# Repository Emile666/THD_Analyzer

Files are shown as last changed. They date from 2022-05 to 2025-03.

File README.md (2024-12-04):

# Bob Cordell's THD Analyzer
Bob Cordell created a series of articles in Audio Magazine, from July to September 1981 (!). In these articles, he described
in detail how to build a Total Harmonic Distortion (THD) Analyzer. I first heard of Bob Cordell, when I bought his book called "Designing Audio Power Amplifiers". 
I have never seen such an excellent written book about designing audio power amplifiers before, especially the first few chapters on continually improving a basic design 
to a high-end audio amplifier impressed me. I used the knowledge gained from his book as a base for teaching analog electronics for 3rd grade students Electrical Engineering.

I was also deeply impressed by the wealth of information in these articles and decided to build such a THD Analyzer myself. Bob
used some custom made switches with lots of decks to do the actual switching. Over the years I managed to find and construct these
switches, made some custom PCBs, created a nice front-end display and had my way of creating an implementation. As of today, this is
still work in progress.

Meanwhile, I decided to build another version of this THD Analyzer, which you will find on this page. It is the same
THD Analyzer, but now controlled by relays and a STM8S105C6 microcontroller. Such an implementation was discussed on the diyaudio forum
where someone called Giulianodes created another version where you would still need switches, but most switching was now done by relays.

His PCBs were very helpful in constructing this version of the THD Analyzer. Most ideas here are not mine, but originated from Bob Cordell
and from Giulianodes' PCB implementation.

I wanted to construct a THD Analyzer that was completely digital, while maintaining the original quality from Bob's design. 
I wanted 7-segment displays (SSD) for voltages, frequency and distortion (instead of an analog meter).
I also wanted to control all settings with keys and a LCD-display. I wanted an UART interface with commands, so I could do unit-testing of the boards.
And switching of all resistors and capacitors should also be done by relays. To conveniently read values from the SSDs, I also added LEDs for Hz or kHz, dB or % and Vpeak or Vrms.

In the end, I created five PCBs, one for each original PCB from Bob, one for the power-supply and one for the microcontroller itself. They are connected with flat-cable connectors.
Every PCB has the original analog design from Bob together with added relays. These relays are controlled by shift-registers, so off-board IO is very limited.
The microcontroller controls the shift-registers on every board and thus every single relay on these boards.

I decided to use the G6K-2F-Y relay for a few reasons: they are small, they are cheap and they are readily available (30 pcs for €26 on AliExpress). I also used the +12V
version, because current is limited (9.1 mA) and +12V can be made from the existing +15V DC. There are two switches present in every relay, which is very convenient.

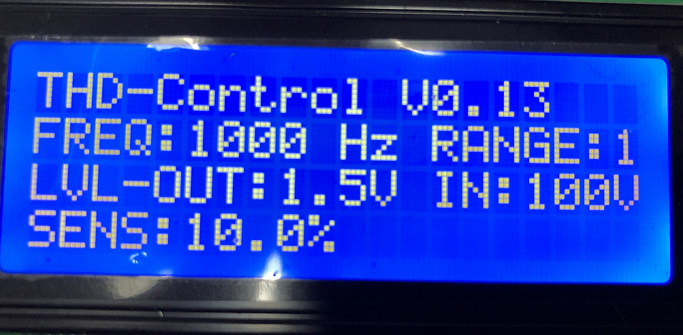
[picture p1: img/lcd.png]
LCD-Display during development testing
<br>
*LCD-Display showing actual settings*

# Features
The current PCB and firmware have the following features:
- Four Seven-Segment-Displays (SSD) displaying 1) Output Level, in peak-peak, peak or RMS voltage 2) Display of actual frequency, as measured by the microcontroller 3) Distortion level in dB or as a percentage 4) Input Level in peak-peak, peak or RMS voltage
- LCD display displaying actual settings
- Five buttons UP, DOWN, LEFT, RIGHT and OK for changing settings shown on the LCD-display. There are four more buttons for going up/down 10 frequency steps and for setting peak-peak, peak or RMS voltages and dB or percentage.
- Main output, Sync Output, Input and Distortion Output (same as in original design)
- Level Output potmeter (same as in original design)
- Four LEDs showing frequency too high/too low and input level too high/too low (same as in original design)
- All components are SMD where possible.

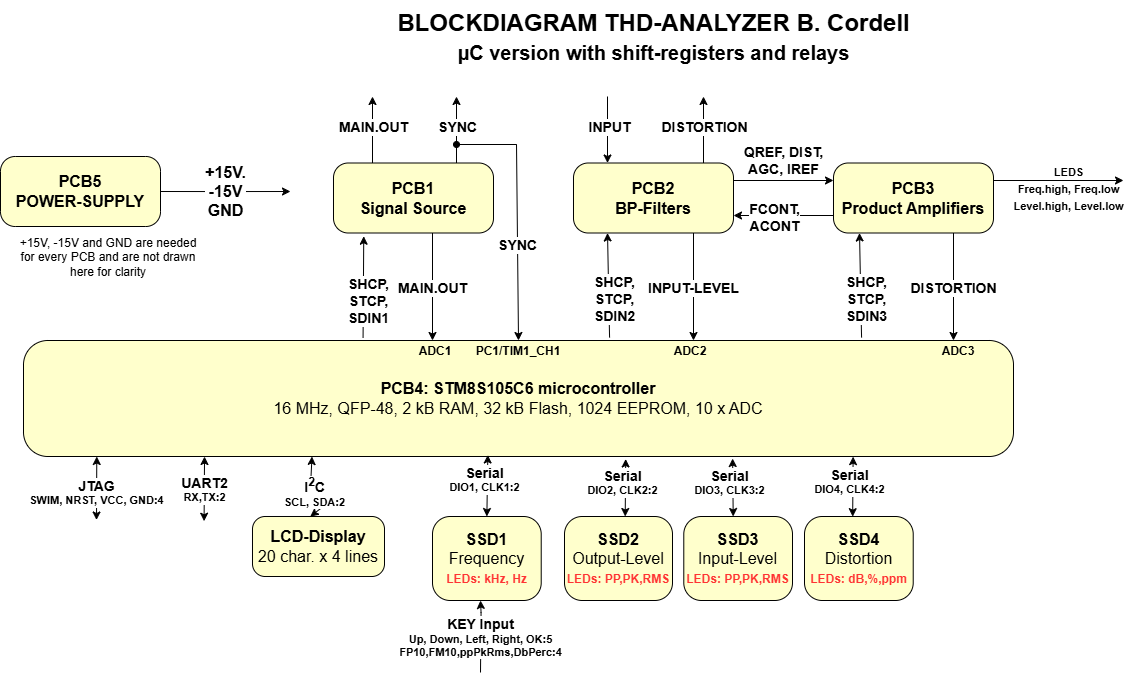
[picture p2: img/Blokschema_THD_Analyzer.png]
Block Diagram
<br>
*Block-Diagram THD-Analyzer*

A frontpanel has also been made and this is quite different from Bob's design. The LCD-display is central to the design and is surrounded by four seven-segment displays. All red-lines are hairlines and will be cut out by the laser. The frontpanel dimensions are 432 x 102 mm and is meant for a Hammond 1441-40 chassis.

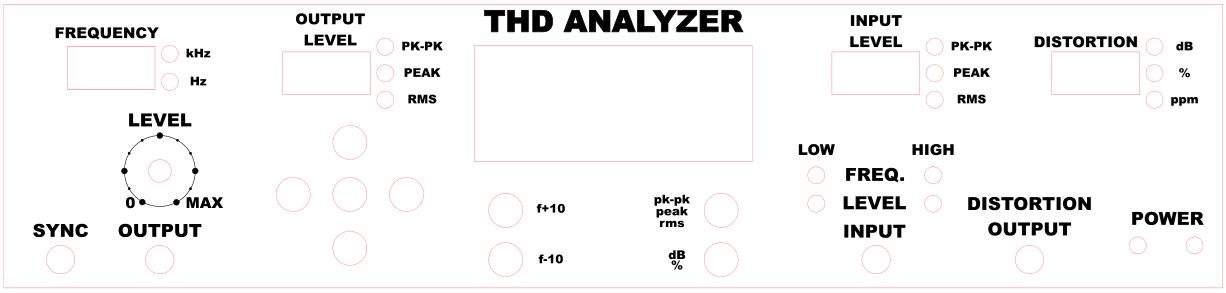
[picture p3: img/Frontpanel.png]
Frontpanel
<br>
*Frontpanel design for the THD-Analyzer*

# PCB 1: Signal Generator
This was the Signal Source PCB1 from Bob's original design. Design details and engineering design files (schematics, PCB-layout, Gerber-files) are found on the [PCB1](./pcb1.md) page.

# PCB 2: Bandpass Filters and Product Amplifier and Level Set

PCB2 contained the voltage controlled bandpass-filters and the product-amplifiers. Design details and engineering design files (schematics, PCB-layout, Gerber-files) are found on the [PCB2](./pcb2.md) page.

# PCB 3: Amplitude and Frequency Detectors and Filter and Meter circuits

PCB3 contained the Amplitude and Frequency detectors and the Filter and Meter circuits. Design details and engineering design files (schematics, PCB-layout) are found on the [PCB3](./pcb3.md) page.

# PCB 4: Microcontroller PCB
This is a newly designed PCB and was not in Bob's original design. It contains a SMT8S105 microcontroller and it is the control unit for the entire project. This board uses flat-cables to send and receive all signals from PCB1 to PCB3.

I chose the STM8S105, because I have substantial experience with these devices and they are easy to get operational, both hardware and software (especially if you have a large code-base of other projects available). The 8-bit core runs on 16 MHz and is 
powerful enough to control this project. It also has sufficient IO (I use the LQPF-48 package) for what I needed.

Design details (source-code structure, description of user-interface) and engineering design files (schematics, PCB-layout) are found on the [PCB4](./pcb4.md) page.

# PCB 5: Power-Supply
This is a newly designed PCB by bengtssk, who did a wonderful job creating a low-noise power-supply for all boards of this project.

Design details and engineering design files (schematics, PCB-layout) are found on the [PCB5](./pcb5.md) page.

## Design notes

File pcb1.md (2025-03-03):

# PCB1 Top-layer layout
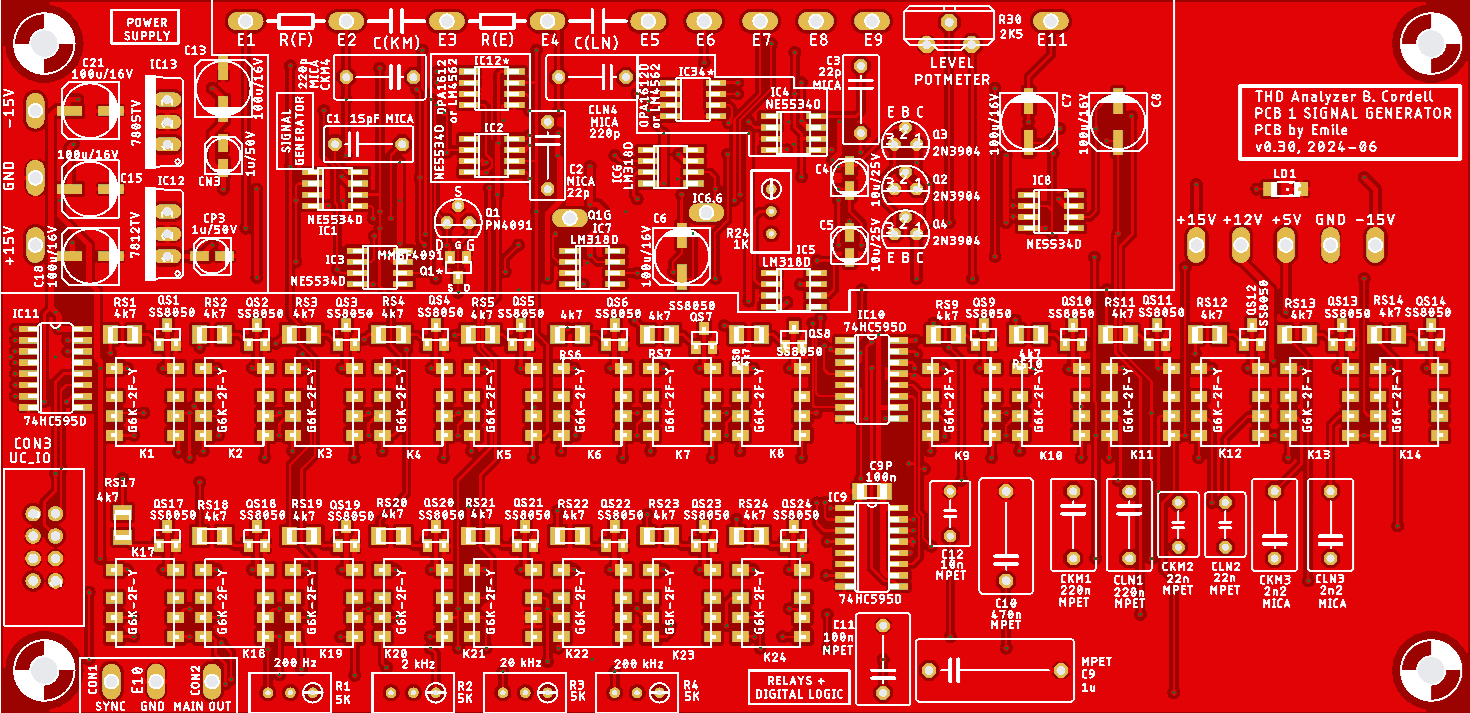
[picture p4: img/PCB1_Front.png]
PCB1 Layout top-layer
<br>
*PCB1 Top-layer Layout*

The PCBs were created with Eagle v9.3.2. The PCB itself is a double layer PCB with most components being SMD. Only a few capacitors, specified by Bob as being silver-mica or polyester, are through-hole.

# PCB1 Schematics
The schematics consists of three sheets:
- Sheet 1: the signal generator
- Sheet 2: the relays and the digital logic
- Sheet 3: the power-supply

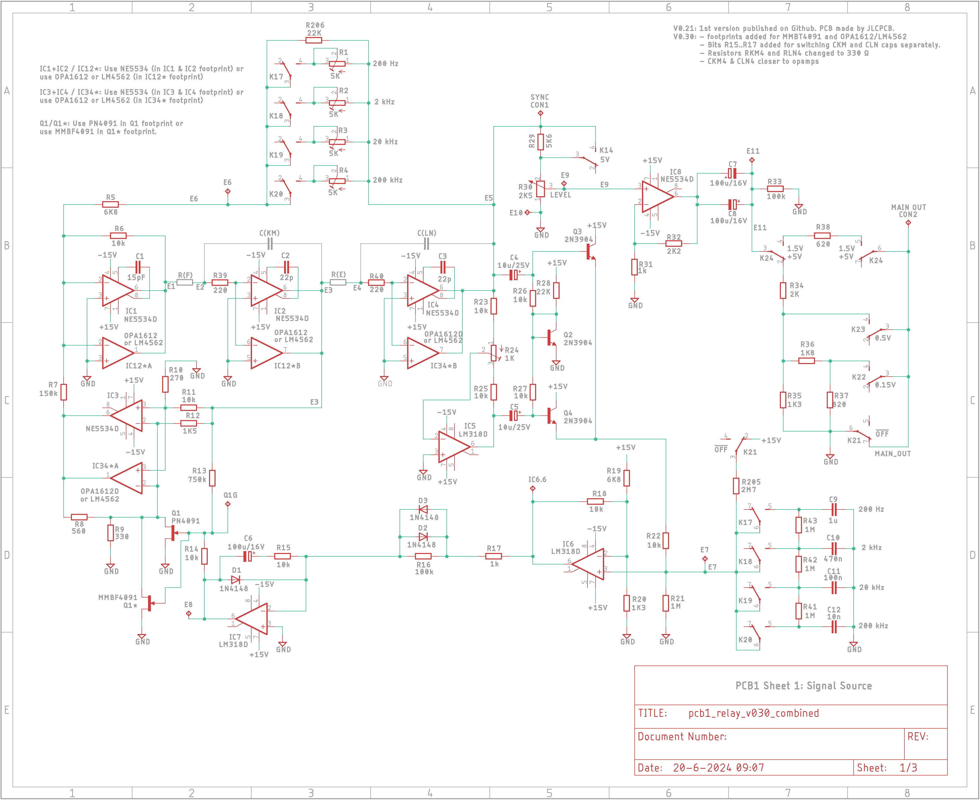
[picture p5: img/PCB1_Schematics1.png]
PCB1 Sheet 1 Schematic
<br>
*PCB1 Sheet 1: signal generator*

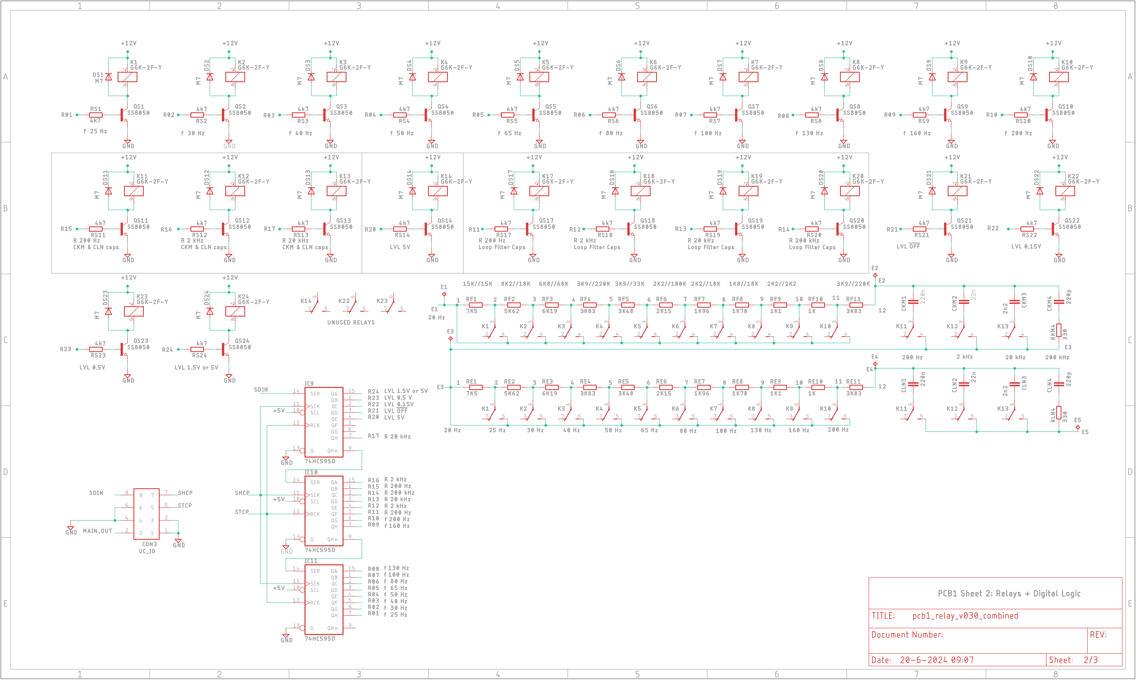
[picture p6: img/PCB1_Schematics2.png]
PCB1 Sheet 2 Schematic
<br>
*PCB1 Sheet 2: relays and digital logic*

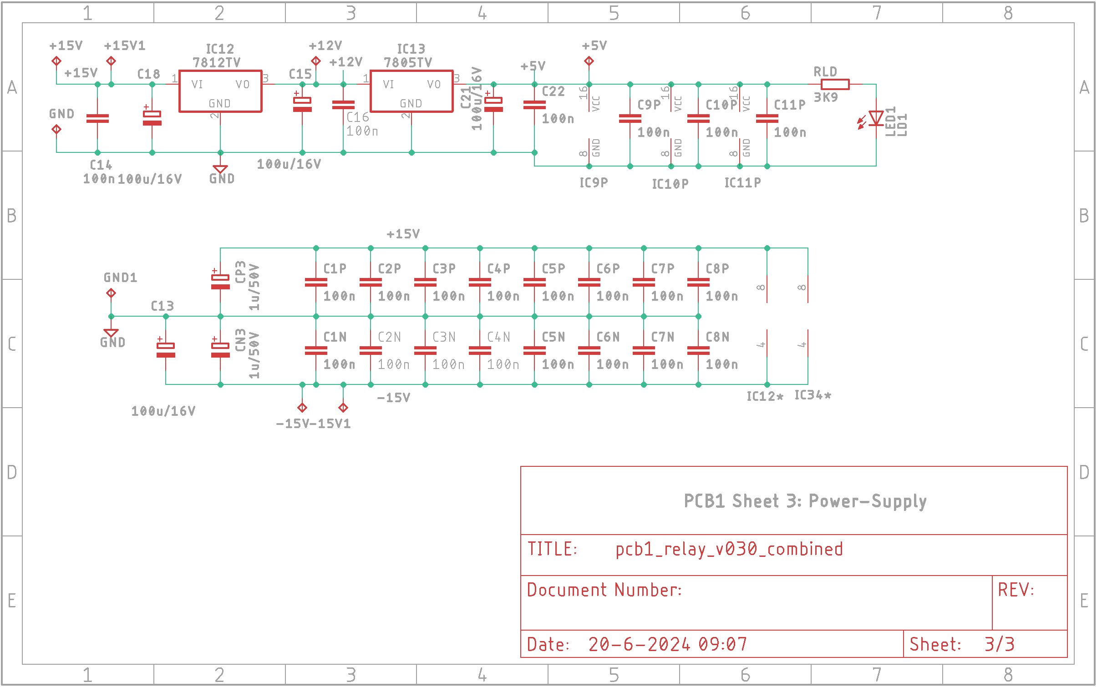
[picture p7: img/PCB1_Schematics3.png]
PCB1 Sheet 3 Schematic
<br>
*PCB1 Sheet 3: power-supply*

# Design-details
I named the bits from the HC595 shift-registers R01-R24 (R15 and R16 are not connected), with R01 being the first bit to shift into the shift-registers. They have the following meaning:
- R01: f=25 Hz to R10: f=200 Hz. For f=20 Hz all bits (R01-R10) need to be 0.
- R11: Range = 200 Hz, R12: Range = 2 kHz, R13: Range is 20 kHz. R14: Range is 200 kHz.
- PCB1 V0.30 only: R15: Range = 200 Hz, R16: Range = 2 kHz, R17: Range is 20 kHz.
- PCB1 V0.21 only: R15 until R19: these bits are not used.
- PCB1 V0.30 only: R18 and R19 are not used.
- R20: Output Level is 5 V.
- R21: Output Level if not OFF.
- R22: Output Level is 0.15 V.
- R23: Output Level is 0.5 V.
- R24: Output Level is 1.5 V or 5 V.

The MAIN.OUT signal is also sent to the microcontroller (via CON3) for both frequency and level measurement.

# SYNC MOD
This modification applies to PCB1 v0.30. The frequency-counter (a software function) gets its signal from an amplified sine-wave. This does work, but reliability is higher when the SYNC signal is used for this. The SYNC signal comes from this PCB and is sent to the uC PCB (PCB4) via CON3.

For PCB1, do the following:
- Desolder CON3 (UC_IO) box-header
- Use a sharp knife to disconnect pin 1 (bottom right pin as seen from top-layer) from GND on top-layer. There are 3 connections to GND, remove all three of them.
- Same for the 3 connections to GND on the bottom-layer.
- Check for discontinuity between GND and CON3-1 pin.
- Solder CON3 box-header back.
- Solder wire from CON1-SYNC pin to CON3-1.
- Check for discontinuity between GND and CON3-1 pin.
- In order for this mod to work, check the SYNC MOD paragraph on PCB4 too.

# PCB1 Unit-testing
Bob describes some bench-testing in his article. Since the PCB is now tested slightly different from Bob's original article, I created unit-test documents that use the microcontroller board (PCB4). This unit-test facilitates testing of PCB1. I have added both the unit-test document itself as well as a filled-in version of a test I performed. This is a good reference if you do your own unit-testing.

[PCB1 Unit-Test description](img/PCB1_Unit_Test.pdf)<br>

[PCB1 Unit-Test description filled-in](img/PCB1_Unit_Test_filled_in.pdf)<br>

In order to test this, a working PCB4 (µC control board) is needed. PCB4 should be connected to a host-PC with an USB-to-UART adapter, communication settings are 57600,N,8,1. See the [PCB4](./pcb4.md) page for details.

# Eagle source-files
Not to be used for commercial purposes!
This is the .zip file containing the Eagle source-files: [PCB1 Eagle Files](img/PCB1_Eagle.zip)

# Gerber-Files
This is the .zip file containing the Gerber files that were sent to JLCPCB: [PCB1 Gerber Files](img/pcb1_relay_v030_combined_2024-07-10.zip)

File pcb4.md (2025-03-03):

# PCB4 Engineering Design Files
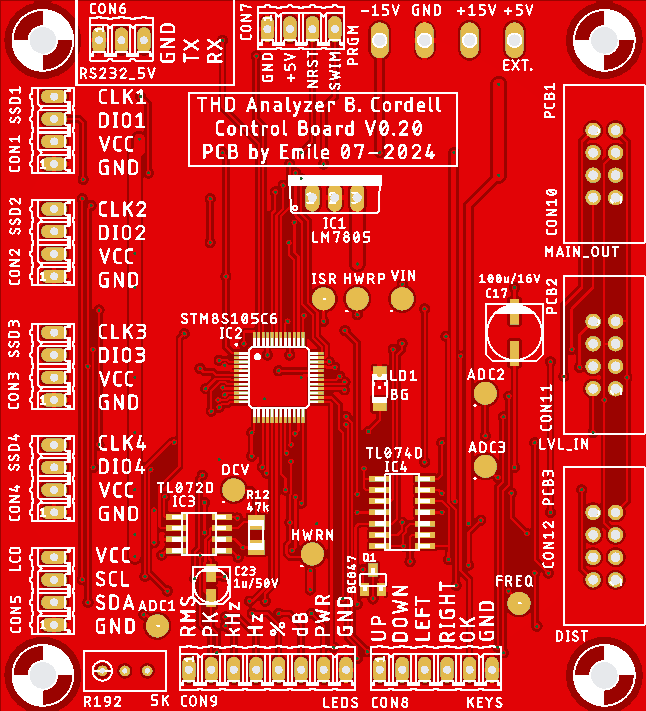
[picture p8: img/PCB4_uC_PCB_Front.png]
PCB4 Layout top-layer
<br>
*PCB4 Top-layer Layout*

The PCBs were created with Eagle v9.3.2.

# PCB4 Schematics
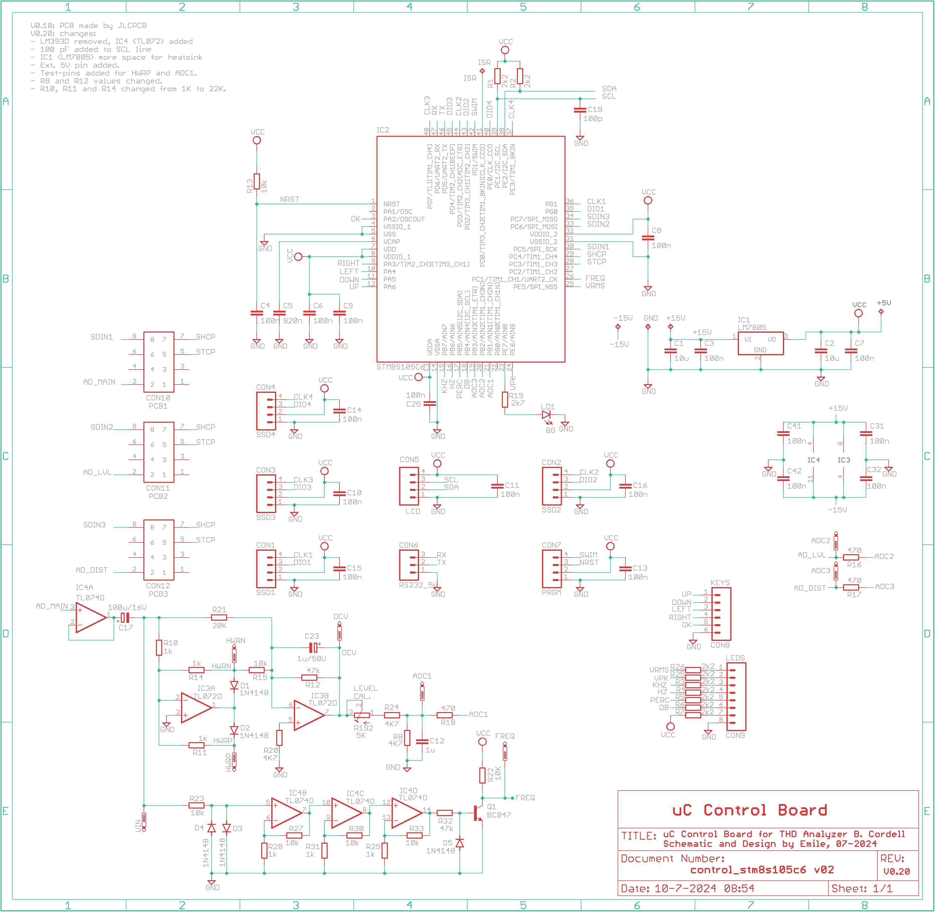
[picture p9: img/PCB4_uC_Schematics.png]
PCB4 Schematics
<br>
*PCB4 microcontroller Control-Board Schematics*

The PCB itself is a double layer PCB with most components being SMD. Some details:
- CON1, CON2, CON3 and CON4 are screw terminal-blocks for the Seven Segment Displays (SSD). CON1 shows the selected frequency, CON2 the selected output level (OFF, 0.15V, 0.5V, 1.5V and 5V), CON3 the selected distortion level (0.003%, 0.01%, 0.03%, 0.1%, 0.3%, 1%, 3% and 10%) and CON4 the selected input level (1V, 3V, 10V, 30V and 100V).
- CON5 is also a screw terminal-block, but for the I2C LCD-Display.
- CON6 is the UART interface. Note that signal levels are 5 V.
- CON7 is the JTAG programming interface, that needs to be connected to an ST-Link V2 USB adapter (see below) in order to program the microcontroller.
- CON8 contains the input key connections.
- CON9 contains all LED connections for the front-panel.
- CON10, CON11 and CON12 are flat-cable connectors that interface with PCB1, PCB2 and PCB3 respectively. They contain the signals for the shift-registers and the analog signals MAIN.OUT, DIST and LEVEL.

# Design-details
This PCB more or less copies the full-wave precision rectifier as found on PCB3. I wanted to have the MAIN.OUT signal from PCB1 measured in both amplitude and frequency. The amplitude is rectified to a DC-level and sent to ADC1, the
frequency is measured by amplifying the sine-wave into a square-wave and then send it to a timer-input (TIM1_CH1) to capture the period-time.

# SYNC MOD
This modification applies to PCB4 v0.20. The frequency-counter (a software function) gets its signal from an amplified sine-wave. This does work, but reliability is higher when the SYNC signal is used for this. The SYNC signal comes from PCB1 (and needs a modification too!) via CON3.

For PCB4, do the following:
- Desolder IC4 pin 14 from its pad and lift it up.
- Solder a wire from CON10-1 (bottom right pin as seen from top-layer, pin next to AD_MAIN pin) to R33 pad next to R32. R32 and R33 are located next to each other, solder the wire to one of the pads in the middle.
- In order for this mod to work, check the SYNC MOD paragraph on PCB1 too.

### GPIO
The GPIO pin lay-out as shown in the schematic is copied in the header-file stm8_hw_init.h and used throughout the project. GPIO pins are initialized in the function setup_gpio_ports() in stm8_hw_init.c.

### Peripherals
I decided not to use the internal I2C module, since it is overly complicated and troublesome to get to work. Good old bit-banging is used instead, see files i2c_bb.c and i2c_bb.h. The ADC (adc.c, adc.h), eeprom (eep.c, eep.h) and UART (uart.c, uart.h) routines are pretty standard.

The UART commands are defined in comms.c/comms.h in the function execute_single_command(). The UART functions itself are interrupt-driven and they use ringbuffers to store and retrieve communication.

### UART communications
- Use PCB4 connector 6 (CON6, RS232.5V) for serial communications to a host-PC.
- Communication settings are 57600 Baud, no parity, 8 bits, 1 stop-bit (57600,N,8,1).
- Use an USB-to-UART adapter and connect the following signals: GND to CON6_GND, TXD to CON6_RX and RDX to CON6_TX. In Windows a virtual COM port is added to the device list when this adapter is added.
- CON6 uses 5V levels, so set the USB-to-serial adapter to accept 5 Volt levels.
- Use Realterm (or any other communication program) on the host-PC for sending and receiving data to/from PCB4. Make sure that a CR and a LF are added to the command-string when sending.
- Make sure that you get a USB-to-UART adapter and not an USB-to-RS232 adapter, because voltage-levels are 0-5 Volt only (RS232 is typical +6V and -6V and will not work with CON6).

To test communications, enter the command 's0', make sure that CR and LF are sent as well and send it to the PCB4 control-board. Typically it should respond with a string like 'THD-Control V0.25'. Besides s0, the following commands are also available:
- c0 or c0 <float> with <float> being a floating-point value. The c0 parameter defines the 100 V input-level and is by default set to 32.645570, which is equal to 1+(R48/R49). If you just type c0, the currently stored value is displayed. Change this parameter to get a correct reading of the input-level on SSD3 for the 100V input setting. This value is stored in eeprom, so the value remains set after a power-cycle.
- c1 or c1 <float>: same as c0 but for the 30V input-level reading. Equal to 1+(R46/R47).
- c2 or c2 <float>: same as c0 but for the 10V input-level reading. Equal to 1+(R44/R45).
- c3 or c3 <float>: same as c0 but for the 3V input-level reading. Equal to 1.0, because this is a pass-through.
- c4 or c4 <float>: same as c0 but for the 1V input-level reading. Equal to R51/(R51+R52).
- a0, a1 or a2: set amplitude-level to Vrms (a0), Vpeak (a1) or Vpp (a2).

### Scheduler
Furthermore, the scheduler (scheduler.c, scheduler.h) takes care of proper timing for all tasks. The add_task() routine controls timing of every task and is called from main() in THD_Analyzer_main.c. There are three tasks defined:
- adc_task(), name "ADC", called every 500 msec. This task reads the analog values from the AD-converters and stores the information on the SSDs.
- freq_task(), name "FRQ", called every 200 msec. This task calculates the actual frequency of the generated sine-wave and updates information on the LCD-display.
- ctrl_task(), name "CTL", called every 100 msec. This task reads the input-buttons and runs the state-machine. The state-machine is used to adjust settings.

### Keys
There are five keys that should be connected to CON8 (KEYS) of the uC PCB. These keys are UP, DOWN, LEFT, RIGHT and OK and are used for navigating the menu in the LCD-display.

With the start of firmware revision V0.25, it is also possible to connect these keys to connector J2 of the first TM1637 seven-segment display (the one that shows the actual frequency). Both connectors are read in by the software and if either one of these connectors show a key-press, it is handled as such. 

There are four additional keys on the frontpanel: f+10, f-10, pppkrms and dbperc, they can only be connected to connector J2 of the first TM1637 seven-segment display. They increase (fp10) or decrease (fm10) the frequency in 10-steps, they change the amplitude readings to peak-peak, peak or RMS (pppkrms) or they change the distortion unity to dB or a percentage (dbperc).

The keys should be connected to SSD connector J2 as follows:
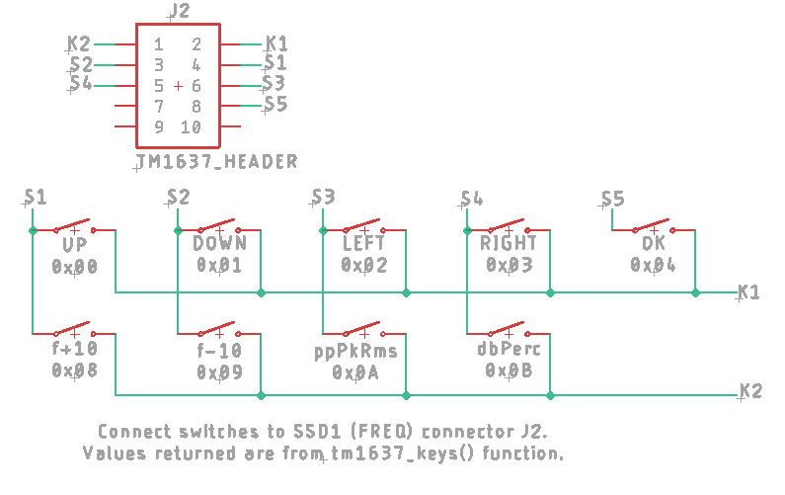
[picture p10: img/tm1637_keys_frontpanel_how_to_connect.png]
Frontpanel key connections
<br>
*How to connect the frontpanel keys*

### LCD-Display
There are separate files (i2c_lcd.c, i2c_lcd.h) for the LCD-display functions. These functions call the actual I2C-routines from i2c_bb.c/i2c_bb.h. The seven-segment display routines are listed in tm1637.c/tm1637.h.

The second, third and fourth line of the LCD-display contain the actual settings (frequency, output-level, input-level and sensitivity). They can be changed with the buttons as follows:
- UP and DOWN button are used to select a higher/lower frequency. There's is no roll-over so trying to select a lower frequency than 20 Hz keeps the frequency at 20 Hz. Same for the 200 kHz setting: trying to select a higher frequency keeps the frequency set at 200 kHz.
- LEFT and RIGHT button are used to select the various settings. The selected setting is shown on the first line of the LCD-display. You can than use the UP and DOWN buttons to change values. A value change is immediate.
- OK button brings up the parameter menu. You can change amplitude (Vpeak or Vrms) and the unit of distortion (dB or percentage). Note that this can also be done directly (from V0.25 onwards) with the keys on the frontpanel. Other parameter changes are to be defined.

### Seven-Segment Displays (SSD)
There are a total of four SSDs present in the system. The first SSD shows the actual frequency and is also used to read in a number of keys. There are separate PCBs created for the SSDs to provide better power-supply decoupling and to add a number of LEDs right next to the display. A connector is also added to connect keys to.

The seven-segment display routines are listed in tm1637.c/tm1637.h.

Bengtssk made a nice PCB for these SSDs, design details are given on the [SSD](./SSD.md) page.

# Eagle source-files
Not to be used for commercial purposes!
This is the .zip file containing the Eagle source-files: [PCB4 Eagle Files](img/PCB4_Eagle.zip)

# Gerber-Files
This is the .zip file containing the Gerber files that were sent to JLCPCB: [PCB4 Gerber Files](img/control_stm8s105c6 v02_2024-07-10.zip)

# Programming the microcontroller
To start with, you'd need one of those fancy coloured ST-Link V2 USB adapters (which are very cheap to find on ebay/Aliexpress). 
 
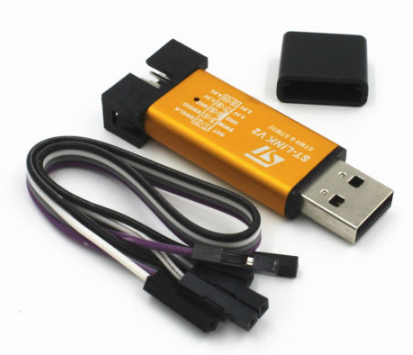
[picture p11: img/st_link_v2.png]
st-link-v2
<br>
*The ST-Link V2 USB adapter*

Power PCB4 from a ±15V dual power-supply and connect the ST-Link USB adapter without the VCC line (only SWIM, NRST and GND). Now, there are several options to program the microcontroller:

1) Use ST Visual Programmer (STVP-STM8), this can be downloaded for free. A project file for STVP is included [here](./Debug/Exe/THD_Analyzer_stm8s105.stp).

2) Use the opensource tool stm8flash.

3) Use opensource tools Code::Blocks in combination with the SDCC C compiler. A Code::Blocks project file is present (THD_Analyzer_stm8s105.cbp) that loads the entire project. You probably only need to set the SDCC home directory in Settings->Compiler..., then select Small Device C Compiler in the selected compiler field, then click Toolchain executables, then enter the compiler's installation directory and do a 'Auto-detect'. I suggest to install SDCC first and then install Code::Blocks. The toolchain creates a .hex file in Debug\ExeCB which can be uploaded with either stm8flash (preferred for Unix platforms) or STVP (on Windows).

4) Use the IAR development environment for STM8 from the IAR website. A 14-day free trial version is available.
- Open the workspace in IAR (File -> Open -> Workspace... -> THD_Analyzer_stm8s105.eww), then do a Project -> Rebuild All.
- There is a preprocessor define (USE_IAR_HEADER_FILE) that can be defined in Project->Options->C/C++ Compiler. If defined, the standard header file (<iostm8s105.h>) is used. If not defined, the file stm8s105.h is used.
- Press Ctrl-D. This opens the debugger and transfers the code to the microcontroller. 
- Press Ctrl-Shift-D to Stop Debugging. Remove the wires, re-cycle power and you are good to go!

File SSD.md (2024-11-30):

# SSD modules for displays and key scan
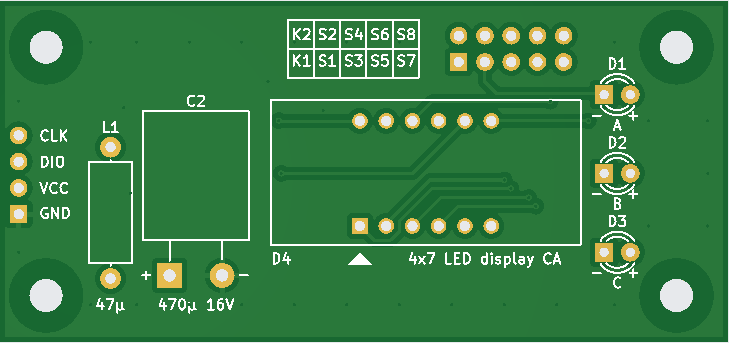
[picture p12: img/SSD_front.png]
SSD module PCB front layer
<br>
*SSD PCB front layer*

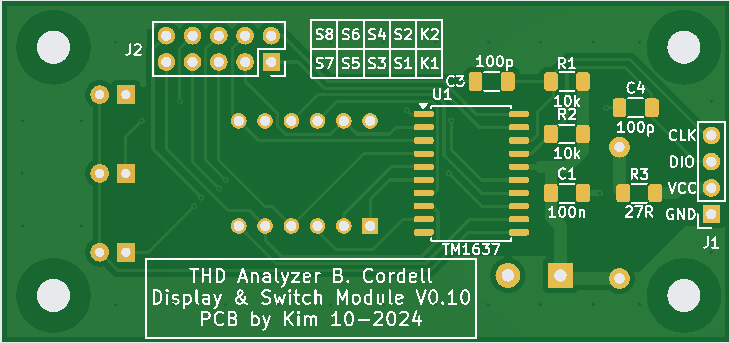
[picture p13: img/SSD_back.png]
<br>
*SSD PCB back layer*

The PCB was created using KiCad v8.0. It is a double sided PCB with a 4 digit 7-segment LED display at the front and TM1637 IC at the back. A ground-plane is used to minimize EMI transmissions from the board. Connectors J1 and J2 can be mounted on either side, depending what is most convenient. Same for the 470 µF cap, if you use a low-voltage radial cap and lay it down, it even has lower height than a SMD cap.

# SSD module Schematic
[SSD module schematic](img/SSD_schematic.pdf)<br>
*SSD module schematic*

# Design-details
In the beginning of this project it was discovered that the SSD modules caused switching spikes at the +5V rail from the multiplexing of the LED displays. These voltages spikes did not only cause the frequency counter to malfunction, but also increased the residual distortion, making the whole instrument useless.

The original SSD modules from Ali-Express comes with only 2 µF decoupling for the TM1637 IC, while the datasheet suggests 100 µF. But even that is too low. Instead of just a capacitor, a LC-filter was added to each SSD module with good results. In order to minimize EMI being transmitted from the board or its power cables, the filter should be placed as close to the TM1637 as possible. A new PCB was designed for this purpose.

Component values of the LC filter are not very critical, the values were determined by experiment. The series resistor improves the performance significantly.

Indicator LEDs for Hz, kHz etc. are now included on the board (LED A, B and C) and controlled by the TM1637 as well. Note that some boards only use LED's A and C. In this case do not populate LED B.

Since the TM1637 also features a key scan option, connector J2 was added for connecting keys. See the [Keys](./pcb4.md#Keys) section in [PCB4](./pcb4.md) on how to connect keys to this connector.

# Gerbers
This zip-file contains Gerbers to be sent for manufacturing:  [SSD Gerber Files](img/SSD-gerbers.zip)

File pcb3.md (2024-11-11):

# PCB3 Engineering Design Files
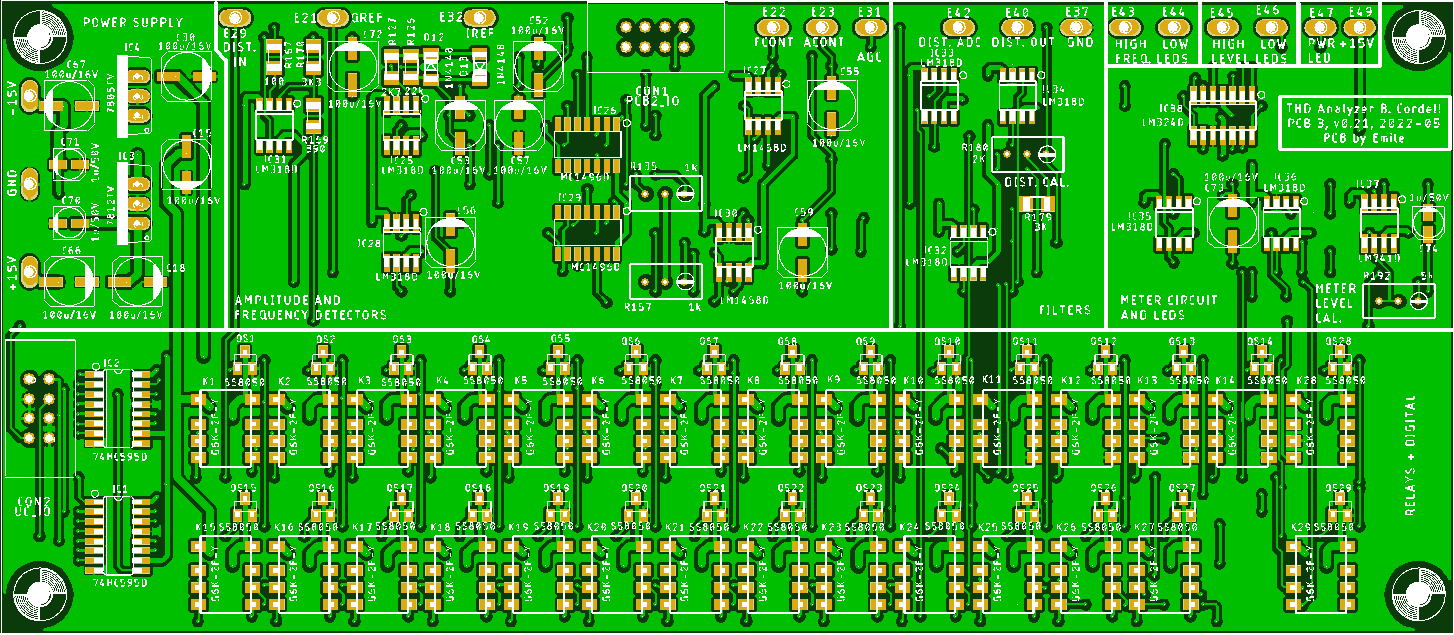
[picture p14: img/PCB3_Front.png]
PCB3 Layout top-layer
<br>
*PCB3 Top-layer Layout*

The PCBs were created with Eagle v9.3.2. The PCB itself is a double layer PCB with most components being SMD. Only a few capacitors, specified by Bob as being silver-mica or polyester, are through-hole.

# PCB3 Schematics
The schematics consists of five sheets:
- Sheet 1: the amplitude and frequency detectors
- Sheet 2: the meter and LED interface
- Sheet 3: the relays and the digital logic
- Sheet 4: the filter-circuit
- Sheet 5: the power-supply

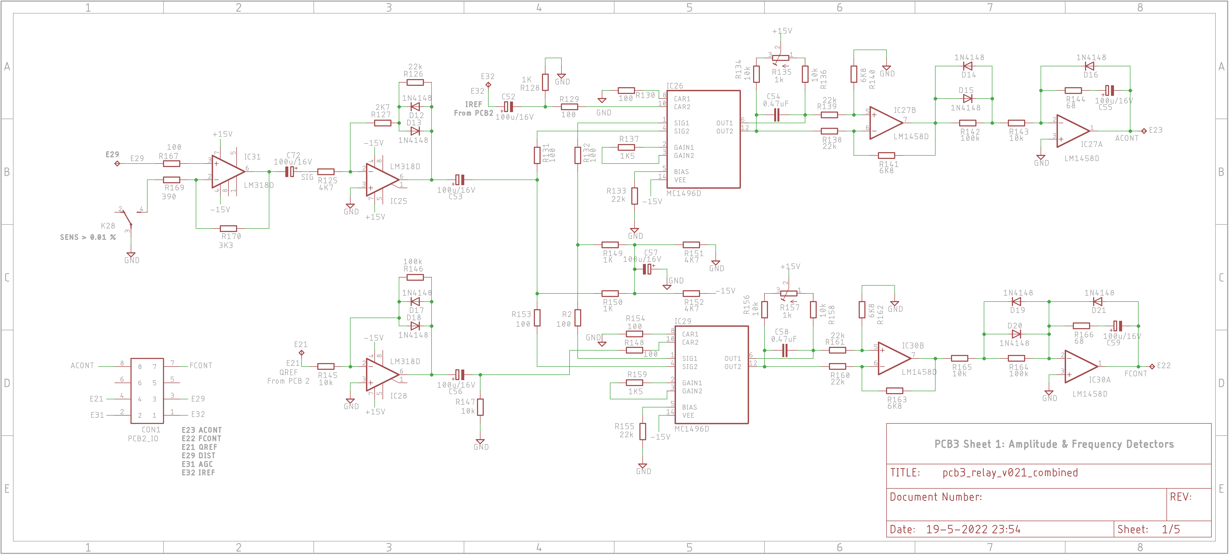
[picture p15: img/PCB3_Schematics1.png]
PCB3 Sheet 1 Schematic
<br>
*PCB3 Sheet 1: amplitude and frequency detectors*

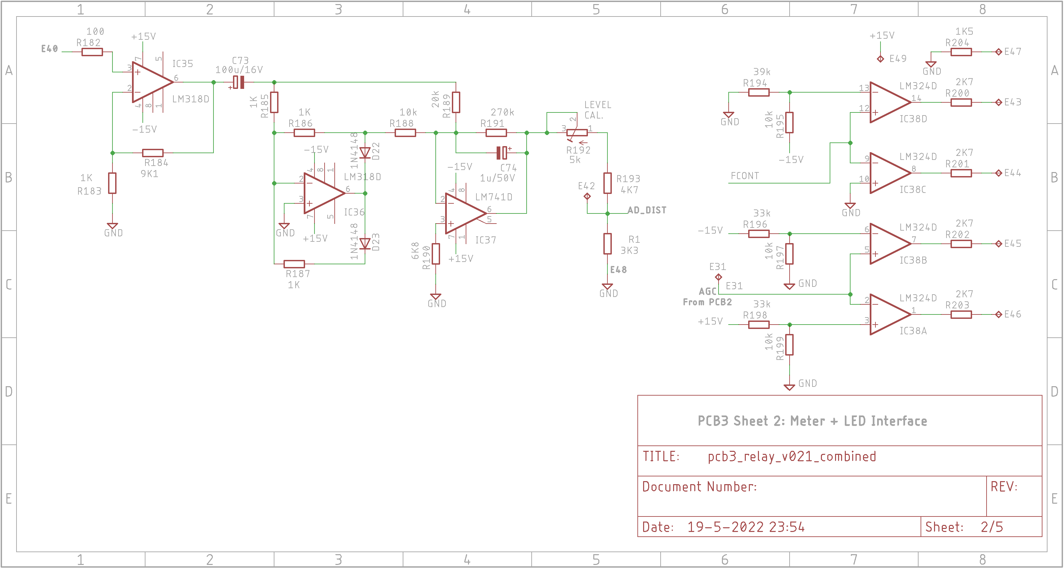
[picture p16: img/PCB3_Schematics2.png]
PCB3 Sheet 2 Schematic
<br>
*PCB3 Sheet 2: meter and LED interface*

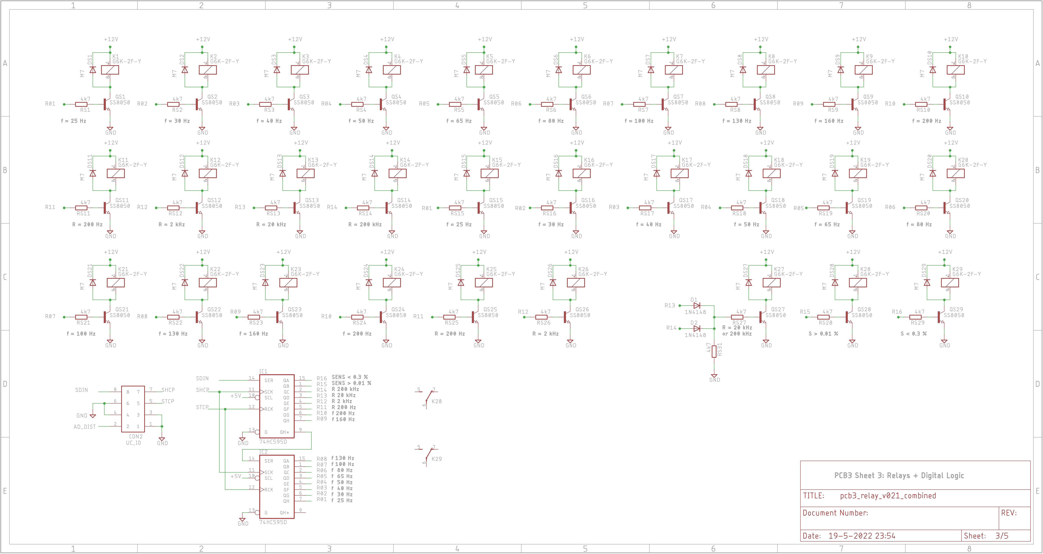
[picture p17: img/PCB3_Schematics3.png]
PCB3 Sheet 3 Schematic
<br>
*PCB3 Sheet 3: relays and digital logic*

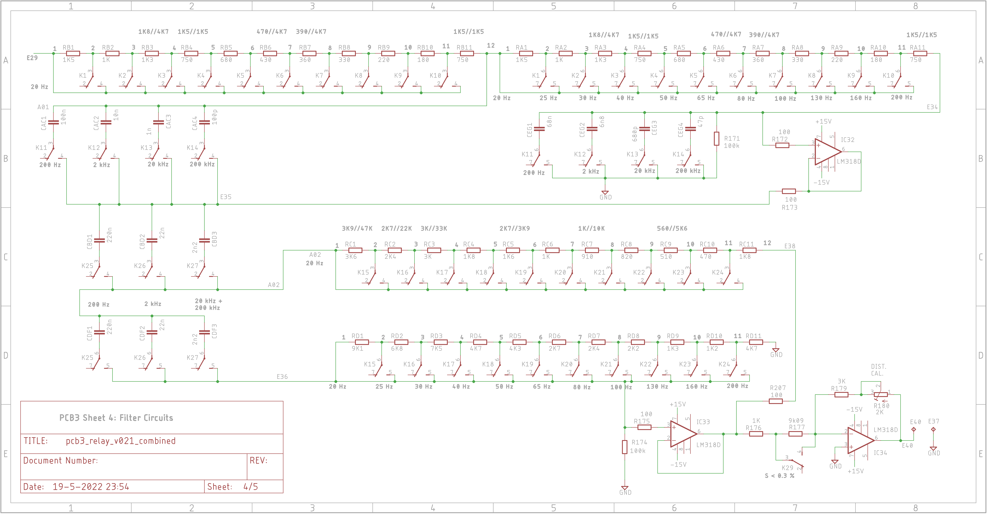
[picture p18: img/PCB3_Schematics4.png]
PCB3 Sheet 4 Schematic
<br>
*PCB3 Sheet 4: Filter-circuit*

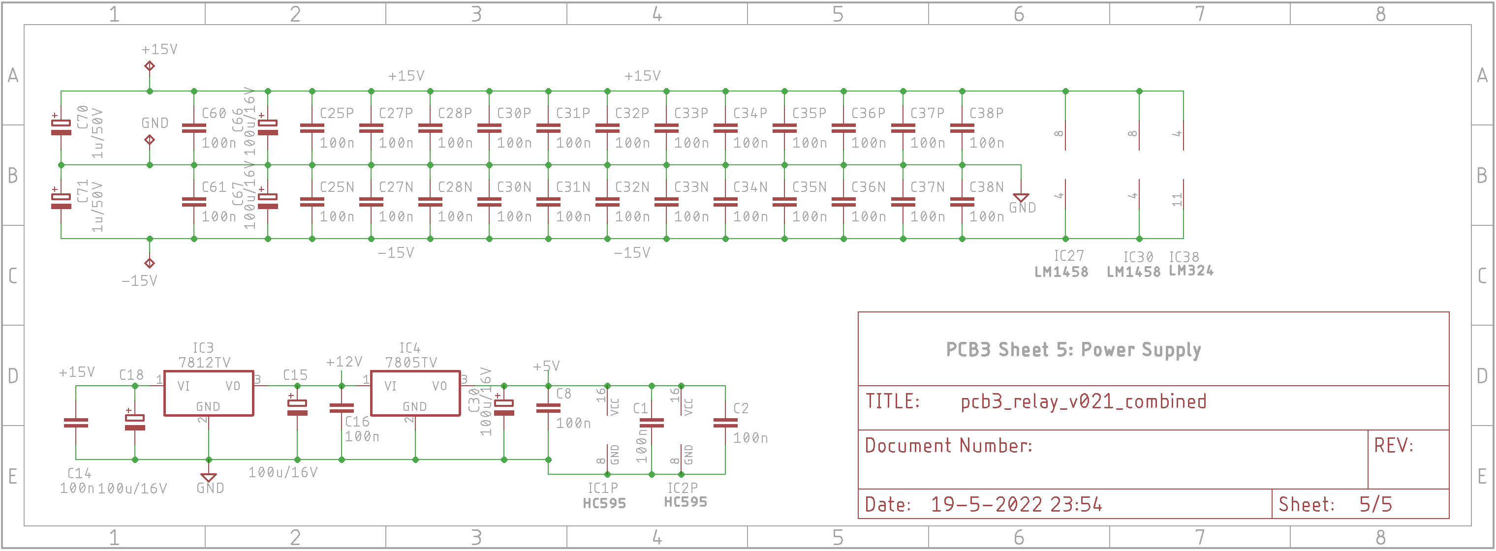
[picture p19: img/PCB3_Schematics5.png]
PCB3 Sheet 5 Schematic
<br>
*PCB3 Sheet 5: power-supply*

# Design-details
I named the bits from the HC595 shift-registers R01-R16, with R01 being the first bit to shift into the shift-registers. They have the following meaning:
- R01: f=25 Hz to R10: f=200 Hz. For f=20 Hz all bits need to be 0.
- R11: Range = 200 Hz, R12: Range = 2 kHz, R13: Range is 20 kHz, R14: Range is 200 kHz.
- R15: Sensitivity > 0.01 %. This replaces switch S5C.
- R16: Sensitivity < 0.3 %. This replaces switch S5D.

Because of the filters, there's substantial switching of resistors and capacitors. So most shift-register bits are sent to multiple relays. For example: Bit R04 (f = 50 Hz) controls both relay K4 and K18. Every relays switches 2 resistors.

# Unit-Test (CP3 Bench-test)
Bob describes some bench-testing in his article. Since the PCB is now tested slightly different from Bob's original article, I created unit-test documents that use the microcontroller board (PCB4). This unit-test facilitates testing of PCB3. I have added both the unit-test document itself as well as a filled-in version of a test I performed. This is a good reference if you do your own unit-testing.

[PCB3 Unit-Test description](img/PCB3_Unit_Test.pdf)<br>

[PCB3 Unit-Test description filled-in](img/PCB3_Unit_Test_filled_in.pdf)<br>

# Eagle source-files
Not to be used for commercial purposes!
This is the .zip file containing the Eagle source-files: [PCB3 Eagle Files](img/PCB3_Eagle.zip)

# Gerber-Files
This is the .zip file containing the Gerber files that were sent to JLCPCB: [PCB3 Gerber Files](img/pcb3_relay_v021_combined_2022-05-20.zip)

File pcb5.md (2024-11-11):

# PCB5 PSU for the THD analyzer
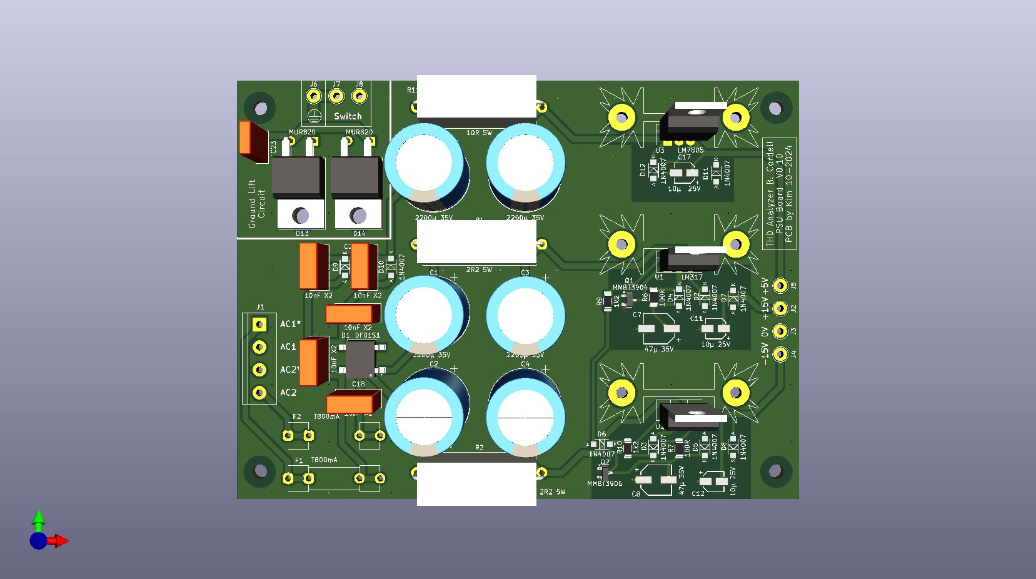
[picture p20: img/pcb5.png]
PCB5 3D-view
<br>
*PCB5 3D-view from top layer*
The PCB was created using KiCad v8.0. It is a double sided PCB with most of the components at the top side. SMD components were used whenever is was practical. Heat sinks for the voltage regulators are mounted at the board. They produce some heat, hence the generous spacing between them.

# PCB5 Schematic
[PCB5 schematic](img/PCB5_schematic.pdf)<br>
*PCB5 schematic*

# Design-details
The design is a common linear power supply. A full wave rectifier (D1) is used for the +15V and -15V rails. The DC voltage are smoothed by capacitor C1 and C2. The RC filter constituting of R2, C3 (and R2, C4) removes more hum.

Adjustable linear voltage regulators (U1 and U2) are used to provide +15V and -15V. A mutual shut-off circuit consisting of Q1, Q2, D6, R9 and R10. Drops the output voltage to about 1,25V if the other voltage rail would disappear. Saving all the NE5534 ships, which can be damaged if supplied from on rail only.

The +5V supply is provided by the rectifier consisting of D9 and D10, this way the both winding of the transformer are loaded equally. The DC is filter the same way as for +/-15V by C13, C14 and R11. The bigger value of R11 also drop the voltage some more before it is regulated to +5V by U3.

A ground lift circuit is also included, consisting of D13,D14 and C23. It can be bypassed by connecting switch between J7 and J8. J6 should be connected to chassis and safety ground.

### Perfomance
The PSU was bench tested with following loads;

- 400mA from +15V supply
- 200mA from -15V supply
- 220mA from +5V supply

Noise and hum <5mV. Maximum temperature of heat sinks was 55°C after 1 hour.

# Gerbers
This zip-file contains gerbers to be sent for manufacturing:  [PCB5 Gerber Files](img/PCB5-gerbers.zip)

# Construction
Following these orders of construction makes the process much easier.
- Solder all the SMD components to the board.
- Solder all the through hole components, starting with the lowest components first. – Do not mount the voltage regulators or heat sinks yet.
- Mount the voltage regulars at the heat sinks with thermal paste. Insulation between the regulator and heat sink is not needed, nor recommended since heat transfer is better without.
- Solder the heat sinks (with the regulator mounted) to the board first. A small spacer between the heat sink and board is recommended, since there are traces underneath the fins of the heat sinks.
- Lastly solder the legs of the voltage regulators to the board. Soldering the legs after mounting the regulators to the heats sinks minimizes the mechanical stress of the solder joints, thus less chance of failure due to thermal cycling.

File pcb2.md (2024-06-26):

# PCB2 Engineering Design Files
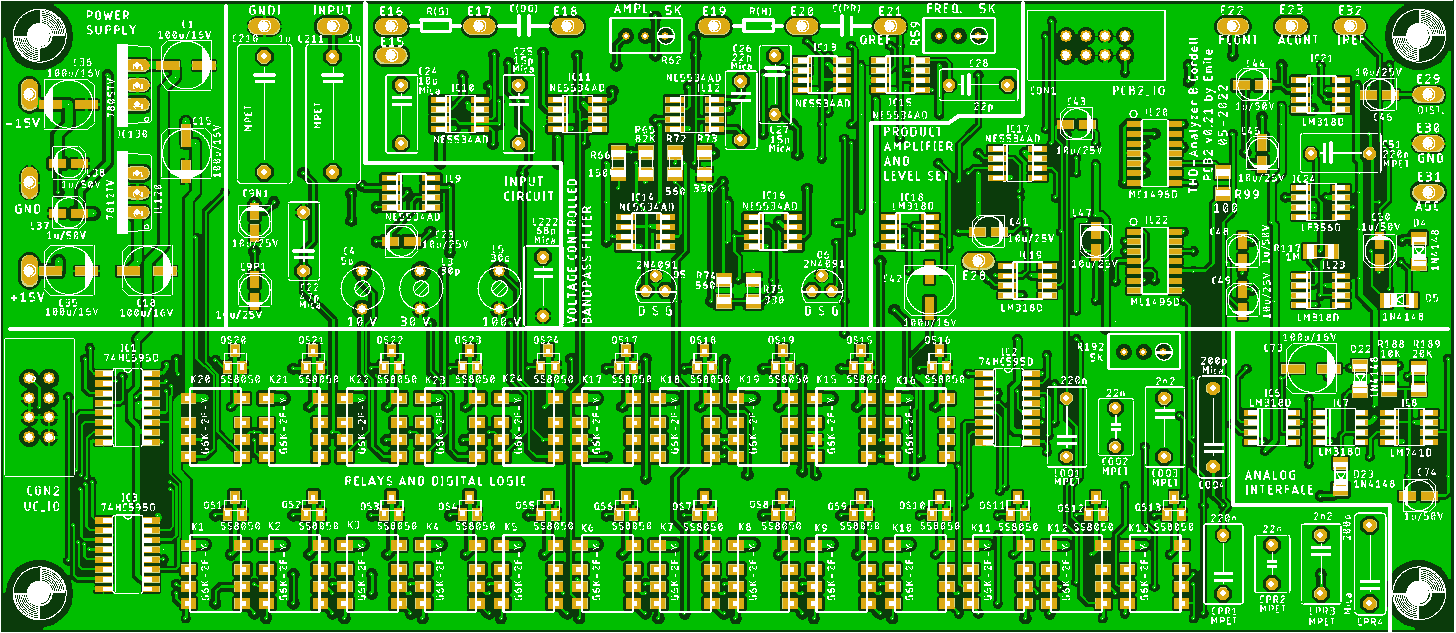
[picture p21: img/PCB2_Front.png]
PCB2 Layout top-layer
<br>
*PCB2 Top-layer Layout*

The PCBs were created with Eagle v9.3.2. The PCB itself is a double layer PCB with most components being SMD. Only a few capacitors, specified by Bob as being silver-mica or polyester, are through-hole.

# PCB2 Schematics
The schematics consists of five sheets:
- Sheet 1: the voltage controlled bandpass-filters
- Sheet 2: the product-amplifiers and level set
- Sheet 3: the relays and the digital logic
- Sheet 4: the power-supply
- Sheet 5: the analog interface

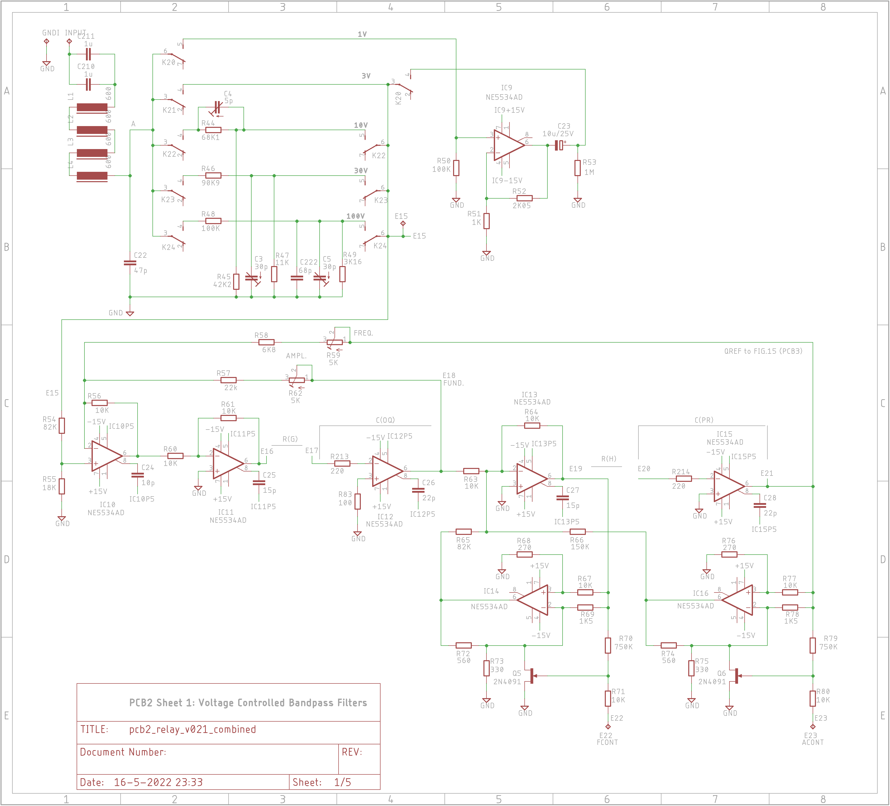
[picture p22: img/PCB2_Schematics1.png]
PCB2 Sheet 1 Schematic
<br>
*PCB2 Sheet 1: voltage controlled bandpass filters*

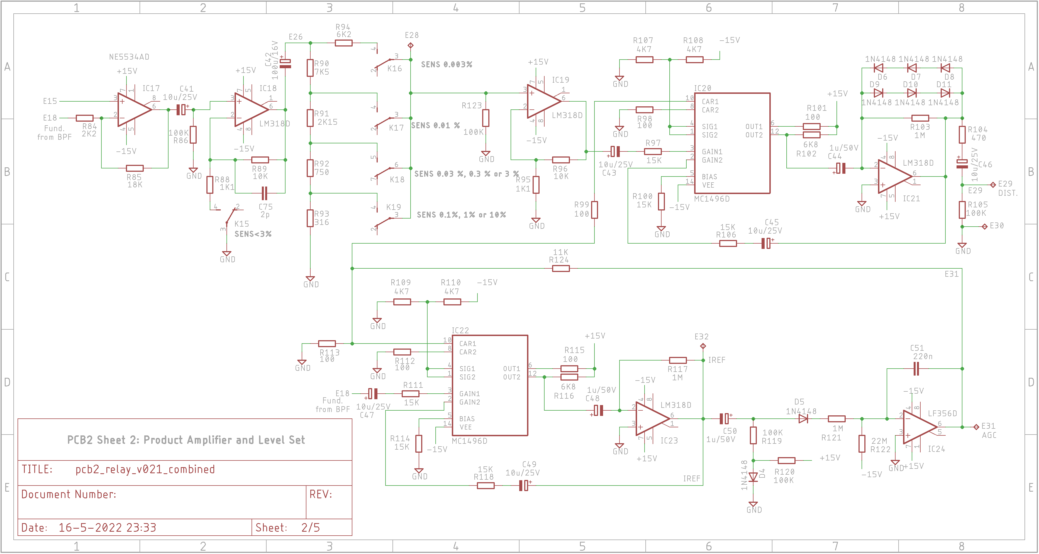
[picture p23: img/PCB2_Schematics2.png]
PCB2 Sheet 2 Schematic
<br>
*PCB2 Sheet 2: product-amplifiers and level set*

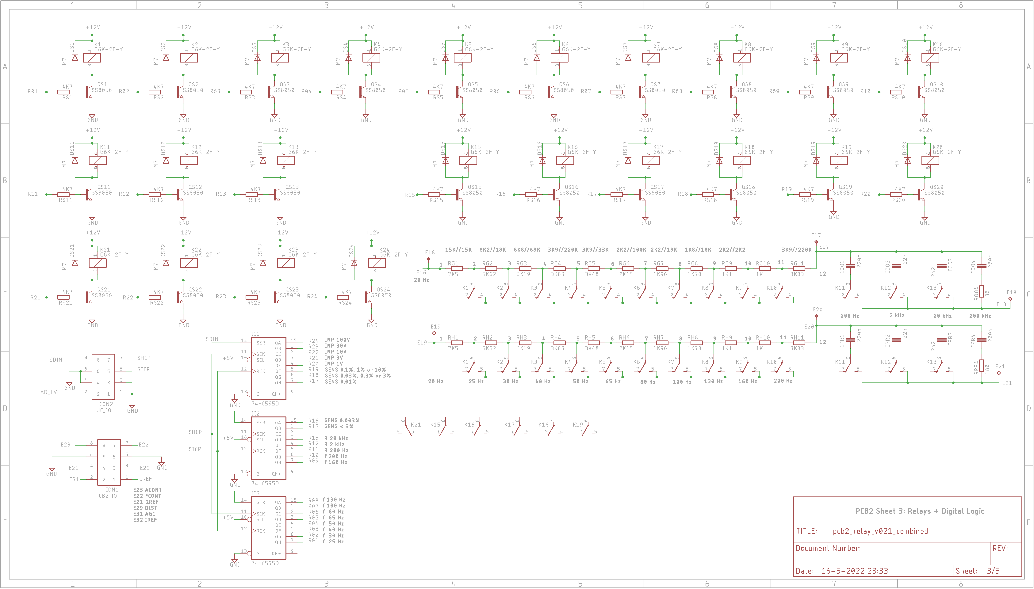
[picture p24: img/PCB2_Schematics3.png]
PCB2 Sheet 3 Schematic
<br>
*PCB2 Sheet 3: relays and digital logic*

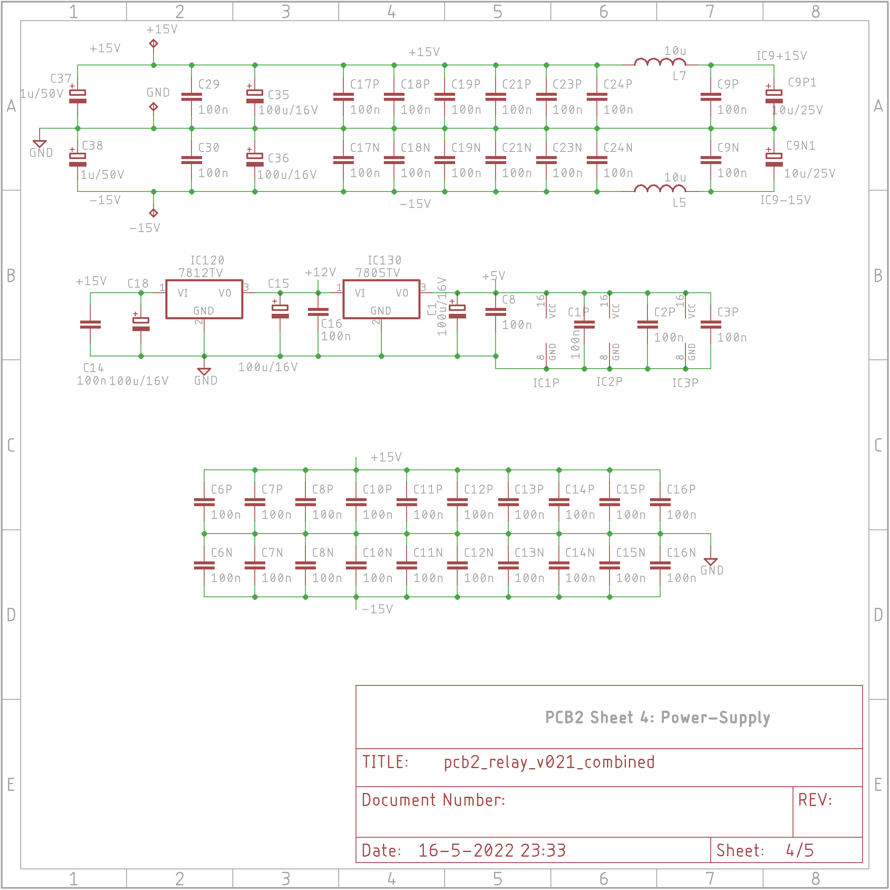
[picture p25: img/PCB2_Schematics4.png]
PCB2 Sheet 4 Schematic
<br>
*PCB2 Sheet 4: power-supply*

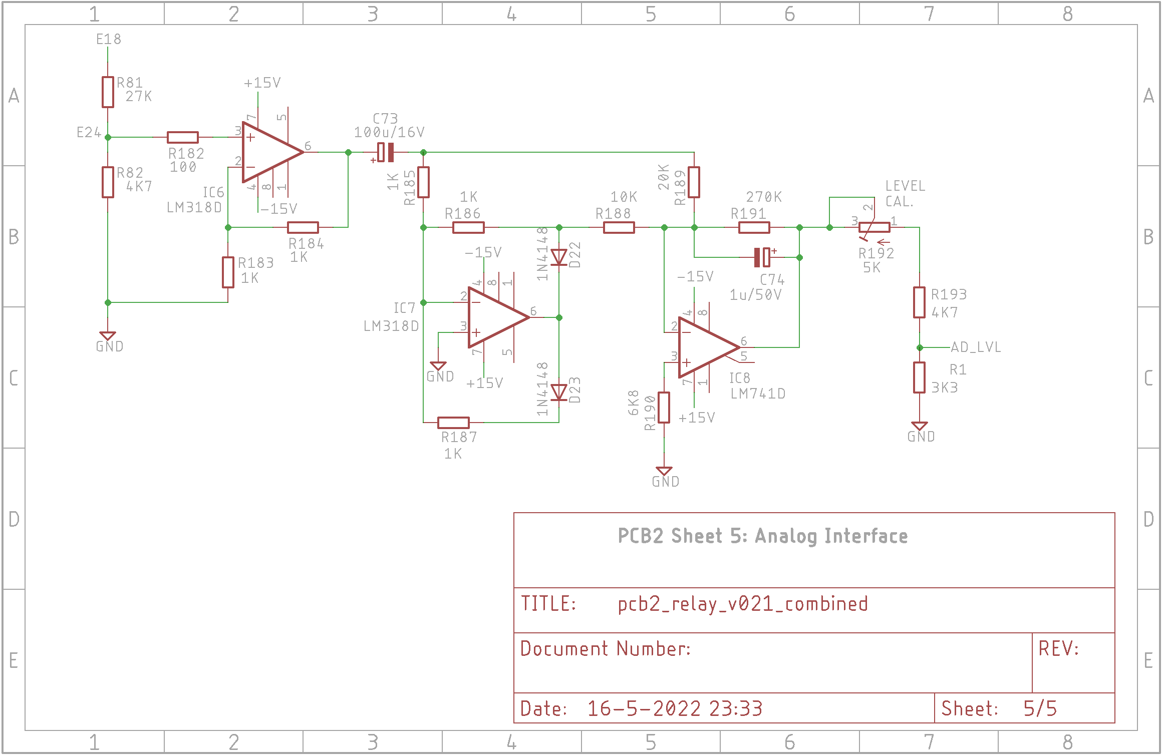
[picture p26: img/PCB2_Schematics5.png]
PCB2 Sheet 5 Schematic
<br>
*PCB2 Sheet 5: analog interface*

The PCB itself is a double layer PCB with most components being SMD. Only a few capacitors, specified by Bob as being silver-mica or polyester, are through-hole.

# Design-details
I named the bits from the HC595 shift-registers R01-R24, with R01 being the first bit to shift into the shift-registers. They have the following meaning:
- R01: f=25 Hz to R10: f=200 Hz. For f=20 Hz all bits need to be 0.
- R11: Range = 200 Hz, R12: Range = 2 kHz, R13: Range is 20 kHz. For Range = 200 kHz these bits are all 0.
- R14: This bit is not used.
- R15: Sensitivity < 3 %. This replaces the function of switch S5B
- R16: Sensitivity is 0.003 %.
- R17: Sensitivity is 0.01 %.
- R18: Sensitivity is 0.03 %, 0.3 % or 3 %.
- R19: Sensitivity is 0.1 %, 1 % or 10 %. Together with R16, R17 and R18, they replace the function of switch S5A.
- R20: Input level is 1 V.
- R21: Input level is 3 V.
- R22: Input level is 10 V.
- R23: Input level is 30 V.
- R24: Input level is 100 V. Together with R20, R21, R22 and R23, they replace the function of switch S4A and S4B.

Connector CON2 is used as interface to the microcontroller board. It contains the MAIN.OUT signal and the signals for the shift-registers (SDIN, SHCP and STCP).

PCB2 also contains connector CON1. This is used as an interface to/from PCB3. It contains the following signals: FCONT (E22), ACONT (E23), E21 (QREF), E29 (DIST), E31 (AGC) and E32 (IREF).

# Mounting of components and Unit-testing
Use this test-document to get a working PCB2 board: [PCB2 Unit Test](img/PCB2_Unit_Test.pdf). Because of the complexity of the board, all components are mounted prior to unit-testing. Use this document instead of Bob Cordell's bench-testing, because operating the switches is now done by the µC control board, which is described in this document.

In order to test this PCB, a working PCB4 (µC control board) is needed. PCB4 should be connected to a host-PC with an USB-to-UART adapter, communication settings are 57600,N,8,1. See the [PCB4](./pcb4.md) page for more details.

# Eagle source-files
Not to be used for commercial purposes!
This is the .zip file containing the Eagle source-files: [PCB2 Eagle Files](img/PCB2_Eagle.zip)

# Gerber-Files
This is the .zip file containing the Gerber files that were sent to JLCPCB: [PCB2 Gerber Files](img/pcb2_relay_v021_combined_2022-05-19.zip)

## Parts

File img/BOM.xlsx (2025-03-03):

 |  |  |  |  |  |  |  |  |  |  |  | BTW: | 21%
Parts PCB1 | Parts PCB2 | Parts PCB3 | Parts PCB4 - uC | Value | Package | Where | Mouser Part No. | QNTY | Stock | BUY | Cost | Total Cost | Cost (+VAT)
DS1..DS14, DS17..DS24 | DS1..DS24 | DS1..DS30 |  | 1N4007 | DO214-AC |  | 637-M7 | 76 | 76 | 0
D1..D3 | D4..D11, D22, D23 | D12..D23 | D1, D2, D3, D4, D5 | 1N4148 | SOD80 or DO123AA |  | 494-1N4148UR-1 | 27 | 28 | 0
Q2, Q3, Q4 |  |  |  | 2N3904 | TO92 | Aliexpress |  | 3 | 3 | 0
Q1 | Q5, Q6 |  |  | 2N4091/PN4091 | TO92G | Aliexpress |  | 3 | 4 | 0
QS1..QS14, QS17..QS24 | QS1..QS24 | QS1..QS30 |  | SS8050 | SOT23 | Aliexpress | 750-SS8050-G | 76 | 100 | 0 | €0.087 |  |  | Per 100
 |  |  | LD1 | LED | SMD 1206 |  |  |  |  |  |  |  |  | Per 100
 |  |  | Q1 | BC847 | SOT23 |  |  |  |  |  |  |  |  | Per 100
IC9..IC11 | IC1, IC2, IC3 | IC1, IC2 |  | 74HC595D | SOIC-8 |  |  | 8 | 8 | 0
 | IC24 |  |  | LF356D | SOIC-8 |  |  | 1 | 5 | 0
 |  | IC27, IC30 |  | LM1458D | SOIC-8 |  |  | 2 | 5 | 0
IC5, IC6, IC7 | IC6, IC7, IC18, IC19, IC21, IC23, | IC25, IC28, IC31..IC36 |  | LM318D | SOIC-8 |  | 595-LM318DR | 19 | 20 | 0 | €1.310 |  |  | Per 10
 |  |  |  | LM393D | SOIC-8 | Aliexpress
 |  | IC38 |  | LM324D | SOIC-8 |  | 511-LM324D-TR | 1 | 0 | 10 | €0.326 | €3.26 | €3.94
 |  |  | IC3 | TL072D | SOIC-8 |  | 595-TL072HIDR | 1 | 0 | 10 | €0.326 | €3.26 | €3.94
 |  |  | IC4 | TL074D | SOIC-8 |  | 511-TL074IDT | 1 | 0 | 10 | €0.326 | €3.26 | €3.94
 | IC8 | IC37 |  | LM741D | SOIC-8 |  |  | 2 | 10 | 0
 | IC20, IC22 | IC26, IC29 |  | MC1496D | SOIC-14 |  | 863-MC1496DR2G | 4 | 20 | 0 | €1.120
IC1..IC4, IC8 | IC9..IC17 |  |  | NE5534AD | SOIC-8 |  |  | 14 | 30 | 0
IC13 | IC130 | IC4 | IC1 | LM7805 | TO220 |  |  | 4 | 4 | 0
IC12 | IC120 | IC3 |  | LM7812 | TO220 | Aliexpress |  | 3 | 12 | 0
 |  |  | IC2 | STM8S105C6T6 | LQFP-48 |  | 511-STM8S105C6T6 | 1
K1..K14, K17..K24 | K1..K24 | K1..K30 |  | G6K-2F-Y 12V | Relay | Aliexpress | 653-G6K-2F-Y-TRDC12 | 76 | 30 | 0 | €3.520 |  |  | Per 25
CON3 | CON1, CON2 | CON1, CON2 | CON10, CON11, CON12 | 2x4 pin flatcable connector |  | Aliexpress |  | 8 | 20 | 0
 |  |  |  | 8p flatcable, 4 x 0.5 m |  | Aliexpress |  | 4 | 4 | 0
 |  |  | CON1..CON5, CON7 | 4 pins male header |  | Aliexpress |  | 6 | 6 | 0
 |  |  | CON6 | 3 pins male header |  | Aliexpress |  | 1 | 1 | 0
 | L1..L4 |  |  | Ferrite core 600 Ohm | SMD 1206 | Aliexpress |  | 4 | 100 | 0
 | L5..L7 |  |  | 10 uH | SMD 1206 | Aliexpress |  | 3 | 100 | 0
 | C4 |  |  | 5 pF trimmer |  | Aliexpress |  | 1 | 5 | 0
 | C3, C5 |  |  | 30 pF trimmer |  | Aliexpress |  | 2 | 5 | 0
 | C75 |  |  | 2 pF | SMD 1206 |  | 80-C1206C209D5HACTU | 1 | 49 | 0 | €0.171
 | C24 |  |  | 10 pF silver mica | 042x103, pitch 7.5 | 11.4x4.3, pitch 5.9 | 598-CD15CD100JO3F | 1 | 1 | 0 | €1.990
C1 | C25, C27 |  |  | 15 pF silver mica | 042x103, pitch 7.5 | 11.4x4.3, pitch 5.9 | 5982-15-500V15 | 3 | 3 | 0 | €1.810
C2, C3 | C26, C28 |  |  | 22 pF silver mica | 042x103, pitch 7.5 | 10.9x3.6, pitch 5.1 | 598-CDA15ED220XXB | 4 | 4 | 0 | €2.120
 |  | CEG4 |  | 47 pF | SMD 1206 |  | 710-885012008041 | 1 |  | 2 | €0.100 | €0.20 | €0.24
 | C22 |  |  | 47 pF silver mica | 042x103, pitch 7.5 | 11.4x4.3, pitch 5.9 | 5982-15-500V47 | 1 | 1 | 0 | €1.880
 | C222 |  |  | 68 pF silver mica | 052x106, pitch 7.5 | 11.4x4.6, pitch 5.9 | 5982-15-500V68 | 1 | 1 | 0 | €2.100
 |  | CAC4 | C19 | 100 pF | SMD 1206 |  | 710-885012008043 | 1 |  | 2 | €0.124 | €0.25 | €0.30
CKM4, CLN4 | COQ4, CPR4 |  |  | 200 pF/100V, ps or silver mica | 043x133, pitch 10.2 | 10.9x3.8, pitch ? | 598-CDV16FF201JO3 | 4 | 4 | 0 | €2.230
 |  | CEG3 |  | 680 pF | SMD 1206 |  | 710-885012208074 | 1 |  | 2 | €0.107 | €0.21 | €0.26
 |  | CAC3 |  | 1 nF | SMD 1206 |  | 710-885012208075 | 1 |  | 2 | €0.087 | €0.17 | €0.21
 |  | CBD3, CDF3 |  | 2.2 nF | SMD 1206 |  | 710-885012208077 | 2 |  | 4 | €0.109 | €0.44 | €0.53
CKM3, CLN3 | COQ3, CPR3 |  |  | 2.2 nF/100V, ps or silver mica 2.2 nF/100V, metal polyester | 052x106, pitch 7.5 | 11.9x6.4, pitch ? 10x4.5, pitch 7.5 | 598-CD16FD222JO3 667-ECQ-E6222KF | 4 | 0 | 4 | €0.447 | €1.79 | €2.16
 |  | CEG2 |  | 6.8 nF | SMD 1206 |  | 710-885012208080 | 1 |  | 2 | €0.123 | €0.25 | €0.30
 |  | CAC2 |  | 10 nF | SMD 1206 |  | 710-885012208112 | 1 |  | 2 | €0.097 | €0.19 | €0.23
C12 |  |  |  | 10 nF/100V metal polyester | 045x075, pitch 5.0 | 7.9x4.2, pitch 5 | 667-ECQ-E2103JB3 | 1 | 0 | 1 | €0.466 | €0.47 | €0.56
 |  | CBD2, CDF2 |  | 22 nF | SMD 1206 |  | 710-885012208083 | 2 |  | 4 | €0.113 | €0.45 | €0.55
CKM2, CLN2 | COQ2, CPR2 |  |  | 22 nF, pp, pc or pe | 045x075, pitch 5.0 | 7.9x4.3, pitch 5 | 667-ECQ-E2223KB3 | 4 | 0 | 4 | €0.532 | €2.13 | €2.57
 |  | CEG1 |  | 68 nF | SMD 1206 |  | 710-885012208086 | 1 |  | 2 | €0.132 | €0.26 | €0.32
22 x | 42 x | 32 x, CAC1 | 17 x | 100 nF | SMD 1206 |  | 187-CL31B104KBCNNND | 96 |  | 100 | €0.040 | €4.00 | €4.84
C11 |  |  |  | 100 nF/100V, metal polyester | 063x106, pitch=7.5 | 7.9x5.9, pitch 5 | 667-ECQ-E2104JF | 1 | 0 | 2 | €0.466 | €0.93 | €1.13
 |  | CBD1, CDF1 |  | 220 nF | SMD 1206 |  | 187-CL31B224KBFNNNF | 2 |  | 4 |  | €0.00 | €0.00
CKM1, CLN1 | C51, COQ1, CPR1 |  |  | 220 nF, metal polyester | 052x106, pitch 7.5 | 10.3x5.4, pitch 7.5 | 667-ECQ-E2224KFA | 5 | 0 | 5 | €0.416 | €2.08 | €2.52
C10 |  |  |  | 470 nF, metal polyester | 064x133, pitch 10.2 | 12.3x6.2, pitch 10 | 667-ECQ-E2474RKB | 1 | 0 | 2 | €0.656 | €1.31 | €1.59
 |  | C54, C58 |  | 470 nF/50V | SMD 1206 |  | 187-CL31B474KBHNNNE | 2 |  | 4 | €0.126 | €0.50 | €0.61
 |  |  | C5 | 820 nF | SMD 1206 |  | 81-GCJ31CR71H824MA2L | 1 | 10 | 0 | €0.456
C9 | C210, C211 |  |  | 1 uF/250V metal polyester | 072x183, pitch 15.0 | 15.3x7.0, pitch 12.5 | 667-ECQ-E2105KF | 3 | 0 | 3 | €0.732 | €2.20 | €2.66
 |  |  | C12 | 1 uF | SMD 1206 |  | 710-865080640001 | 11 | 6 | 5 | €0.181 | €0.91 | €1.10
CN3, CP3 | C37, C38, C44, C48, C50, C74 | C70, C71, C74 | C23 | 1 uF/50 V elco | 4x5.8 SMD |  | 710-865080640001 | 11 | 6 | 5 | €0.181 | €0.91 | €1.10
C4, C5 | C9N1, C9P1, C23, C41, C43, C45, C46, C47, C49 |  |  | 10 uF/25 V elco | 4x5.8 SMD |  | 647-UWR1V100MCL1GB | 11 | 0 | 11 | €0.229 | €2.52 | €3.05 | Per 10
 |  |  | C1, C2 | 10 uF | SMD 1206 |  | 647-UWR1V100MCL1GB | 11 | 0 | 11 | €0.229 | €2.52 | €3.05 | Per 10
C6..C8, C13, C15, C18, C21 | C1, C15, C18, C35, C36, C42, C73 | C15, C18, C30, C52, C53, C55..C57, C59, C66, C67, C72, C73 | C17 | 100 uF/16V elco | 6.3x5.8 SMD |  | 140-VEJ101M1ETR0607 | 29 | 30 | 0 | €0.281
R24 |  | R135, R157 |  | 1K Trimpot | 3296W | Aliexpress | 652-3296Y-1-102LF | 3 | 3 | 0 | €2.470
 |  | R180 |  | 2K Trimpot | 3296W | Aliexpress | 652-3296Y-1-202LF | 1 | 1 | 0 | €2.310
R30 |  |  |  | 2K5 Potmeter |  |  | 31VA303-F3 | 1 | 0 | 2 | €1.950 | €3.90 | €4.72
R1..R4 | R59, R62, R192 | R192 | R192 | 5K Trimpot | 3296W | Aliexpress | 652-3296Y-1-502LF | 9 |  |  | €2.470
RKM4, RLN4 |  | R144, R166 |  | 68 R | SMD 1206 |  | 652-CR1206FX-68R0ELF | 4 |  | 10 | €0.043 | €0.43 | €0.52 | Per 10
 | R83, R98, R99. R101, R112, R113, R115, R182 | R129..R132, R148, R153, R154, R167, R172, R173, R175, R182, R207 |  | 100 R | SMD 1206 |  | 652-CR1206FX-1000ELF | 22 |  | 100 | €0.018 | €1.80 | €2.18 | Per 10
 | ROQ4, RPR4 | RA10, RB10 |  | 180 R | SMD 1206 |  | 652-CR1206FX-1800ELF | 4 |  | 10 | €0.049 | €0.49 | €0.59
R39, R40 | R213, R214 | RA9, RB9 |  | 220 R | SMD 1206 |  | 652-CR1206FX-2200ELF | 6 |  | 10 | €0.043 | €0.43 | €0.52 | Per 10
R10 | R68, R76 |  |  | 270 R | SMD 1206 |  | 652-CR1206FX-2700ELF | 3 | 10 | 0 | €0.049 |  |  | Per 10
 | R93 |  |  | 316 R | SMD 1206 |  | 652-CR1206FX-3160ELF | 1 |  | 10 | €0.065 | €0.65 | €0.79 | Per 10
R9 | R73, R75 | RA8, RB8 |  | 330 R | SMD 1206 |  | 652-CR1206FX-3300ELF | 5 |  | 10 | €0.043 | €0.43 | €0.52 | Per 10
 |  | RA7, RB7 |  | 360 R | SMD 1206 |  | 652-CR1206FX-3600ELF | 2 |  | 10 | €0.043 | €0.43 | €0.52
 |  | R169 |  | 390 R | SMD 1206 |  | 652-CR1206FX-3900ELF | 1 |  | 10 | €0.043 | €0.43 | €0.52
 |  | RA6, RB6 |  | 430 R | SMD 1206 |  | 652-CR1206FX-4300ELF | 2 |  | 10 | €0.043 | €0.43 | €0.52
 | R104 | RC10 | R16, R17, R18 | 470 R | SMD 1206 |  | 652-CR1206FX-4700ELF | 5 |  | 10 | €0.043 | €0.43 | €0.52 | Per 10
 |  | RC9 |  | 510 R | SMD 1206 |  | 652-CR1206FX-5100ELF | 1 |  | 10 | €0.065 | €0.65 | €0.79
R8 | R72, R74 |  |  | 560 R | SMD 1206 |  | 652-CR1206FX-5600ELF | 3 |  | 10 | €0.049 | €0.49 | €0.59 | Per 10
R38 |  |  |  | 620 R | SMD 1206 |  | 652-CR1206FX-6200ELF | 1 |  | 10 | €0.065 | €0.65 | €0.79
 |  | RA5, RB5 |  | 680 R | SMD 1206 |  | 652-CR1206FX-6800ELF | 2 |  | 10 | €0.043 | €0.43 | €0.52
 | R92 | RA4, RA11, RB4, RB11 |  | 750 R | SMD 1206 |  | 652-CR1206FX-7500ELF | 5 |  | 10 | €0.049 | €0.49 | €0.59 | Per 10
R37 |  | RC8 |  | 820 R | SMD 1206 |  | 652-CR1206FX-8200ELF | 2 |  | 10 | €0.043 | €0.43 | €0.52 | Per 10
 |  | RC7 |  | 910 R | SMD 1206 |  | 652-CR1206FX-9100ELF | 1 |  | 10 | €0.043 | €0.43 | €0.52
RE1011, RF1011, R17, R31 | R51, R183..R187, RG10, RH10 | R183, RA2, RB2, RC6, R128, R149, R150, R176, R185..R187 | R10, R11, R14, R28, R29, R31 | 1K | SMD 1206 |  | 652-CR1206FX-1001ELF | 26 |  | 50 | €0.043 | €2.15 | €2.60 | Per 10
RE910, RF910 | R88, R95, RG9, RH9 |  |  | 1K1 | SMD 1206 |  | 652-CR1206FX-1101ELF | 6 | 12 | 0 | €0.065 |  |  | Per 10
 |  | RD10 |  | 1K2 | SMD 1206 |  | 652-CR1206FX-1201ELF | 1 |  | 10 | €0.043 | €0.43 | €0.52
R20, R35 |  | RA3, RB3, RD9 |  | 1K3 | SMD 1206 |  | 652-CR1206FX-1301ELF | 5 | 15 | 0 | €0.043
R12 | R69, R78 | R137, R159, R204, RA1, RB1 |  | 1K5 | SMD 1206 |  | 652-CR1206FX-1501ELF | 8 |  | 20 | €0.043 | €0.86 | €1.04 | Per 10
 |  | RC5 |  | 1K6 | SMD 1206 |  | 652-CR1206FX-1601ELF | 1 |  | 10 | €0.043 | €0.43 | €0.52
RE89, RF89 | RG8, RH8 |  |  | 1K78 | SMD 1206 |  | 652-CR1206FX-1781ELF | 4 |  | 10 | €0.043 | €0.43 | €0.52 | Per 10
R36 |  | RC4, RC11 |  | 1K8 | SMD 1206 |  | 652-CR1206FX-1801ELF | 3 |  | 10 | €0.043 | €0.43 | €0.52
RE78, RF78 | RG7, RH7 |  |  | 1K96 | SMD 1206 |  | 652-CR1206FX-1961ELF | 4 |  | 10 | €0.043 | €0.43 | €0.52 | Per 10
R34 |  |  |  | 2K | SMD 1206 |  | 652-CR1206FX-2001ELF | 1 |  | 10 | €0.043 | €0.43 | €0.52
 | R52 |  |  | 2K05 | SMD 1206 |  | 652-CR1206FX-2051ELF | 1 |  | 10 | €0.043 | €0.43 | €0.52 | Per 10
RE67, RF67 | R91, RG6, RH6 |  |  | 2K15 | SMD 1206 |  | 652-CR1206FX-2151ELF | 5 |  | 10 | €0.032 | €0.32 | €0.39 | Per 10
R32 | R84 | RD8 | R1..R7, R25, R26 | 2K2 | SMD 1206 |  | 652-CR1206FX-2201ELF | 9 |  | 20 | €0.043 | €0.86 | €1.04 | Per 10
 |  | RC2, RD7 |  | 2K4 | SMD 1206 |  | 652-CR1206FX-2401ELF | 2 |  | 10 | €0.049 | €0.49 | €0.59
 |  | R127, R200..R203, RD6 | R19 | 2K7 | SMD 1206 |  | 652-CR1206FX-2701ELF | 7 | 13 | 0 | €0.043
 |  | RC3, R179 |  | 3K | SMD 1206 |  | 652-CR1206FX-3001ELF | 2 |  | 10 | €0.043 | €0.43 | €0.52
 | R49 |  |  | 3K16 | SMD 1206 |  | 652-CR1206FX-3161ELF | 1 |  | 10 | €0.043 | €0.43 | €0.52 | Per 10
 | R1 | R1, R170 |  | 3K3 | SMD 1206 |  | 652-CR1206FX-3301ELF | 3 |  | 10 | €0.043 | €0.43 | €0.52 | Per 10
RE56, RF56 | RG5, RH5 |  |  | 3K48 | SMD 1206 |  | 652-CR1206FX-3481ELF | 4 |  | 10 | €0.043 | €0.43 | €0.52 | Per 10
 |  | RC1 |  | 3K6 | SMD 1206 |  | 652-CR1206FX-3601ELF | 1 |  | 10 | €0.043 | €0.43 | €0.52
RE45, RF45, RE1112, RF1112 | RG4, RG11, RH4, RH11 |  |  | 3K83 | SMD 1206 |  | 652-CR1206FX-3831ELF | 8 |  | 20 | €0.043 | €0.86 | €1.04 | Per 10
 |  | RD5 |  | 4K3 | SMD 1206 |  | 603-AC1206FR-074K3L | 1 |  | 4 | €0.080 | €0.32 | €0.39
RS1..RS14, RS17..RS24 | R82, R107..R110, R193, RS1..RS24 | R125, R151, R152, R193, RD4, RD11, RS1..RS30 | R8, R20, R24 | 4K7 | SMD 1206 |  | 652-CR1206FX-4701ELF | 88 |  | 100 | €0.018 | €1.80 | €2.18 | Per 100
R29 |  |  |  | 5K6 | SMD 1206 |  | 652-CR1206FX-5601ELF | 1 |  | 10 | €0.033 | €0.33 | €0.40
RE23, RF23 | RG2, RH2 |  |  | 5K62 | SMD 1206 |  | 652-CR1206FX-5621ELF | 4 |  | 10 | €0.043 | €0.43 | €0.52 | Per 10
RE34, RF34 | RG3, RH3 |  |  | 6K19 | SMD 1206 |  | 652-CR1206FX-6191ELF | 4 |  | 10 | €0.043 | €0.43 | €0.52 | Per 10
 | R94 |  |  | 6K2 | SMD 1206 |  | 652-CR1206FX-6201ELF | 1 |  | 10 | €0.043 | €0.43 | €0.52 | Per 10
R5, R19 | R58, R102, R116, R190 | R140, R141, R162, R163, R190, RD2 |  | 6K8 | SMD 1206 |  | 652-CR1206FX-6801ELF | 12 |  | 30 | €0.049 | €1.47 | €1.78 | Per 10
RE12, RF12 | R90, RG1, RH1 | RD3 |  | 7K5 | SMD 1206 |  | 652-CR1206FX-7501ELF | 6 |  | 12 | €0.049 | €0.59 | €0.71 | Per 10
 |  | R177 |  | 9K09 | SMD 1206 |  | 652-CR1206FX-9091ELF | 1 | 9 | 0 | €0.043
 |  | R184, RD1 |  | 9K1 | SMD 1206 |  | 652-CR1206FX-9101ELF | 2 | 8 | 0 | €0.043
R6, R11, R14, R15, R18, R22, R23, R25..R27 | R56, R60, R61, R63, R64, R67, R71, R77, R80, R89, R96, R188 | R134, R136, R143, R145, R147, R156, R158, R165, R188, R195, R197, R199 | R13,R15,R22,R23,R27,R30,R33 | 10 K | SMD 1206 |  | 652-CR1206FX-1002ELF | 37 |  | 100 | €0.043 | €4.30 | €5.20 | Per 10
 | R47, R124 |  |  | 11 K | SMD 1206 |  | 652-CR1206FX-1102ELF | 2 |  | 10 | €0.043 | €0.43 | €0.52 | Per 10
 | R97, R100, R106, R111, R114, R118 |  |  | 15 K | SMD 1206 |  | 652-CR1206FX-1502ELF | 6 |  | 20 | €0.043 | €0.86 | €1.04 | Per 10
 | R55, R85 |  |  | 18 K | SMD 1206 |  | 652-CR1206FX-1802ELF | 2 | 11 | 0 | €0.049 |  |  | Per 10
 | R189 | R189 | R21 | 20 K | SMD 1206 |  | 652-CR1206FX-2002ELF | 3 | 20 | 0 | €0.043 |  |  | Per 10
R28, R206 | R57 | R126, R133, R138, R139, R155, R160, R161 |  | 22 K | SMD 1206 |  | 652-CR1206FX-2202ELF | 10 |  | 20 | €0.049 | €0.98 | €1.19 | Per 10
 | R81 |  |  | 27 K | SMD 1206 |  | 652-CR1206FX-2702ELF | 2 |  | 10 | €0.043 | €0.43 | €0.52 | Per 10
 |  | R196, R198 |  | 33 K | SMD 1206 |  | 652-CR1206FX-3302ELF | 2 |  | 10 | €0.043 | €0.43 | €0.52
 |  | R194 |  | 39 K | SMD 1206 |  | 652-CR1206FX-3902ELF | 1 |  | 10 | €0.043 | €0.43 | €0.52
 |  |  | R12, R32 | 47 K | SMD 1206 |  | 652-CR1206FX-3902ELF | 1 |  | 10 | €0.043 | €0.43 | €0.52
 | R45 |  |  | 42K2 | SMD 1206 |  | 652-CR1206FX-4222ELF | 1 |  | 10 | €0.065 | €0.65 | €0.79 | Per 10
 | R44 |  |  | 68K1 | SMD 1206 |  | 652-CR1206FX-6812ELF | 1 |  | 10 | €0.043 | €0.43 | €0.52 | Per 10
 | R54, R65 |  |  | 82 K | SMD 1206 |  | 652-CR1206FX-8202ELF | 2 |  | 10 | €0.043 | €0.43 | €0.52 | Per 10
 | R46 |  |  | 90K9 | SMD 1206 |  | 652-CR1206FX-9092ELF | 1 |  | 10 | €0.043 | €0.43 | €0.52 | Per 10
R16, R33 | R48, R50, R86, R105, R119, R120, R123 | R142, R146, R164, R171, R174 |  | 100 K | SMD 1206 |  | 652-CR1206FX-1003ELF | 14 |  | 30 | €0.043 | €1.29 | €1.56 | Per 10
R7 | R66 |  |  | 150 K | SMD 1206 |  | 652-CR1206FX-1503ELF | 3 | 7 | 0 | €0.043
 | R191 | R191 |  | 270 K | SMD 1206 |  | 652-CR1206FX-2703ELF | 2 |  | 10 | €0.043 | €0.43 | €0.52 | Per 10
R13 | R70, R79 |  |  | 750 K | SMD 1206 |  | 652-CR1206FX-7503ELF | 3 |  | 10 | €0.049 | €0.49 | €0.59 | Per 10
R21, R41, R42, R43 | R53, R103, R117, R121 |  |  | 1 M | SMD 1206 |  | 652-CR1206FX-1004ELF | 8 |  | 20 | €0.043 | €0.86 | €1.04 | Per 10
R205 |  |  |  | 2M7 | SMD 1206 |  | 603-AC1206FR-072M7L | 1 | 10 | 0 | €0.105
 | R122 |  |  | 22 M | SMD 1206 |  | 279-CRG1206F22M | 1 |  | 2 | €0.466 | €0.93 | €1.13 | Per 1
 | TOTAL COST |  |  | TOTAL COST |  |  |  |  |  |  |  | €78.61 | €95.12

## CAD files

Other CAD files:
Debug/Exe/THD_Analyzer_stm8s105.stp

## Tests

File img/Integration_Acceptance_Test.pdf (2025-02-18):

Integration & Acceptance Test THD Analyzer

Bob Cordell’s article (part 3) describes this as “Intermediate Check-Out” (page 57) and “Test and Calibration” (page 58-59). The system itself is tested slightly different from Bob’s tests. This is because we use the µC board (PCB4) to control all switches.

Date test conducted:
PCB1, PCB2, PCB3 hardware version: | V0.30 V0.21 V0.21
End-result of test | OK / NOK

Intermediate Check-Out

Nr. | Description
| Entry-criteria: - a tested and working µC control-board (PCB4) is needed for these tests. - Unit-tests for PCB1, PCB2 and PCB3 boards have been done and no errors were found. - Flat-cables (4) are connected between: PCB1 and PCB4, PCB2 and PCB4 and between PCB3 and PCB4 PCB2 and PCB3 inter-connect - Function-generator, oscilloscope, true-RMS multimeter.

0 - For PCB1, PCB2, PCB3 and PCB4: Connect ±15 V and GND to +15 V, GND and -15 V.
| Description | Result | OK?
Expected | Measured
1.1 - Connect MAIN.OUT (PCB1) to the Input on PCB2. | - Use the Level potmeter on PCB1 to set PCB2 input-voltage to 1 Vrms. Use a true-RMS multimeter to measure this value as accurate as possible. - Set Frequency to 2 kHz. - Set Output-level to 5V. - Set Input-level to 3V. - Set Sensitivity to 0.3%. - Adjust R59 (freq.) and R62 (ampl.) as necessary | - Analyzer has locked itself - E8 between -1V and -4V - E22 between -1V and -4V - E23 between -1V and -4V - No oscillations | | OK/NOK
1.2 - Inject a distortion signal (6 kHz, 150 mVrms) from a | 2 nd function-generator through a 62 kΩ into PCB2 input. - Calibrate the 0.3% Sensitivity setting as follows: UART: type ‘c11’ and write down the value. c11_new = (x * c11) / (y * z), with: x = 150 mVrms (2nd function-generator output) y = PCB1 output-value in mVrms z = value on SSD4 (e.g. 0.15) - Enter this new value by typing ‘c11 c11_new’, with c11_new being the number calculated. - Check that SSD4 now displays 0.150 %. | - Distortion is 0.15 %, SSD4 reading should be close to this value. - Check signal at E40 (DIST.OUT), this should be a clean 6 kHz signal c11_new = | c11 = | OK/NOK
1.3 - Set Sensitivity to 1.0 %. | - Inject a distortion signal (6 kHz, 500 mVrms) from a 2 nd function-generator through a 62 kΩ into PCB2 input. - Calibrate the 1.0% Sensitivity setting as follows: UART: type ‘c10’ and write down the value. c10_new = (x * c10) / (y * z), with: x = 500 mVrms (2nd function-generator output) y = PCB1 output-value in mVrms z = value on SSD4 (e.g. 0.500) - Enter this new value by typing ‘c10 c10_new’, with c10_new being the number calculated. - Check that SSD4 now displays 0.500 %. | - Distortion is 0.5 %, SSD4 reading should be close to this value. - Check signal at E40 (DIST.OUT), this should be a clean 6 kHz signal c10_new = | c10 = | OK/NOK

1.4 - Set Sensitivity to 3.0 %. | - Inject a distortion signal (6 kHz, 1.5 Vrms) from a 2nd function-generator through a 62 kΩ into PCB2 input. - Calibrate the 3.0% Sensitivity setting as follows: UART: type ‘c9’ and write down the value. c9_new = (x * c9) / (y * z), with: x = 1500 Vrms (2nd function-generator output) y = PCB1 output-value in mVrms z = value on SSD4 (e.g. 1.500) - Enter this new value by typing ‘c9 c9_new’, with c9_new being the number calculated. - Check that SSD4 now displays 1.500 %. | - Distortion is 1.5 %, SSD4 reading should be close to this value. - Check signal at E40 (DIST.OUT), this should be a clean 6 kHz signal c9_new = | c9 = | OK/NOK
1.5 - Set Sensitivity to 10.0 %. | - Inject a distortion signal (6 kHz, 5 Vrms) from a 2nd function-generator through a 62 kΩ into PCB2 input. - Calibrate the 10.0% Sensitivity setting as follows: UART: type ‘c8’ and write down the value. c8_new = (x * c8) / (y * z), with: x = 5000 Vrms (2nd function-generator output) y = PCB1 output-value in mVrms z = value on SSD4 (e.g. 5.000) - Enter this new value by typing ‘c8 c8_new’, with c8_new being the number calculated. - Check that SSD4 now displays 5.000 %. | - Distortion is 5.0 %, SSD4 reading should be close to this value. - Check signal at E40 (DIST.OUT), this should be a clean 6 kHz signal c8_new = | c8 = | OK/NOK
1.6 - Set Sensitivity to 0.1 %. | - Inject a distortion signal (6 kHz, 50 mVrms) from a 2nd function-generator through a 62 kΩ into PCB2 input. - Calibrate the 0.1% Sensitivity setting as follows: UART: type ‘c12’ and write down the value. c12_new = (x * c12) / (y * z), with: x = 50 mVrms (2nd function-generator output) y = PCB1 output-value in mVrms z = value on SSD4 (e.g. 0.05) - Enter this new value by typing ‘c12 c12_new’, with c12_new being the number calculated. - Check that SSD4 now displays 0.050 %. | - Distortion is 0.05 %, SSD4 reading should be close to this value. - Check signal at E40 (DIST.OUT), this should be a clean 6 kHz signal c12_new = | c12 = | OK/NOK

1.7 - Set Sensitivity to 300 ppm, increase Input-level to 10V and use the Level potmeter on PCB1 to increase the PCB1 output-voltage to 4.5 Vrms. Use a true-RMS multimeter to measure this value as accurate as possible.
- Inject a distortion signal (6 kHz, 90 mVrms) from a 2nd function-generator through a 62 kΩ into PCB2 input.
- Calibrate the 300 ppm Sensitivity setting as follows:
- UART: type ‘c13’ and write down the value.
- c13_new = (x * c13 * 1E+4) / (y * z), with:
- x = 90 mVrms (2nd function-generator output)
- y = PCB1 output-value in mVrms
- z = value on SSD4 (e.g. 200 ppm)
- Enter this new value by typing ‘c13 c13_new’, with c13_new being the number calculated.
- Check that SSD4 now displays 200 ppm.
- Distortion is 200 ppm,
SSD4 reading should be
close to this value.
- Check signal at E40
(DIST.OUT), this should be a clean 6 kHz signal

c13_new =

c13 =

OK/NOK

1.8 - Set Sensitivity to 100 ppm. | - Inject a distortion signal (6 kHz, 30 mVrms) from a 2nd function-generator through a 62 kΩ into PCB2 input. - Calibrate the 100 ppm Sensitivity setting as follows: UART: type ‘c14’ and write down the value. c14_new = (x * c14 * 1E+4) / (y * z), with: x = 30 mVrms (2nd function-generator output) y = PCB1 output-value in mVrms z = value on SSD4 (e.g. 67 ppm) - Enter this new value by typing ‘c14 c14_new’, with c14_new being the number calculated. - Check that SSD4 now displays 66.7 ppm. | - Distortion is 66.7 ppm, SSD4 reading should be close to this value. - Check signal at E40 (DIST.OUT), this should be a clean 6 kHz signal c14_new = | c14 = | OK/NOK
1.9 - Set Sensitivity to 30 ppm. | - Inject a distortion signal (6 kHz, 12 mVrms) from a 2nd function-generator through a 62 kΩ into PCB2 input. - Calibrate the 30 ppm Sensitivity setting as follows: UART: type ‘c15’ and write down the value. c15_new = (x * c15 * 1E+4) / (y * z), with: x = 12 mVrms (2nd function-generator output) y = PCB1 output-value in mVrms z = value on SSD4 (e.g. 20 ppm) - Enter this new value by typing ‘c15 c15_new’, with c15_new being the number calculated. - Check that SSD4 now displays 26.7 ppm. | - Distortion is 26.7 ppm, SSD4 reading should be close to this value. - Check signal at E40 (DIST.OUT), this should be a clean 6 kHz signal c15_new = | c15 = | OK/NOK

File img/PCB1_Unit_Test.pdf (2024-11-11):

Unit Test PCB1 THD Analyzer

Bob Cordell’s article (part 3) describes this as CP1 bench-testing. The PCB itself is tested slightly different from Bob’s bench-test. This is because we use the µC board (PCB4) to control all the switches.

Date test conducted:
PCB1 hardware version: | V0.30
PCB4 firmware version:
End-result Test | OK / NOK

PCB1 signal-generator: Unit-Test

Nr. | Description
0 Entry-criteria: | - PCB1 board ready for testing, all components are mounted. - Oscilloscope, true-RMS multimeter and frequency-counter are available. - a tested and working µC control-board (PCB4). - A host PC with USB-to-serial adapter is connected to CON6 (RS232.5V) of the µC control-board (GND-GND, RXD-TX, TXD-RX). - Communication settings are set to 57600,N,8,1. Give the s0 command, a response with version info is returned. | OK/NOK

1 Connect ±15 V and GND to +15 V, GND and -15 V.
2 | Measure the following DC voltages at the test-pins: | +15.0 V +12.0 V +5.0 V -15.0 V | OK/NOK
3 Connect a flatcable from PCB4 CON10 to PCB1 CON3 | (UC_IO). Give the UART command f10 or use the joystick buttons on PCB4 to select a frequency. | Some PCB1 relays are switched. | OK/NOK
4 This step tests relays K1 – K10. | Use the following procedure to check if a relay on PCB3 is switched: - A relay is ON when the voltage level on pin 8 of the relay is equal to approx. 0 Volts (DC). - A relay is OFF when the voltage level on pin 8 of the relay is equal to approx. 12 Volts (DC). - Use the joystick-buttons on PCB4 to select a Frequency and use that to check the relays. - When a relay is NOT mentioned under expected test-results, it should be OFF! Test this as well. | 20 Hz – all relays off 25 Hz – K1 is on 30 Hz – K2 is on 40 Hz – K3 is on 50 Hz – K4 is on 65 Hz – K5 is on 80 Hz – K6 is on 100 Hz – K7 is on 130 Hz – K8 is on 160 Hz – K9 is on 200 Hz – K10 is on | OK/NOK
5 Use the same procedure to check relays K11 – K13 | and K17 – K20. | 200 Hz – K11 & K17 are on 250 Hz – K12 & K18 are on 2.5 kHz – K13 & K19 are on 25 kHz – K20 is on | OK/NOK
6 Use the same procedure to check relays K14 & K21 – | K24, but now select Output-level instead of Frequency. | Output-level: - OFF – K21 is on - 0.15V – K22 is on - 0.5V – K23 is on - 1.5V – K24 is on - 5V – K14 & K24 are on | OK/NOK

PCB1 signal-generator: Unit-Test

Nr. | Description | Result | OK?
Expected | Measured
10 - Center trim pot R24. | - Select a frequency of 2 kHz. - Connect a scope to E5. | 4.5 Vpp sine-wave of approx. 2 kHz. | | OK/NOK
11 | Measure the following DC voltages: | IC1-6: +2.9 mV IC2-6: +0.8 mV IC3-3: +0.1 mV IC3-6: -4.3 mV IC4-6: +1.0 mV IC5-6: -4.6 mV BQ3: +602 mV EQ3: +2.2 V E7 : +2.2 V IC6-6: +13 mV E8 : -2.5 V GQ1 : -2.5 V | | OK/NOK
12 - Set output-level to 1.5V. | - Connect scope channel A to E5 and channel B to E9. - Measure the amplitude with a true-RMS multimeter of both VE11 and VE5. - Set output-level to 5V. - Measure both amplitudes again. | VE11 / VE5 ≈ 1.0 X VE11 / VE5 ≈ 3.0 X | VE11: VE5: = VE11: VE5: = | OK/NOK
13 - Select a frequency of 200 Hz. | - Connect scope channel A to test-pin IC6.6. Adjust R24 for perfect symmetry: adjacent peaks are of equal level. | - 4.5 Vpp sine-wave of approx. 200 Hz. - Signal is full-wave rectified | | OK/NOK
14 Select a frequency of 20 Hz on PCB4. Adjust R24 if | necessary. | - 4.5 Vpp sine-wave of approx. 20 Hz. - Stable level within 15 seconds | | OK/NOK
15¹ | - Connect a scope to E9 and select frequency measurement on the scope (or use a frequency-counter). - Select a frequency of 650 Hz and adjust frequency trimmer R2 for a source frequency of exactly 650 Hz. - Select a frequency of 65 Hz and adjust frequency trimmer R1 for a source frequency of exactly 65 Hz. - Select a frequency of 6.5 kHz and adjust frequency trimmer R3 for a source frequency of exactly 6.5 kHz. - Select a frequency of 65 kHz and adjust frequency trimmer R4 for a source frequency of exactly 65 kHz. | - frequency = 650 Hz - frequency = 65 Hz - frequency = 6.5 kHz - frequency = 65 kHz
16 - Use the µC control-board and select every possible | frequency. - Connect a scope to E9 and check for a stable sine-wave. Measure the actual frequency. - Connect a multimeter to E8 and measure the DC-voltage. | Fill in table 1 with actual measured frequency and E8 DC voltage. - Frequency within 10% - 0.5V ≤ -E8 ≤ 8V | | OK/NOK

1 Test-step 15 is taken from Bob’s “Test and Calibration” paragraph, since it felt more appropriate here as a Unit-Test.

Frequency | Measured | E8 (VDC) | Frequency | Measured | E8 (VDC)
20 Hz
25 Hz | | | 2.5 kHz
30 Hz | | | 3.0 kHz
40 Hz | | | 4.0 kHz
50 Hz | | | 5.0 kHz
65 Hz | | | 6.5 kHz
80 Hz | | | 8.0 kHz
100 Hz | | | 10 kHz
130 Hz | | | 13 kHz
160 Hz | | | 16 kHz
200 Hz | | | 20 kHz
250 Hz | 25 kHz
300 Hz | 30 kHz
400 Hz | 40 kHz
500 Hz | 50 kHz
650 Hz | 65 kHz
800 Hz | 80 kHz
1.0 kHz | 100 kHz
1.3 kHz | 130 kHz
1.6 kHz | 160 kHz
2.0 kHz | 200 kHz

Table 1: results from test-step 15

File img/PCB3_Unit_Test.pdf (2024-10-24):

Unit Test PCB3 THD Analyzer

Bob Cordell’s article (part 3) describes this as CP3 bench-testing. The PCB itself is tested slightly different from Bob’s bench-test. This is because we use the µC board (PCB4) to control all the switches.

Date test conducted:
PCB3 hardware version: | V0.21
End-result of test | OK / NOK

PCB3 Auto-Tune Circuits

Nr. | Description
| Entry-criteria: - a tested and working µC control-board (PCB4) is needed for these tests. - PCB3 board ready for testing, all components are mounted. - Two flat-cables, one for the connection to PCB4 and one for the connection to PCB2. - Function-generator, oscilloscope, true-RMS multimeter.
0 Preparations for Auto-Tune circuits and Filter, Meter and Status Circuits test | - Connect a flat-cable between PCB4 and PCB3, do NOT connect the PCB3-PCB4 flat-cable yet. - Solder a 10 kΩ resistor between E29 (DIST.IN) and GND. - Center trimpots R135 and R157. - Connect ±15 V and GND to +15 V, GND and -15 V.
| Description | Result | OK?
Expected | Measured
1.1 This step tests relays K1 – K10 and relays K15 – K24. | Use the following procedure to check if a relay on PCB3 is switched: - A relay is ON when the voltage level on pin 8 of the relay is equal to approx. 0 Volts (DC). - A relay is OFF when the voltage level on pin 8 of the relay is equal to approx. 12 Volts (DC). - Use the joystick-buttons on PCB4 to select a Frequency and use that to check the relays. - When a relay is NOT mentioned under expected test-results, it should be OFF! Test this as well. | 20 Hz – all relays off 25 Hz – K1 & K15 are on 30 Hz – K2 & K16 are on 40 Hz – K3 & K17 are on 50 Hz – K4 & K18 are on 65 Hz – K5 & K19 are on 80 Hz – K6 & K20 are on 100 Hz – K7 & K21 are on 130 Hz – K8 & K22 are on 160 Hz – K9 & K23 are on 200 Hz – K10 & K24 are on | | OK/NOK
1.2 Use the same procedure to check relays K11 – K14 | and K25 – K27. | 200 Hz – K11 & K25 are on 250 Hz – K12 & K26 are on 2.5 kHz – K13 & K27 are on 25 kHz – K14 & K27 are on | | OK/NOK
1.3 Use the same procedure to check relays K28 & K29, | but now select Sensitivity instead of Frequency. | Sensitivity: - 0.3% - K28 is on - 0.03% - K28 & K29 are on - 0.01% - K29 is on | | OK/NOK
2 Measure the following DC-voltages with a 10 kΩ | resistor in series: | IC25-6: +2.5 mV IC26-1 and IC26-4: -7.6 V IC26-2 and IC26-3: -8.2 V IC26-5: -14.0 V IC26-6: +5.6 V IC26-10: -2.2 mV IC26-12: +5.6 V IC27-5: +1.3 V IC27-7: 0.0 V IC28-6: +7.2 mV IC29-10: -10.4 mV IC29-12: +5.6 V IC30-5: +1.4 V | | OK/NOK
3.1 | Turn R135 in both positive and negative directions. | Integrator output E23 drifts slowly in positive or negative direction, | | OK/NOK

| | between -12 V and +0.3 V.
3.2 | Turn R157 in both positive and negative directions. | Integrator output E22 drifts slowly in positive or negative direction, between -12 V and +0.3 V. | OK/NOK
4.1 - Select a Sensitivity of 0.01 % on the display. | - Connect a sinewave (100 mVrms / 2 kHz) to E29 (DIST.IN). | - IC31 pin 6 carries the same signal. - IC25 pin 6 carries a soft-clipped 1.5 Vpp version of this signal. | OK/NOK
4.2 | Select a Sensitivity of 0.03 % on the display. | - 1 Vrms at IC31 pin 6 - 2.5 Vpp rounded square wave at IC25 pin 6. | OK/NOK
4.3 - Connect a sinewave (100 mVrms / 2 kHz) to E21. | - Increase the amplitude to 1Vrms. | - Soft-clipped 0.8 Vpp version of this signal at IC28 pin 6. - Hard-clipped 1.0 Vpp signal at IC28 pin 6. | OK/NOK
Nr. | Description
| The following tests need a fully functional PCB2 board. If any problems remain on PCB2, correct them now before proceeding. Preparations for the Auto-Tune circuits tests: - Connect the flatcable between PCB2 CON1 and PCB3 CON1. This connects E21 (QREF), E29 (DIST), E32 (IREF), E22 (ACONT) and E23 (FCONT). Test these interconnections (PCB2 – PCB3) prior to power-up! - Center trimpots R135 and R157 on PCB2. - Connect both PCB2 and PCB3 with their flatcables to PCB4 (3 flatcables in total: PCB4-PCB2, PCB4-PCB3 and PCB2-PCB3).
| Description | Result | OK?
Expected | Measured
5.1 - Connect a sinewave of 1 Vrms and 2 kHz to the PCB2 | input pin. - Select a Sensitivity of 3 %. - Select an Input-level of 3 V. | 1) A 3 Vpp rounded square wave should be visible at IC25 pin 6. If the level is very small, the analyzer may have tuned itself. In this case, changing the frequency by about 10% so that it is well out of the tuning range should yield the square wave. 2) A 1 Vpp square wave should be visible at IC28 pin 6. | | OK/NOK
5.2 - Adjust the input frequency for a minimal output at | E29 and measure the DC voltage at E22. Set the input frequency to yield a voltage equal to one-half the pinch-off voltage for Q5 (default: -3.5 V). - Now adjust R62 on PCB2 for a DC voltage of one-half the pinch-off voltage (default: -3.5 V) of Q6 at E23. | A complete null of the fundamental should now be present at E29, with only distortion and noise visible. | | OK/NOK
5.3 - Remove the flat-cable between PCB2 and PCB3 and | make manual connections for E21 (QREF), E32 (IREF), E22 (ACONT) and E23 (FCONT). - Place a 100-to-1 attenuator between E29 (DIST) on PCB2 and E29 (DIST.IN) on PCB3 (100 kΩ series with 1 kΩ shunt will do). - Alternately adjust R135 and R157 for the best possible fundamental null as observed at E29 (DIST.IN) on PCB2. These adjustments should be made slowly, as the time-constants in the auto-tune control circuits are long. | E31 E21 GND E23 E32 E29 GND E22 PCB2_IO connector | | OK/NOK

PCB3 Filter, Meter and Status Circuits

6.1 - Remove the connections made between PCB2 and | PCB3 in test-step 5.3. - Connect a 10 kΩ resistor between E29 (DIST.IN) and GND. - Center trimpots R180 and R192. - Apply power and measure the following DC voltages through a 10 kΩ isolating resistor at the end of the meter probe to prevent oscillations: | E29: -10 mV IC31-6 & IC32-6: -14 mV IC33-6: -0.6 mV IC34-6: +13.6 mV IC35-6: +110 mV IC36-6: 0.0 mV IC37-6: +1.7 V IC38-3: +3.3 V IC38-6: -3.5 V IC38-13: -12.1 V IC38-14: +13.3 V E47: +12.8 V | OK/NOK
6.2 - Apply a 300 mVrms 2 kHz sinewave to E29 (DIST.IN). | - Select a Sensitivity of 0.3 %. - Select a Frequency of 2 kHz. - Adjust R180 to set IC34 pin 6 to 1/3rd of the voltage at IC33 pin 6. - Drop the input level at E29 (DIST.IN) to 30 mVrms and select a Sensitivity of 0.1 %. - Adjust the input level of the 2 kHz sinewave at E29 (DIST.IN) so that IC35-6 is exactly 500 mVrms. - Adjust R192 to a reading of “0.050 %” on the distortion seven-segment display (SSD4). | - 300 mVrms at IC32 pin 6 - 150 mVrms at IC33 pin 6. - 50 mVrms at IC34 pin 6. - 500 mVrms at IC35 pin 6. - 50 mVrms at IC34 pin 6. - 500 mVrms at IC35 pin 6. - 500 mVrms at IC35 pin 6. - Distortion SSD4 should read “0.050 %”. | OK/NOK
7 - Connect 4 LEDs (D24-D27) from terminals E43 | through E46 to E49 (+15V). - Reconnect the flatcable between PCB2 and PCB3. - Select an Input-level of 3V. - Select a Frequency of 2 kHz. - Connect a sinewave of 1 Vrms and 2 kHz to the input at PCB2. - Increase the frequency of the input sinewave - Decrease the frequency of the input sinewave - Tune for a good notch at E29 (DIST.IN). - Drop input level to 0.25 Vrms - Raise input level to 4 Vrms | E43/D24: freq. too high E44/D25: freq. too low E45/D26: level too high E46/D27: level too low - D26 and D27 are off - D24 is on, D25 is off - D24 is off, D25 is on - D24 and D25 are off - D27 is on, D26 is off - D26 is on, D27 is off | OK/NOK

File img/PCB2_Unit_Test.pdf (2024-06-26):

Unit Test PCB2 THD Analyzer

Bob Cordell’s article (part 3) describes this as CP2 bench-testing. The PCB itself is tested in another way than Bob’s bench-test. This is because we use the microcontroller board (PCB4) to control all the switches.

Date test conducted:
PCB1 hardware version: | V0.21
End-result Test | OK / NOK

PCB2 Input amplifier and Bandpass filters

Nr. | Description
0 Entry-criteria: | - a tested and working µC control-board (PCB4) is needed for these tests. - A host PC with USB-to-serial adapter is connected to CON6 (RS232.5V) of the µC control-board (GND-GND, RXD-TX, TXD-RX). - Set communication settings to 57600,N,8,1. - Give the s0 command, a response with version info is returned. - Mount all components. Since the board is large, we will be testing the relays with resistors and capacitors in another way than we did for PCB1. | OK/NOK
1 With no supply voltage present, measure the | resistance between E16 and E17 and between E19 and E20. | E16-E17: 38440 Ω E19-E20: 38440 Ω | OK/NOK OK/NOK
| Connect ±15 V and GND to +15 V, GND and -15 V.
2 | Measure the following DC voltages at the test-pins: | +15 V +12 V +5 V -15 V | OK/NOK
3 Connect a flatcable from PCB4 CON11 to PCB2 CON2 | (UC_IO). Give the UART command f10 or use the joystick buttons on PCB4 to select a frequency. | Some PCB2 relays are switched. | OK/NOK
4 - Connect a sinewave (2 kHz, 2.82Vpp) to the PCB2 | Input pin. - Connect E15 to the scope, channel 1. - Use the joystick-buttons on PCB4 to select the 100 V input-level or give UART command i0. - Use the joystick-buttons on PCB4 to select the 30 V input-level or give UART command i1. - Use the joystick-buttons on PCB4 to select the 10 V input-level or give UART command i2. - Use the joystick-buttons on PCB4 to select the 3 V input-level or give UART command i3. - Use the joystick-buttons on PCB4 to select the 1 V input-level or give UART command i4. | E15: 84 mVpp E15: 277 mVpp E15: 856 mVpp E15: 2.82 Vpp E15: 8.6 Vpp | OK/NOK
5 - Connect E22 (FCONT) and E23 (ACONT) to GND. | - Connect E18 to the scope, channel 1. - Use the joystick-buttons on PCB4 to select the 3 V input-level or give UART command i3. - Use the following procedure to check if a relay for the resistor-network is switched: Use the joystick-buttons on PCB4 to select a frequency of 20 Hz or give the UART command f0. No resistor-relays are switched. Start with relay K1: if the signal on pin 2 is different from the signals on pins 3 and 4 (use scope channel 2 for this), it is switched (on). If the signal is (almost) the same, it is not switched (off). | 20 Hz – all relays off 25 Hz – K1 is on 30 Hz – K2 is on 40 Hz – K3 is on 50 Hz – K4 is on 65 Hz – K5 is on 80 Hz – K6 is on 100 Hz – K7 is on 130 Hz – K8 is on 160 Hz – K9 is on 200 Hz – K10 is on | OK/NOK

- Select the next frequency up until 200 Hz (UART command f10) and check the relay. Repeat for every relay.

Note: only 1 relay is
on at the same time!
Check that others are
off.

### 6 Use the following procedure to check if a relay for the

capacitor-network is switched:
- Use the joystick-buttons on PCB4 to select a frequency of 25 Hz or give the UART command f1. No capacitor-relays are switched. Check for every relay (K11-K13) that the signal on pin 2 is (almost) the same as the signal on pins 3 and 4.
- Start with relay K11: if the signal on pin 2 is different from the signals on pins 3 and 4, it is switched (on). If the signal is (almost) the same, it is not switched (off).
- Select a frequency of 250 Hz or give the UART command f11.
- Select a frequency of 2.5 kHz or give the UART command f21.
- Select a frequency of 25 kHz or give the UART command f31.

### 25 Hz – all relays off

250 Hz – K11 is on

### 2.5 kHz – K12 is on

### 25 kHz – K13 is on

Note: only 1 relay is
on at the same time!
Check that others are
off.

OK/NOK

7 - Remove the sinewave from the PCB2 Input pin.
- Connect E15 to GND and measure the following DC voltages:

+IC9: -34 mV
OIC9: -101 mV
+IC10: -12 mV
OIC10: +1.2 V
OIC11: +1.2 V
+IC12: 0.0 V
OIC12: +4.3 mV
OIC13: +0.9 V
OIC14: -5.6 V
OIC15: -27.5 mV

OK/NOK

8 - Connect E15 to the scope, channel 1. | - Connect E18 to the scope, channel 2. - Use the joystick-buttons on PCB4 to select the 3 V input-level or give UART command i3. - Connect a sinewave (2 kHz, 2.82Vpp) to the PCB2 Input pin and vary the frequency. | Bandpass characteristic with a center-frequency of approx. 2 kHz. | OK/NOK
9 - Adjust trimpot R59 for a center-frequency of 2 kHz. | - Adjust trimpot R62 for a voltage-level on E18 of 1.15 Vrms (3.25 Vpp). - Adjust trimpot R59 again as necessary. | 2 kHz output on E18 with a voltage-level of 3.25 Vpp. | OK/NOK
10 - Connect IC14 pin 6 to the scope channel 1. | - Connect E19 to the scope channel 2. | Approx. 1 Vpp and in phase with E19. | OK/NOK
11 - Remove the wire from E22 to GND and connect E22 | temporarily to -15V. Check the multiplier (IC14 and Q5) if this test fails. | Approx. 1Vpp and inverted from that at E19. | OK/NOK
12 - Connect IC16 pin 6 to the scope channel 1. | - Connect E21 to the scope channel 2. | Approx. 1 Vpp and in phase with E21. | OK/NOK
13 - Remove the wire from E23 to GND and connect E23 | temporarily to -15V. Check the multiplier (IC16 and Q6) if this test fails. | - Approx. 1Vpp and inverted from that at E21. - Sinewave of approx. 0.4 Vpp present at E24. | OK/NOK

PCB2 Product amplifier and auto-set level circuit

Nr. | Description

20 Use the joystick-buttons on PCB4 to select a sensitivity of 0.03%.

| Description | Result | OK?
Expected | Measured
21 Measure the DC voltages with a 10 kΩ isolating | resistor at the end of the meter probe to prevent oscillations. | E15: -53 mV OIC17: -521 mV +IC18: -15.3 mV OIC18: -153 mV OIC19: +5.0 mV IC20-1: -7.52 V IC20-2: -8.19 V IC20-3: -8.19 V IC20-5: -13.9 V IC20-12: +8.59 V OIC21: +92 mV IC22-12: +9.3 V E32: +102 mV D5-A: +450 mV E31: +48 mV | | OK/NOK
22 - Note: The 1Vrms, 2 kHz signal is still connected to the | input of PCB2. - Connect E26 to scope channel 1. - Sweep the input-frequency and observe the signal at the scope. - Adjust trimpot R62 for a deep notch (less than 10 mVrms). - If R62 doesn’t have enough range, connect E23 to -15V instead of GND. | - A notch should be observed at the center frequency. - A deep notch (< 10 mVrms) should be observed at the center frequency. | | OK/NOK
23 - Change the frequency of the function-generator | until a 100 mVrms (280 mVpp) is shown at E26 (typically a frequency change of a few Hz is sufficient for this). - Use the joystick-buttons on PCB4 to select a sensitivity of 3%. | - 280 mVpp at E26. - IC19 pin 6 = 100 mVrms - IC19 pin 6 = 10 mVrms | | OK/NOK
24 - Connect E32 to the scope channel 1. | - Connect E31 to a multimeter measuring DC-voltage. - Change the amplitude on function generator between +10 dB (* 3) and -10 dB (/ 3), the output reference VCA (E32) = 1.1 Vrms and is independent of the input-level. | - E32 = 1.1 Vrms - E31 = 0 VDC at 1Vrms input - E31 = +3 VDC at 3Vrms input - E31 = -3 VDC bij 0.33Vrms input - E29 remains 100 mVrms | OK/NOK
25 - Change to amplitude of the input-signal to 10 mVrms | (-20 dB). - Change amplitude back to 1 Vrms | E31 converges back to 0VDC within 10 seconds. | OK/NOK

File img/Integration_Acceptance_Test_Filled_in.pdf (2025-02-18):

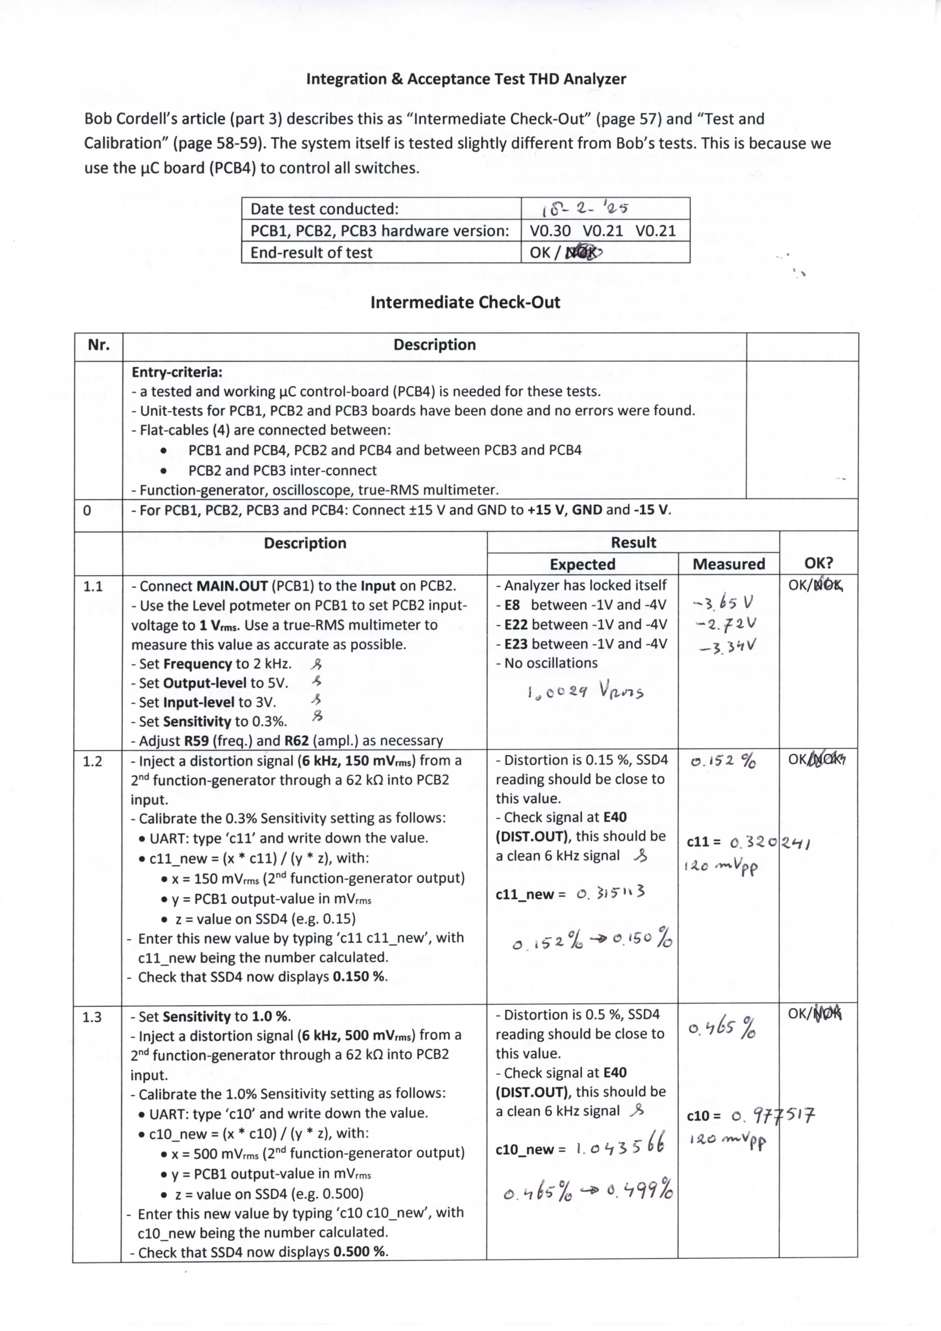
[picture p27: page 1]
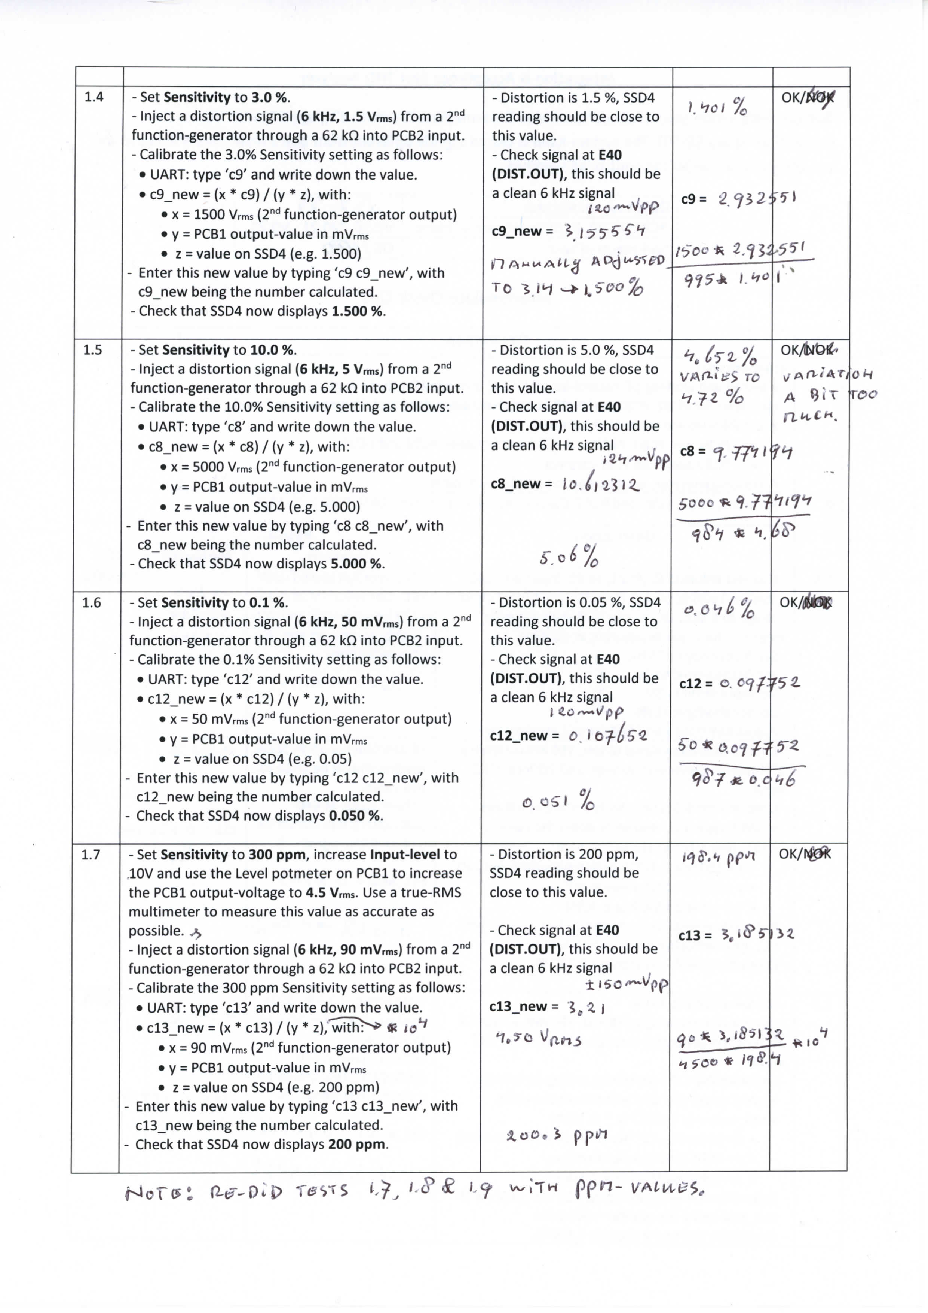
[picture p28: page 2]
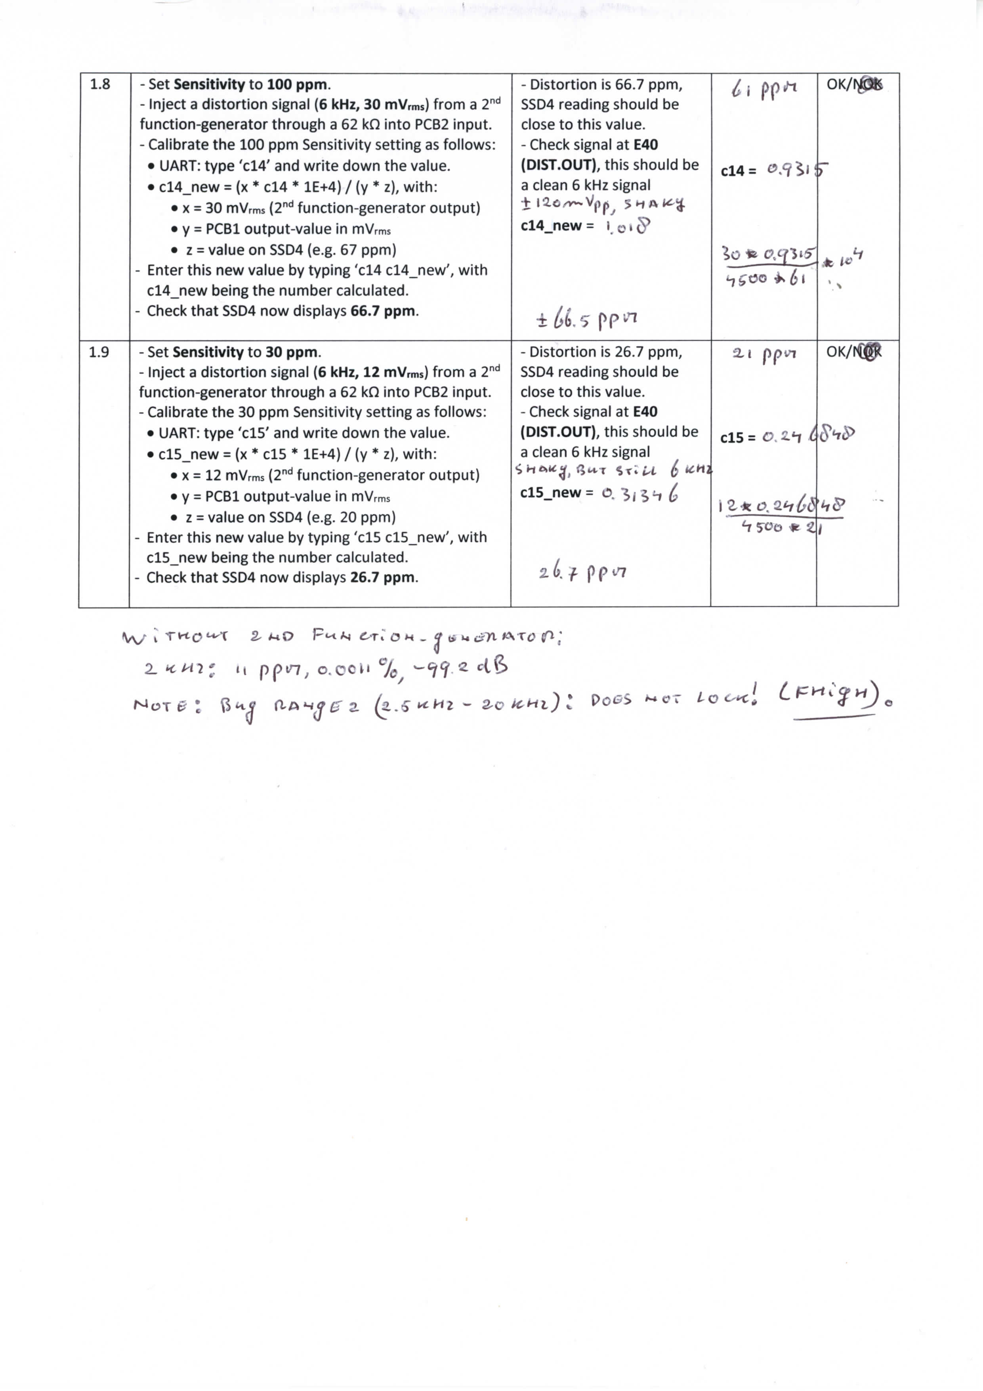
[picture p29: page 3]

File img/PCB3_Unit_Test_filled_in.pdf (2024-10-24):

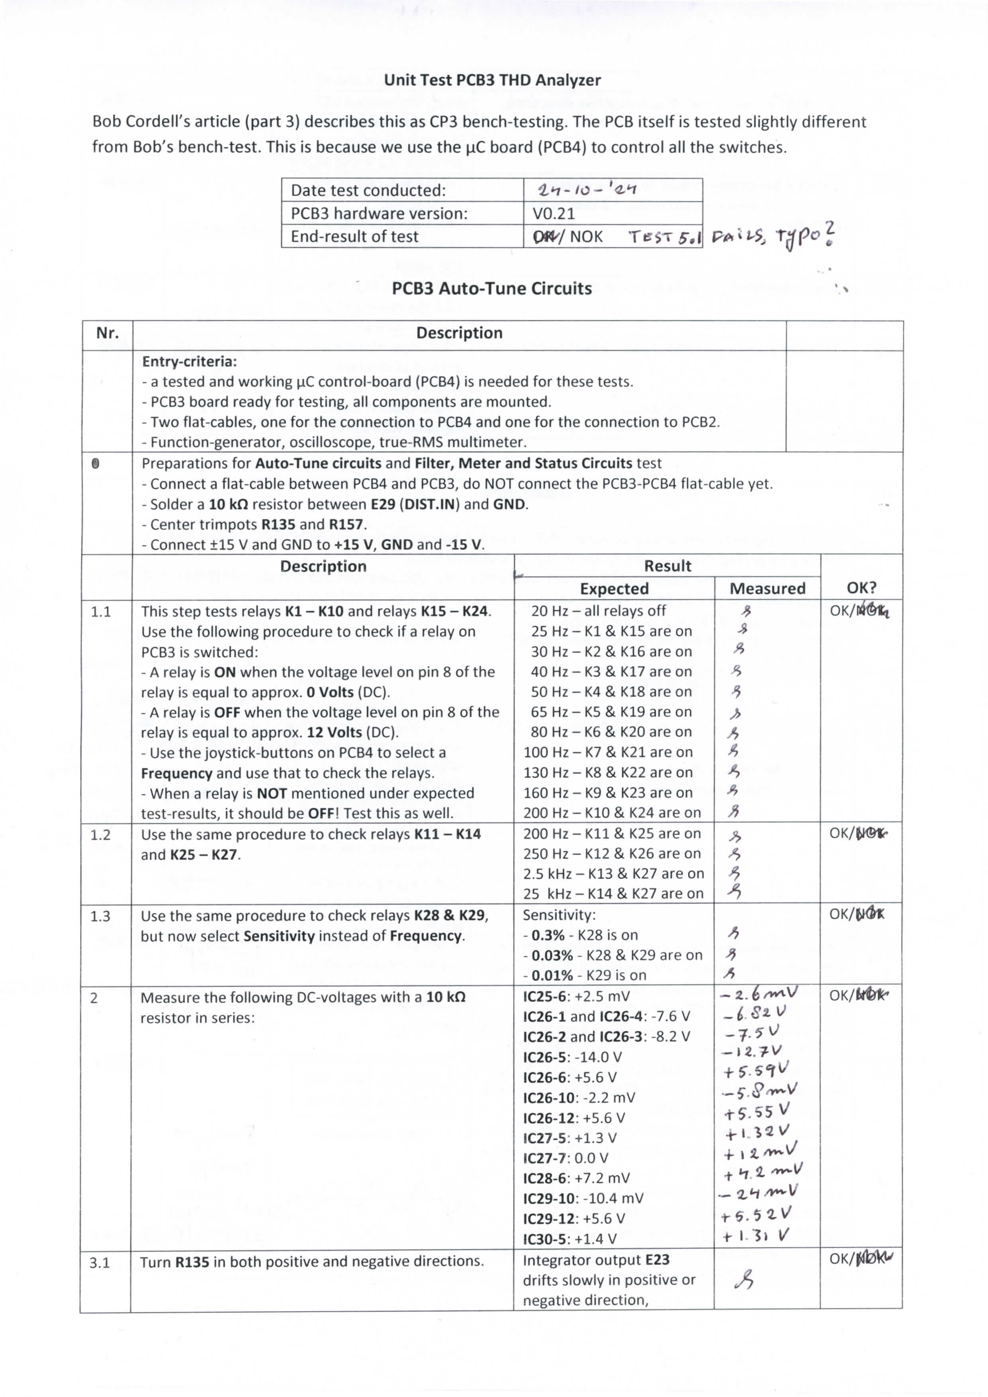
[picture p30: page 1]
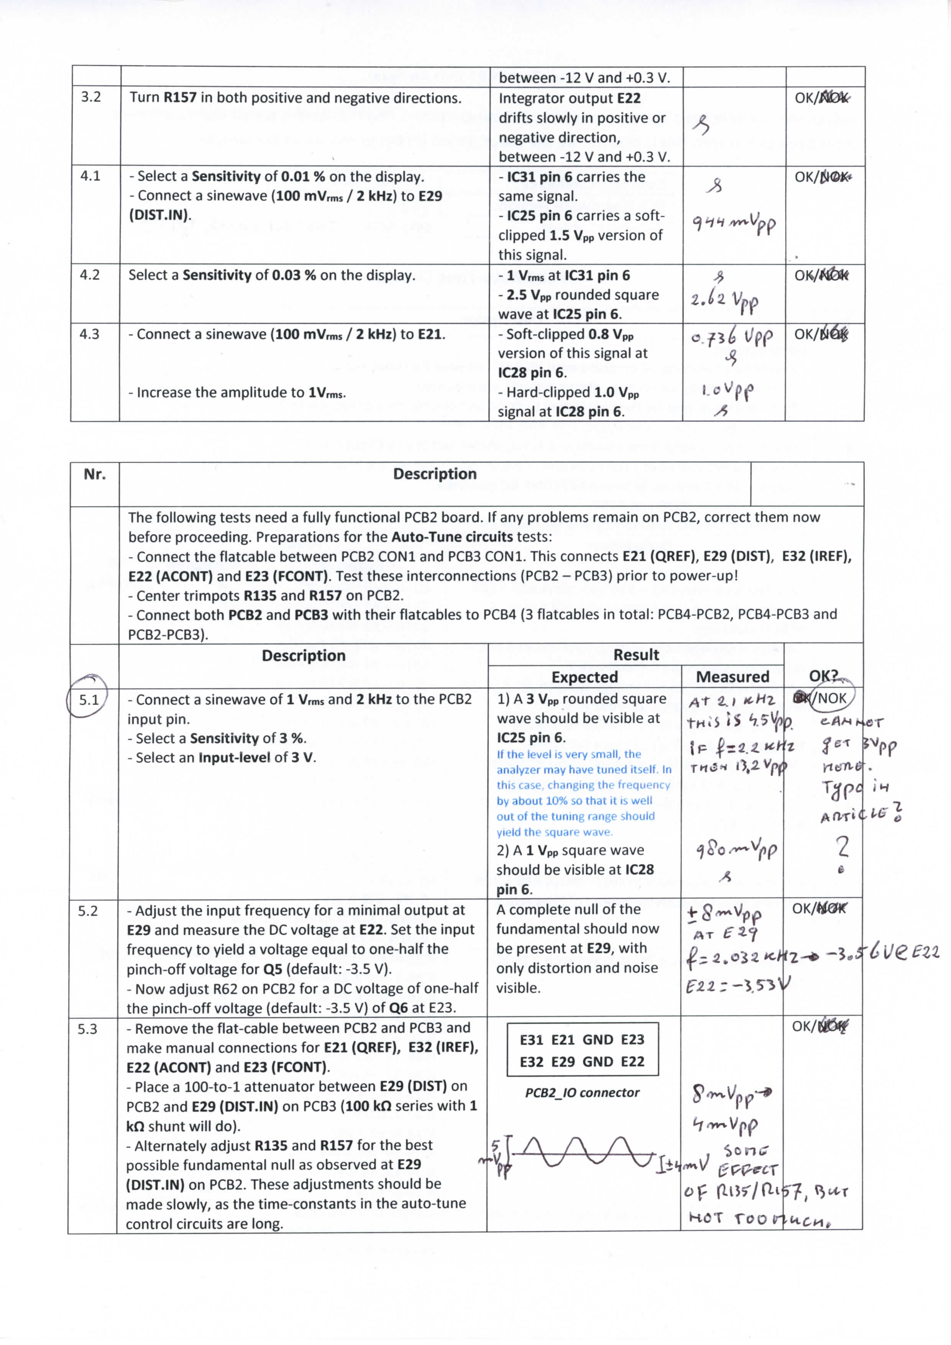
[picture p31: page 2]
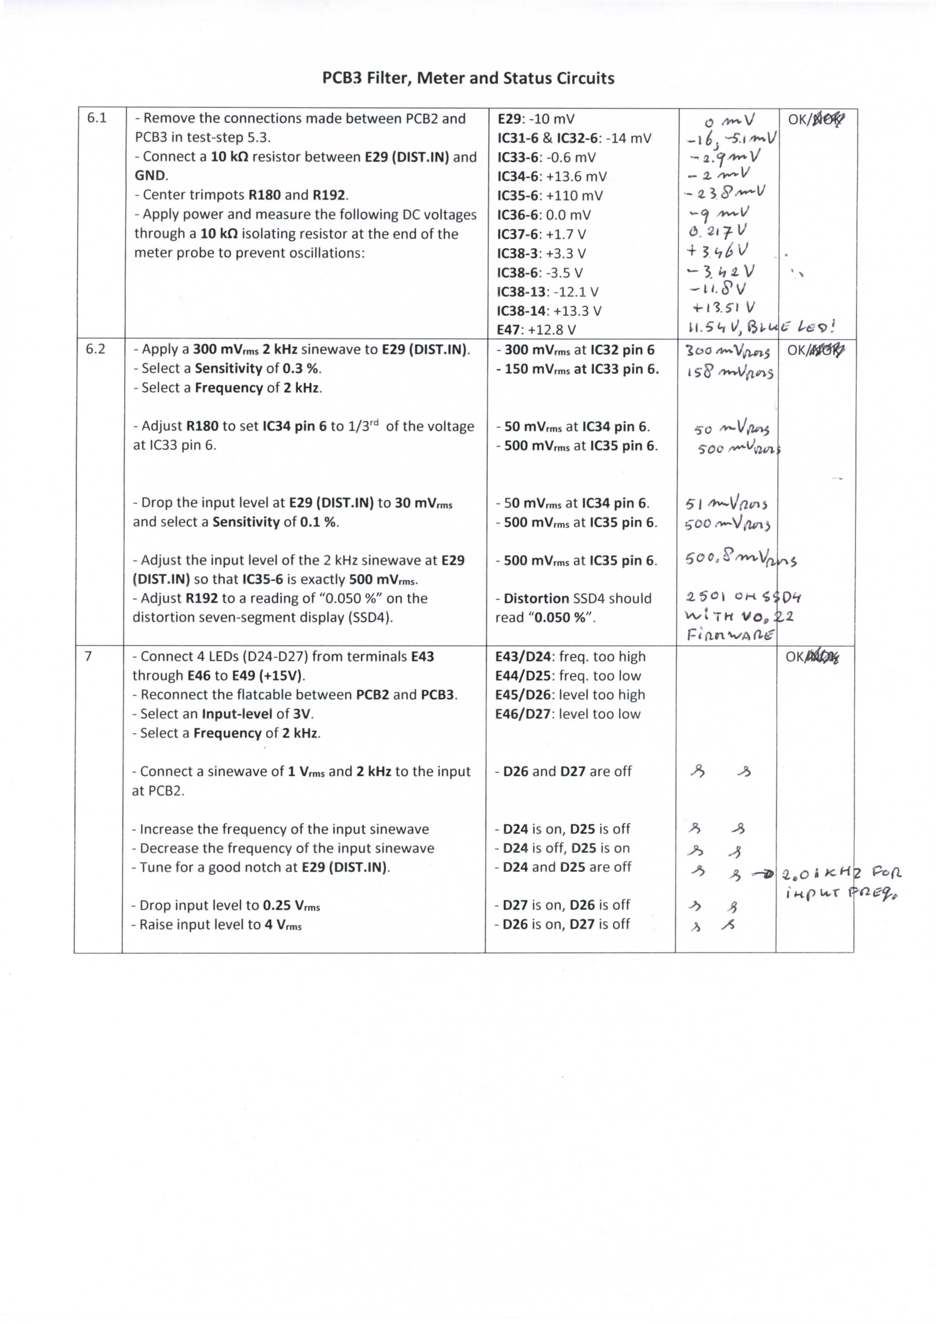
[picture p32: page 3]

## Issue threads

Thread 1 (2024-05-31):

Signal generator issues

bengtssk, 2024-05-31:
Finished the signal generator (PCB 1) today. The 200hz and 20khz range worked as they should and THD was very low too, about 0,0005 % which probably is as low as I can measure.

How ever the 2khz range gave about half of the frequency as it should. And the 200khz distorted heavily and the amplitude was way to high.

I suspect that I got some problem with the RC link network. Using of board caps and resistors connected to e1-e9 (as Bob suggest in the original article to test the board) and only activating NOT OFF relay worked for the 2khz range.

Some more debugging will be done, but I have to asked if you encountered any similar problems?

Emile666, 2024-06-01:
Thanks for debugging this! I am very happy with your THD measurements, it proves that the concept itself works! I had similar issues, especially on the higher frequencies, 2 and 20 kHz). I got it almost completely solved by changing opamps. I had cheap opamps from Aliexpress and by replacing them with originals, most problems were gone, only 200 kHz is not working. So have you used authentic opamps? I will check today if I made other adaptations to PCB1.

bengtssk, 2024-06-01:
I've used original opamps from Digikey only. Only substituted the JFET for J111, since I couldn't get there original. However Vp and rDSon is very similar so I don't think it will be a problem. Didn't thought about speed but 200k is pretty slow for and jFET... but I was just thinking, that FET did you use? Could be a problem for 200k ranges if it's to slow, I'm just speculating now.

Well thanks for a great project. As soon as I get time I'll double check my board again. At least it the issues seems to be narrowed to the two ranges.

Emile666, 2024-06-01:
The changes I made on PCB1 are:
**1)** solder CKM4 (220p) and CLN4(220p) with their resistors as close to the E2-E3 pins and E4-E5 pins as possible, removing them from the current location on the board. Also the resistor values of RKM4 and RLN4 were changed to 330 Ohms instead of 68 Ohms. Don't know if that is still needed, but you could test try that.
**2)** IC2 and IC4 (NE5534) were replaced by an OPA1612 opamp. This is experimental as I was searching why higher frequencies were not working. The OPA1612 has double the slew-rate and 4 times the bandwidth of a NE5534. Don't know if this is still needed now that I have original NE5534s. But I left it in because it worked.

I got several PN4091 from Aliexpress and tested them with a transistortester. Their pinch-off voltage was around -7...-8 Volt. It is pretty easy to see when the generator stops working just by observing the Q1 gate voltage. If it gets close to 0V or -8 Volt, then you know the generator will stop working. With better opamps, the variation of this gate voltage was much less when changing frequencies. The 200 kHz itself should not be a problem, much more crucial are the slew-rate and gain-bandwidth-product in my perception.

bengtssk, 2024-06-02:
1) Did this solve the problem with the 200khz range? I tried that, but it didn't have any effect. What did (almost) work was to increase the capacitance to about 470 pF. Then the oscillator work in the 200kHz range, but with the half frequency of course. Interesting is that _giulianodes_ at diyaudio.com seem to got the same problem with his realization of the oscillator. [https://www.diyaudio.com/community/threads/another-realization-of-bob-cordells-thd-analyzer.165386/post-2261708](url)

2) OPA1611, I guess (the single version). Well it should work with the original NE5534's as well. So I think I'll stick with them.

2N4091, as in the original, are actually available at Mouser, for 13 eur/pcs (!). That's why I substituted them with J111. Tested the bunch of them I bought from Digikey. And Vp was all between -7,5 and -8,5 volt. So that sounds promising, probably not the JFET that is the problem here.

Finally got it working in the 2k range though. Just to dry solder joints (which took forever to find). Works fine now at all frequencies except 200kHz range.

Emile666, 2024-06-03:
1. The 20kHz-200kHz range works fine, only the 200kHz option does not work. I got it working up until 160kHz and thought that would be enough.
2. No, I used the OPA1612 to replace 2 single NE5534. I made an update to PCB1 where both types of opamps can be populated. I will publish that design here shortly, together with the Eagle source files.
3. The J111 will probably be fine, it is a good alternative for the 4091 FET.

Good to hear you got it working!

Emile666, 2024-06-05:
Interesting idea of adding a capacitor across R(E), didn’t think of that. However I tried 10pF and 22pF and both stopped oscillation in the 20kHz range completely! Removing it and I got stable oscillation up to 130 kHz again. I said 160 kHz before, but that is actually 130 kHz, which is fine I think. So only 160 kHz and 200 kHz are not working. Thank you for your valuable feedback!

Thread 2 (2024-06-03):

PCB2 Unit Test issues

Emile666, 2024-06-03:
This is a placeholder for all issues that are found during unit testing of PCB2.

bengtssk, 2024-06-06:
Two questions about the PCB 2;

- what are the rating 600 for L1-L4? Assuming these are SMD ferrite beads in 1206 package. Maybe **600** ohm @ 100Mhz rated beads could work? This seems to be quite a standard rating, available for 20 cents or so.

- What are the purpose of L5 and L7? Assuming these are 1206 SMD coils @ 10uH. Didn't see them in the original article.

Emile666, 2024-06-07:
- I added SMD 1206 ferrites 600 Ohms, don't know if that is at 100 MHz, probably so. Yes, they were cheap.
- Additional power-supply filtering with CLC for the input stage. Might not need it, but I added them anyway, just to be safe.

Emile666, 2024-06-14:
I had an issue with the input stage: the relays (K20..K24) were switching as designed and the 1V (which is the IC9 3x amplifier) and 3V (pass-through) behaved as they should, but as soon as I got to the 10V, 30V and 100V input levels, the signal at E15 was attenuated way too much. In the end I found out that IC17 was defective (signal E15 is also going to the + input of IC17), don't know why it was defective, but it was loading the E15 path too much.

Emile666, 2024-06-17:
Two bugs in PCB2:
- The value of R66 (150k) is not printed completely on the silkscreen, it only shows 150. So if you mount the resistors by following the silkscreen values, you could mount the wrong resistor and the entire bandpass-filter does not work. Also IC16 gets quite hot, which is another indication of having placed a wrong resistor-value.
- E24 has no test-pin, to show this signal on the scope, you have to get to the bottom-layer.

bengtssk, 2024-08-22:
Finished PCB2 and done the bench testing as described by Bob Cordell in the original article. Overall it behaves like it should according to the article. Wave forms looks good at the scope and the filters and amplifier does what them should do. What is different are some voltage levels:

**DC levels;** (what it should be according to article)

Bandpass filter
- OIC10 +0,003 (+1,2)
- OIC11 +0,002 (+1,2)
- OIC12 +0,004 (+4,3)
- OIC13 +0,003 (+0,9)
- OIC14 -0,001 (-5,6)

Amplifier

- +IC18 -0,012 (-15,3)
- OIC22 +14,88 (+0,092)

**Signal levels**

- Not able to get lower than 42mV rms at output E26 while tuning R62, should be less than 10 mV rms.
- OIC19 I get approx 600 mV (and looks very distorted at the scope) should be approx 100mV.

Would be interesting to know if you got the same voltages. Anyway it still does what it should I think (even though some DC voltages are way off) and I cant really understand why right know. So I will proceed and build PCB3 soon.

Btw, E26 is missing a test pin. I solder the 82k resistor underneath the board in order to to the test procedures for product amplifiers and auto-set circuits.

Emile666, 2024-08-23:
I did these tests a couple of times. I could completely eliminate (down to 16 mVpp which was the noise level) the sinewave by tuning R62. I used the PCB4 board and set sensitivy to 0.03%, in that way you can do most of the tests described by Bob. Check the PCB2 Unit test document for details. If you use the uC board and set sensitivity, you don't need E26, you can put E28 on the scope. Maybe the distorted signal is influenced by this? I got a proper signal by using it this way.

OIC12 should be +4.3 mV (not V), I measured 2.5 mV. I made sloppy test-notes, have to do the test again. Was quite happy that it all worked nicely. But I also noticed some DC-voltages to be off.

Have you checked that R66 is 150K and not 150 Ohms? That was my problem initially, the K is missing on the silk-screen.

Bob's original bench-test is a bit confusing at one point: he said to connect E22 and E23 to GND, but then he asks to measure the DC-voltage at E22 and E23, which should be -2.1V and -1.5V. He probably meant the gate-voltages, but don't know that for sure.

bengtssk, 2024-08-25:
Hadn't noticed that you published the test procedure for PCB2 before. So did the bench test again according to your document, great work btw. This test procedure makes much more sense than trying to do it as in the article. Some things I noted though;

6. The relay testing is wrong I think, should be;

25 hz K11 is on
250 hz K12 is on
2k5hz K13 is on
25khz all off

(That's how my board tested and it works)

7. All DC voltages are closed according to your instruction. I'm actually starting to think there's a misprint in the original article, cause in my copy I read +4.3V. I get about 5mV, so probably fine, and you get the same. R81 and R82 is not included at you board, which you probably know. Could that be the reason why we get these voltages instead?

21. Then measuring the DC voltages I noticed that some are greatly influenced by the input. With no input all voltages were closest to yours.

22. Actually managed to get the a deep notch at 4mV this time, measured at E28. Used a better signal generator and "cheated" by adjusting the frequency pot a bit. Had to set the sensitivity to 3% and connect E23 to -15V to even get near 10mV.

Overall I think this is a success, and the test instructions was a very got idea.

Yeah, I knew about R66, thanks to your previous post.

bengtssk, 2024-08-26:
Right again, it says in the footer of table 1 it says "all reading in mV unless noted". So I was wrong. But it also says "measurement at completed unit operating at 1V rms 1khz". So there goes my readings at 12). Anyway, I think we're fine. Building PCB3 right now.

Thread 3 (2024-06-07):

PCB4: frequency measurement does not work well

Emile666, 2024-06-07:
The idea was to measure the actual frequency of the signal generator and to put that on the LCD-display. However it does not work well for small signals and is kind of an hassle to get to work for all output values. In the end I decided to skip the actual frequency measurement (both in HW and SW) and to just display the chosen frequency on the display. This will probably be implemented in V0.15.

bengtssk, 2024-06-07:
Is it possible to make that change "board-compatible", i.e. only change the software, with the earlier version? Already built the PCB but haven't programmed the PIC yet. IAR requires a business email do be downloaded btw, haven't got the time to solve this yet.

Emile666, 2024-06-07:
Yes, SW updates will be backward compatible.

Sorry to hear about IAR, that used to be more flexible. It is very convenient to have a working uC, you can PM me, so we can have this sorted.

Emile666, 2024-07-04:
The frequency detection needs to be redesigned. It needs to work from 20 Hz-200kHz and from 5mV to 5V. I made a couple of LT-Spice simulations and came up with the following design. First the rectified signal is limited by D1 and D2 (for large signals) and then sufficiently amplified (>500x) for the transistor to switch. It works as specified and the output (at collector of Q1) is a 0-5V signal for the uC. It does need a new PCB4 revision, but I wanted to do that anyway. I am probably going to put the selected frequency on the LCD-display (the v0.15 option) and the measured frequency on the seven-segment display. Thanks to [bengtssk](https://github.com/bengtssk) for all the excellent ideas!

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

Emile666, 2024-11-30:
I am going to propose a hardware change: since the SYNC signal has a constant amplitude, approx. 5 Vpp, it is a better input for the frequency-counter than the MAIN.OUT signal. I will probably make an update of the uC PCB (PCB4) in the near future, PCB1 will not get an update anymore. For now, modify the hardware as follows:

**On PCB1 V0.30:**
- Desolder CON3 (UC_IO) box-header
- Use a sharp knife to disconnect pin 1 (bottom right pin as seen from top-layer) from GND on top-layer. There are 3 connections to GND, remove all three of them.
- Same for the 3 connections to GND on the bottom-layer.
- Check for discontinuity between GND and CON3-1 pin.
- Solder CON3 box-header back.
- Solder wire from CON1-SYNC pin to CON3-1.
- Check for discontinuity between GND and CON3-1 pin.

**On uC PCB (PCB4, v0.30):**
- Desolder IC4-14 from its pad and lift it up.
- Solder a wire from CON10-1 (bottom right pin as seen from top-layer, pin next to AD_MAIN pin) to R33 pad next to R32. R32 and R33 are located next to each other, solder the wire to one of the pads in the middle.

Emile666, 2024-12-04:
With the SYNC mod described above and software version V0.26 (d8caa0111f6bea1d36648135a0f9217f8c42cf81) the frequency-counter is working as it should. Therefore I am going to close this issue.

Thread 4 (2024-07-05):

PCB4: Output voltages and ADC1 voltages

Emile666, 2024-07-05:
While checking the output voltages, I got the following values:
5V range: 2.86 Vrms (4.04 Vp)
1.5 V range: 0.97 Vrms (1.37 Vp)
0.5 V range: 0.30 Vrms (424 mVp)
0.15 V range: 93 mVrms (131 mVp)

Bob Cordell probably meant with 5V range a 5Vrms range, meaning 7.1 Vp (14.2 Vpp). I couldn't understand why the voltage levels in this range before and after R38 (620 Ohms) changed from 13 Vpp to 8.4 Vpp. Turns out that, since I measure this output-voltage on PCB4 with a full-bridge rectifier with an input-impedance of 1 K (R10 on PCB4), the output-voltage is 0.6 times the E11 voltage. If I remove the flatcable to PCB4, I get the 13 Vpp value again, which proves my observation.

Bob probably didn't mean this, since he doesn't measure the output-voltage of the signal-generator, as far as I can see.

So what do we want here? I might be inclined to use the output-levels as a peak voltage, so 5V range means that the maximum peak-voltage is 5 V (10 Vpp, 3.54 Vrms). This seems more than enough for testing power-amplifiers (my opinion). Or do we need more and should we stick to Bob's original design? In that case we have to increase the input-impedance of the FWB rectifier on PCB4.

**ADC1 voltage**: IC5 on PCB4 amplifies too much and gets stuck to the rail-voltage (13 V for this opamp, no rail-to-rail). So a max output voltage of 5 V (peak) should be within this range. If we **lower R12 from 150K to 68K**, the max. voltage at IC5 output (pin 6) is now 10.7 V. Ideally, with R192 set half-way, the ADC1 voltage should then be 4.5 V, so it is always lower than the max. allowed voltage (5V). If **R8 is increased from 2k7 to 4k7**, the ADC1 voltage is now adjustable between 3.4 V and 5.3 V. The software should now use a full-scale value of 4.5 V instead of 5.0 V now.

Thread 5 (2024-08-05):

PCB4 v02 issues

bengtssk, 2024-08-05:
Recently finished building PCB 4 version 0.20, and flashed the PIC using the hex-file from /Debug/exe. And it seems to to what it should to (have only tested it with PCB1 so far) and the frequency counter performs better now. But there are some issues what I've discovered;

1. Didn't notice any changes in the software for the micro controller and the LCD still says v0.14. Is is possible that it's the wrong hex file uploaded?

2. Had to change R24 from 4k7 to 6k8 in order to get the RMS reading right.

3. The frequency counter still have problem with signal levels under about 200mV RMS. This was a surprise, cause the detector circuit worked so well in theory, and I'm still not sure why. Looking at the scope pictures below (channel 1 is sync and channel 2 i FREQ) it it clear that at very low input levels the square wave at FREQ i a bit "interrupted". Thus causing the micro controller to trig more than once every cycle. Pictures below is at about 5 mV RMS input. It is not so very visible at higher levels, but I think it's the same phenomena that occurs until about 200mV (but my scope can't show it clearly enough to be sure).

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

Putting a cap of at least 2n2 or so between freq and ground solves the problem, and the frequency counter works again. Problem is that at high frequencies, the output becomes to saw tand-shaped and it stops working again cause the amplitude isn't enough to trigger the input of the micro controller. Below is with a 2n2 cap from FREQ to ground at 5 mV 1khz input.

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

For some reason the counter works better at higher frequencies. I have no idea what causes this "interruption" of the square wave, interference? And nor that the solution may be, some sort of filtering, changing the BC847 to MOSFET? Or are there any software engineering trick to get around this, like increasing the triggering time for the micro controller at low frequencies?

bengtssk, 2024-08-05:
Putting the 2n2 cap between the base of the BC847 and ground may be a better solution. Frequencies counter now works well below 5mV RMS at frequencies up to 65 khz. The duty cycle of the square wave is no longer 50%, but I think it should be enough for the micro controller to trig any way.

1 khz, 2 channel at FREQ:

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

65khz, 2 channel at FREQ:

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

bengtssk, 2024-08-05:
I had the old firmware. Flashed the a new uC using STM8flash and the wrong hex-file. The new version hex-file is located in debug/ExeCB, the comments are wrong btw.

Flashing it with the new firmware solved item 1 and 2. And I like the new firmware too, thanks!

Closed 2024-11-11.

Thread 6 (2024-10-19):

SSD boards causing disturbances

bengtssk, 2024-10-19:
The the SSD modules are multiplexing the LED displays, it sends some voltage dips at the power rail. This voltages dips causes the both the frequency counter to malfunction and the residual distortion to increase. Using separate power supplies for 5 V supply and PCB1-3 boards does not help. The fast voltages spike are transmitted through the ground lead and/or coupled into the signal path anyway. This makes the whole instrument unusable.

My solution is to filter these voltage drop as close to the SSD boards as possible using a CL-filter. Using the circuit shown in the schematic almost completely removes these voltages spikes. Component values may not be so critical, these worked best for me.

The board is made so the SSD TM1637 module can be mounted directly to it, using some 5mm distances. I also chosen to mount two LED's at each boards. These are the indicating LED's for hz, khz, rms, peak-to-peak etc. I prefer to use standard 70mcd LED, which draw a bit more current than I want to load the micro controller with. So a transistor to drive each LED was also added.

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

[SSD-gerbers.zip](https://github.com/user-attachments/files/17446376/SSD-gerbers.zip)
[SSD_PSU_filtering-schematic.pdf](https://github.com/user-attachments/files/17446377/SSD_PSU_filtering-schematic.pdf)

Emile666, 2024-10-20:
Excellent idea! It would definitely solve the problem with the voltage dips. Could I suggest to add the following:
- Have 3 LEDs instead of two, for Vp, Vpp and Vrms? I think the current TM1637 board only uses 4 of the 6 grid pins, so it would be relatively easy to add a couple of LEDs to it (e.g. to the grid 5 pin) and have it controlled by the software, instead of having the LED1, LED2 and LED3 pins. The interface would then be CLK, DIO, VCC and GND, just like it is now. The firmware (file tm1637.c, function tm1637_show_nr_dec_ex()) needs an update to control these LEDs, but that is not too difficult.
- Create one board and desolder both the SSD and the TM1637 from the existing board. The 3 LED solution can then easily be added.
- Add 4 x 3mm corner holes for screwing the PCB to a frontpanel. You probably need to move some components (C1) to the bottom layer in order to mount it.

This is probably the schematic for the existing TM1637 boards, it shows that the grid5 and grid6 are not connected yet:
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

bengtssk, 2024-10-20:
Very interesting idea, using the free grid of the LM1637 to control LED's. If your willing to to the software, I am happy to make a board for this. But it doesn't solve the problem with 3 LED's? One of the board should have 3 LEDs now, RMS, Vp, Vp-p. But the current uC baord doesn't support it anyway (?).

I intended to mount the board(s) using the same 3mm mounting hole that runs through the both boards. Just using some spacing screw and nuts etc...

Emile666, 2024-11-30:
Solved in commit d910e729169950cfd8157a6c08a63e72a2f2400e.

Closed 2024-11-30.

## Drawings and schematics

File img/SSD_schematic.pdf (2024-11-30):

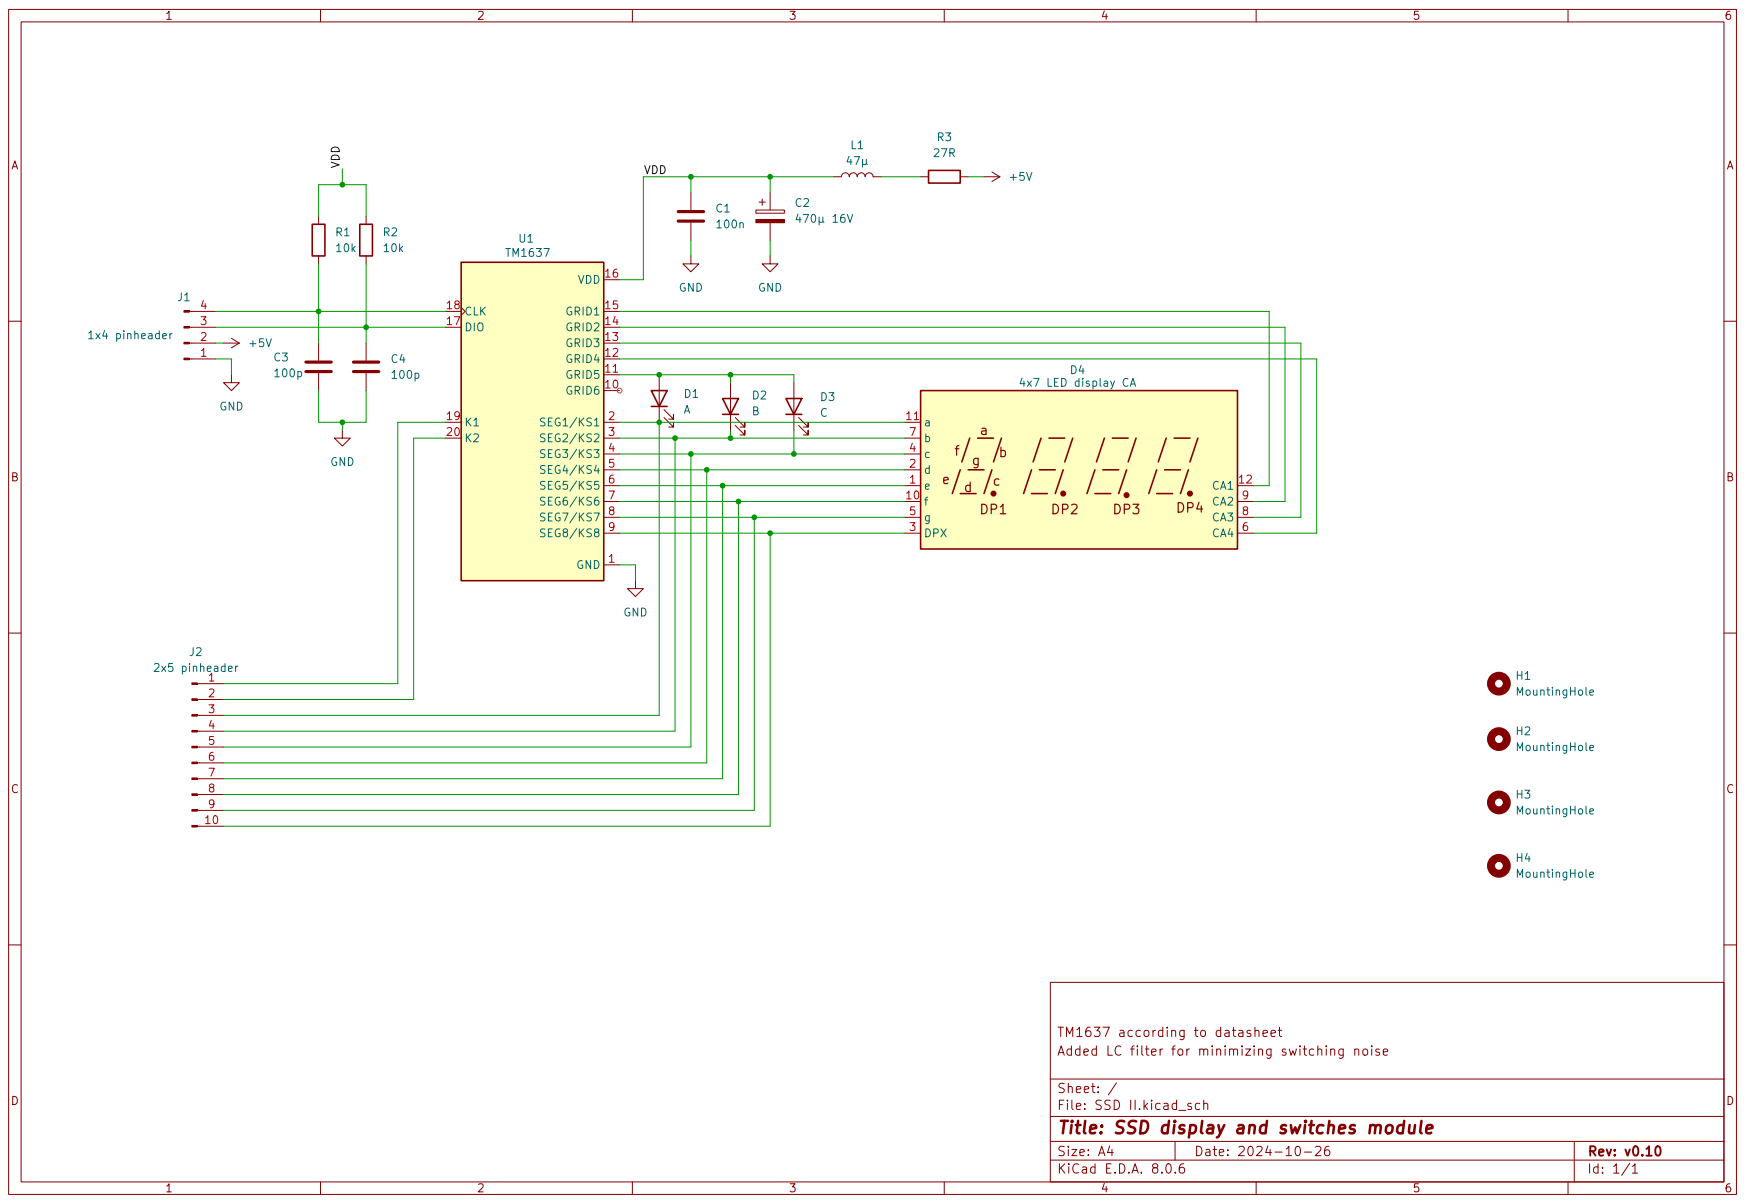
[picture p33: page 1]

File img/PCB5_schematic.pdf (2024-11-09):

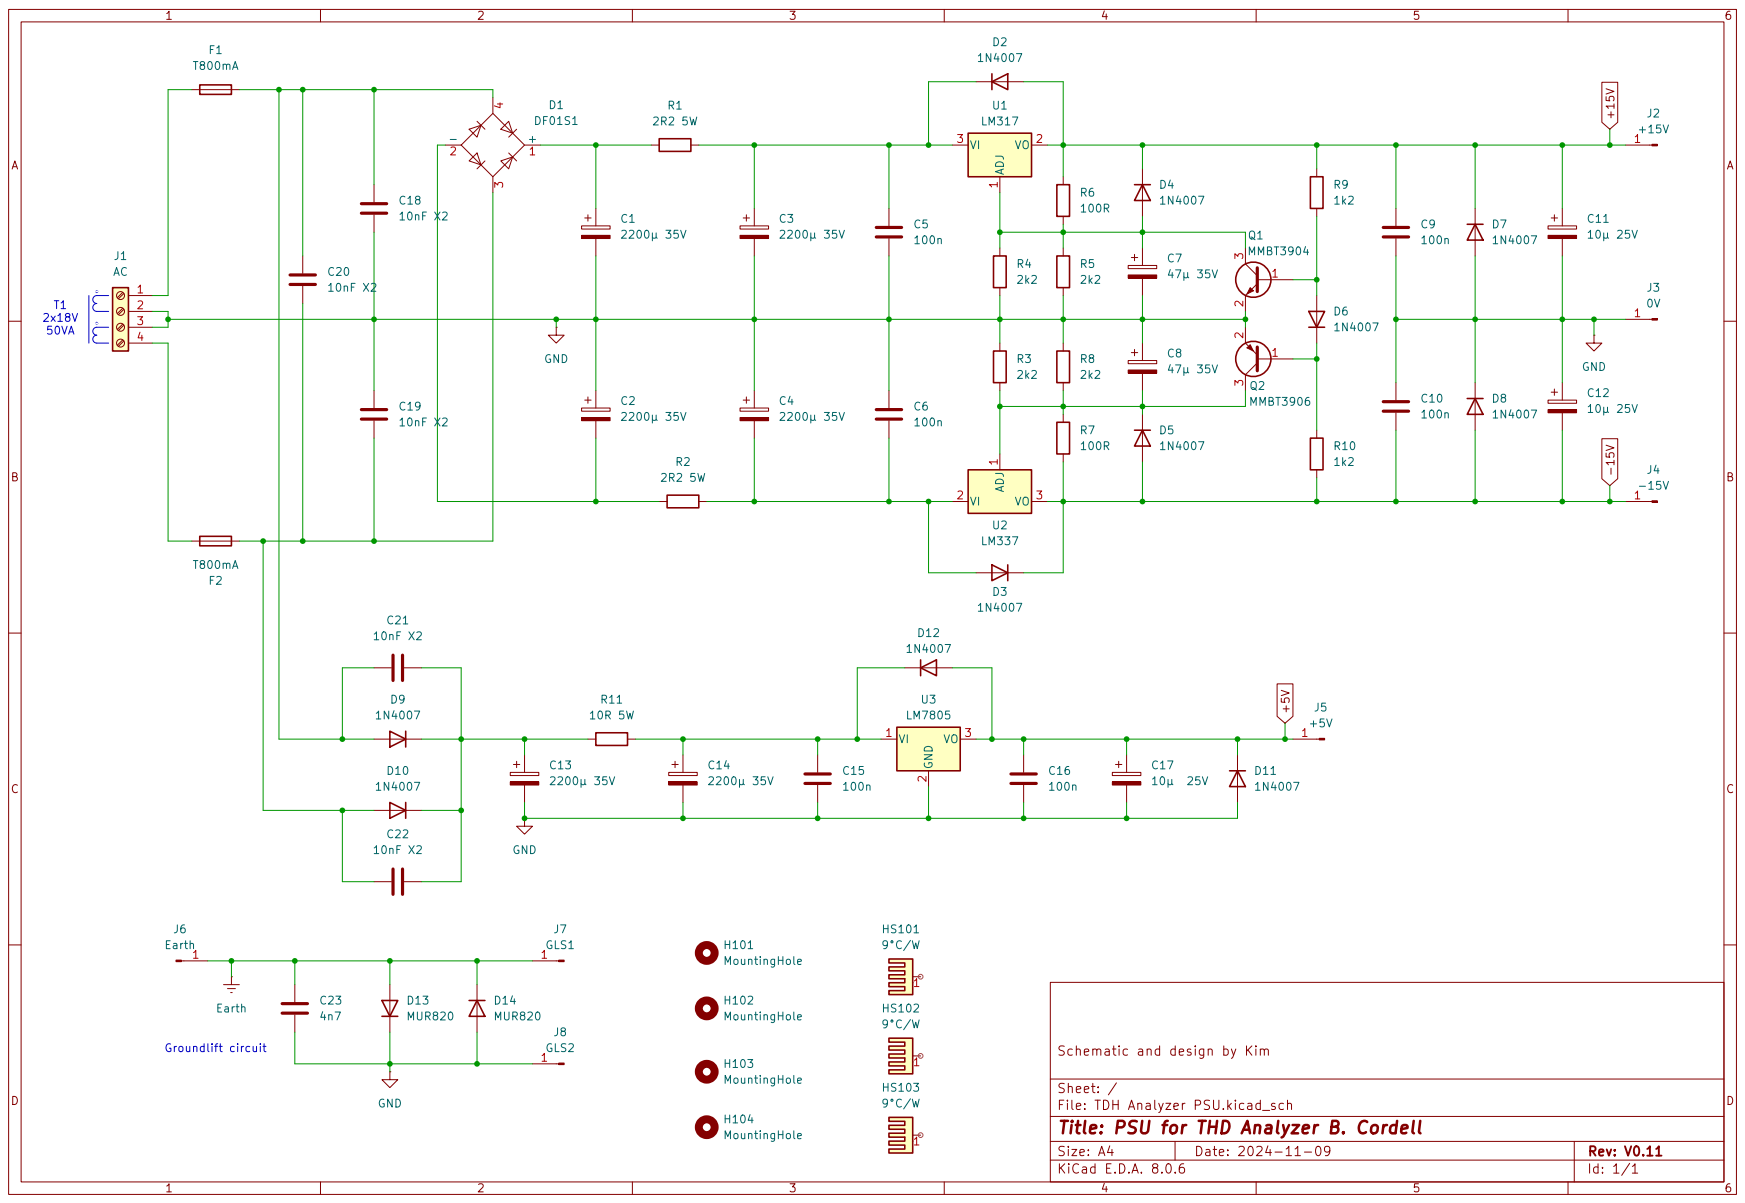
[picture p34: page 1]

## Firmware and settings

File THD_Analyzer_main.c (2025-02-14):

/*==================================================================
  File Name    : THD_Analyzer_main.c
  Author       : Emile
  ------------------------------------------------------------------
  Purpose : This files contains the main() function and all the
            hardware related functions for the STM8S105C6T6 uC.
            It is meant for the THD-Analyzer Control Board (PCB4).
  ------------------------------------------------------------------
  This file is free software: you can redistribute it and/or modify
  it under the terms of the GNU General Public License as published by
  the Free Software Foundation, either version 3 of the License, or
  (at your option) any later version.

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
  You should have received a copy of the GNU General Public License
  along with this file.  If not, see <http://www.gnu.org/licenses/>.
  ==================================================================*/
#include <stdio.h>
#include <stdlib.h>
#include <math.h>
#include "thd_analyzer_main.h"
#include "scheduler.h"
#include "adc.h"
#include "eep.h"
#include "i2c_bb.h"
#include "comms.h"
#include "uart.h"
#include "lcd_i2c.h"
#include "tm1637.h"

// Version number for THD-Analyzer firmware
char version[]          = "THD-Control V0.27";
const char hz[10][3]    = {"20","25","30","40","50","65","80","10","13","16"};

int16_t  lvl_out_adc;   // Sine-wave output level, ADC1
int16_t  lvl_in_adc;    // Input-level, ADC2
int16_t  lvl_dist_adc;  // Distortion level, ADC3
bool     dist_db;       // Distortion level unity [DIST_PERC, DIST_DB]
uint16_t freq_meas;     // Actual measured frequency
uint16_t freq_meas_old; // Previous value of freq_meas
uint8_t  fmt_meas;      // Format for freq_meas

uint8_t  lvl_out = 0;          // [LEVEL_OFF, ..., LEVEL_5V]
uint8_t  lo_old = 0;           // Previous value of lvl_out
uint8_t  lvl_in = 0;           // [INPUT_1V, ..., INPUT_100V]
uint8_t  li_old = 0;           // Previous value of lvl_in
uint8_t  range;                // [RANGE_200_HZ, ..., RANGE_200_KHZ]
uint8_t  sensi = 0;            // [SENS_0_003, ..., SENS_10_000]
uint8_t  sensi_old = 0;        // Previous value of sensi
int8_t   amplitude = VPEAK;    // Amplitude in VPeak
int8_t   brightness = 1;       // Brightness of SSD displays

uint8_t  menustate = STD_IDLE;     // STD number
uint8_t  std_tmr;                  // countdown timer for STD
uint8_t  sweep_tmr;                // timer for frequency sweep
uint8_t  fsweep = FREQ_20_HZ;      // current sweep frequency

uint8_t  freq_sine = 0;            // [FREQ_20_HZ, ..., FREQ_200_KHZ]
uint8_t  freq_save = 0;            // freq_sine value just before sweep mode
uint8_t  freq_old = 0;             // Previous value of freq_sine
uint32_t pcb1_bits = 0L;           // 32 bits for PCB1 Shift-registers
uint32_t pcb2_bits = 0L;           // 32 bits for PCB2 Shift-registers
uint16_t pcb3_bits = 0x0000;       // 16 bits for PCB3 Shift-registers

float  lvl_in_c100;                // conversion constant for 100V input level
float  lvl_in_c30;                 // conversion constant for  30V input level
float  lvl_in_c10;                 // conversion constant for  10V input level
float  lvl_in_c3;                  // conversion constant for   3V input level
float  lvl_in_c1;                  // conversion constant for   1V input level

float  sensi_10c;                  // Sensitivity 10% constant
float  sensi_3c;                   // Sensitivity 3% constant 
float  sensi_1c;                   // Sensitivity 1% constant
float  sensi_c3;                   // Sensitivity 0.3% constant
float  sensi_c1;                   // Sensitivity 0.1% constant
float  sensi_c03;                  // Sensitivity 300 ppm constant
float  sensi_c01;                  // Sensitivity 100 ppm constant
float  sensi_c003;                 // Sensitivity 30 ppm constant

uint16_t buttons_aux1;             // Previous and Actual value of TM1637 navi-keys
uint16_t buttons_aux2;             // Previous and Actual value of TM1637 aux keys

extern char     rs232_inbuf[];
extern uint16_t buttons;           // Previous and Actual value of navi-keys

/*-----------------------------------------------------------------------------
  Purpose  : This function sets the Range of the sine-wave generator.
  Variables: r: range parameter
  Returns  : -
  ---------------------------------------------------------------------------*/
void set_range(uint8_t r)
{
    range = r;                           // save range parameter
    pcb1_bits &= ~(uint32_t)RANGE1_MASK; // clear bits for RANGE
    pcb2_bits &= ~(uint32_t)RANGE_MASK;  // clear bits for RANGE
    pcb3_bits &= ~(uint16_t)RANGE_MASK;  // clear bits for RANGE
    switch (r)
    {
        case RANGE_200_HZ:
            pcb1_bits |= RANGE1_200_HZ_MASK; /* PCB1 has more RANGE bits */
            pcb2_bits |= RANGE_200_HZ_MASK;
            pcb3_bits |= (uint16_t)RANGE_200_HZ_MASK;
            break;
        case RANGE_2_KHZ:
            pcb1_bits |= RANGE1_2_KHZ_MASK;  /* PCB1 has more RANGE bits */
            pcb2_bits |= RANGE_2_KHZ_MASK;
            pcb3_bits |= (uint16_t)RANGE_2_KHZ_MASK;
            break;
        case RANGE_20_KHZ:
            pcb1_bits |= RANGE1_20_KHZ_MASK;  /* PCB1 has more RANGE bits */
            pcb2_bits |= RANGE_20_KHZ_MASK;
            pcb3_bits |= (uint16_t)RANGE_20_KHZ_MASK;
            break;
        default: // 200 kHz, not on PCB2
            pcb1_bits |= RANGE_200_KHZ_MASK; /* same for PCB1 and PCB3 */
            pcb3_bits |= (uint16_t)RANGE_200_KHZ_MASK;
            break;
    } // switch
} // set_range()

/*-----------------------------------------------------------------------------
  Purpose  : This function sets the Frequency of the sine-wave generator.
  Variables: freq: frequency index [FREQ_20_HZ .. FREQ_200_KHZ]
             send: [NOSEND,SEND]
  Returns  : -
  ---------------------------------------------------------------------------*/
void set_frequency(uint8_t freq, bool send)
{
    uint8_t f = freq;

    if (f < FREQ_250_HZ)
    {   // 20 Hz .. 200 Hz
        set_range(RANGE_200_HZ);
    } // if
    else if (f < FREQ_2500_HZ)
    {   // 250 Hz .. 2 kHz
        set_range(RANGE_2_KHZ);
        f -= FREQ_200_HZ;
    } // else if
    else if (f < FREQ_25_KHZ)
    {   // 2.5 kHz .. 20 kHz
        set_range(RANGE_20_KHZ);
        f -= FREQ_2000_HZ;
    } // else if
    else
    {   // 25 kHz .. 200 kHz
        set_range(RANGE_200_KHZ);
        f -= FREQ_20_KHZ;
    } // else
    pcb1_bits &= ~(uint32_t)FREQ_MASK; // clear all frequency bits
    pcb2_bits &= ~(uint32_t)FREQ_MASK; // clear all frequency bits
    pcb3_bits &= ~(uint16_t)FREQ_MASK; // clear all frequency bits
    if (freq > FREQ_20_HZ)
    {   // 20 Hz requires all relays to be off, all other freqs should be switched
        pcb1_bits |= (1L << (f-1)); // switch proper relay PCB1
        pcb2_bits |= (1L << (f-1)); // switch proper relay PCB2
        pcb3_bits |= (1  << (f-1)); // switch proper relay PCB3
    } // if
    freq_sine = freq;          // save frequency set
    if (send) send_to_hc595(); // send to hardware
} // set_frequency()

/*-----------------------------------------------------------------------------
  Purpose  : This function sets the Output Level of
             the sine-wave generator on PCB1.
  Variables: lvl:  output level index [LEVEL_OFF .. LEVEL_5V]
             send: [NOSEND,SEND]
  Returns  : -
  ---------------------------------------------------------------------------*/
void set_output_level(uint8_t lvl, bool send)
{
    pcb1_bits &= ~(uint32_t)LEVEL_MASK; // clear all level bits
    lvl_out = lvl;
    switch (lvl)
    {
        case LEVEL_0V15:
            pcb1_bits |= LEVEL_0V15_MASK;
            break;
        case LEVEL_0V50:
            pcb1_bits |= LEVEL_0V50_MASK;
            break;
        case LEVEL_1V50:
            pcb1_bits |= LEVEL_1V50_MASK;
            break;
        case LEVEL_5V:
            pcb1_bits |= LEVEL_5V_MASK;
            break;
        default:             // LEVEL_OFF, all bits 0, including the !OFF bit
            PC_CR2_FREQ = 0; // disable freq. meas. to prevent IRQ overloads
            break;
    } // switch
    if (send) send_to_hc595(); // send to hardware
} // set_output_level()

/*-----------------------------------------------------------------------------
  Purpose  : This function sets the Input Level for PCB2.
  Variables: lvl:  input level index [INPUT_1V .. INPUT_100V]
             send: [NOSEND,SEND]
  Returns  : -
  ---------------------------------------------------------------------------*/
void set_input_level(uint8_t lvl, bool send)
{
    lvl_in = lvl;
    if (lvl <= INPUT_100V)
    {
        pcb2_bits &= ~(uint32_t)INPUT_MASK; // clear all level bits
        pcb2_bits |= (1L << (19 + lvl));
    } // if
    if (send) send_to_hc595(); // send to hardware
} // set_input_level()

/*-----------------------------------------------------------------------------
  Purpose  : This function sets the Sensitivity Level in % for PCB2 and PCB3
  Variables: send:  sensitivity level index [SENS_0_003 .. SENS_10_000]
             send: [NOSEND,SEND]
  Returns  : -
  ---------------------------------------------------------------------------*/
void set_sensitivity(uint8_t sens, bool send)
{
    sensi = sens;
    pcb2_bits &= ~(uint32_t)SENS_MASK_PCB2; // clear all sensitivity bits
    pcb3_bits &= ~(uint16_t)SENS_MASK_PCB3; // clear all sensitivity bits
    switch (sens)
    {
        case SENS_0_003: // 0.003 %
            pcb2_bits |= SENS_0_003_MASK;
            break;
        case SENS_0_010: // 0.01 %
            pcb2_bits |= SENS_0_010_MASK;
            break;
        case SENS_0_030: // 0.03 %
            pcb2_bits |= SENS_0_030_MASK;
            break;
        case SENS_0_100: // 0.1 %
            pcb2_bits |= SENS_0_100_MASK;
            break;
        case SENS_0_300: // 0.3 %
            pcb2_bits |= SENS_0_300_MASK;
            break;
        case SENS_1_000: // 1 %
            pcb2_bits |= SENS_1_000_MASK;
            break;
        case SENS_3_000: // 3 %
            pcb2_bits |= SENS_3_000_MASK;
            break;
        default: // SENS = 10 %
            pcb2_bits |= SENS_10_000_MASK;
            break;
    } // switch
    if (sens < SENS_0_300) pcb3_bits |= SENS_LT_0_300;
    if (sens > SENS_0_010) pcb3_bits |= SENS_GT_0_010;
    if (send) send_to_hc595(); // send to hardware
} // set_sensitivity()

/*-----------------------------------------------------------------------------
  Purpose  : This function sends the bit-settings to the HC595 shift-registers
             on the 3 PCBs of the THD Analyzer.
  Variables: -
  Returns  : -
  ---------------------------------------------------------------------------*/
void send_to_hc595(void)
{
    uint32_t colmask  = 0x00000001;  // start with bit 0 to send to shift-register
    uint16_t colmask3 = 0x0001;      // bit-mask for PCB3 shift-register
    uint8_t i = 0;

    //-------------------------------------------------------------------
    // Since PCB3 contains fewer shift-register bits than PCB1 and PCB2,
    // we first start by shifting the extra bits to PCB1 and PCB2. These
    // bits are shifted out again by the PCB3 shift-register.
    //-------------------------------------------------------------------
    while (i < MAX_BITS12 - MAX_BITS3)
    {   // shift bits to HC595 shift-registers
        SDIN1b    = (pcb1_bits & colmask) ? 1 : 0;
        SDIN2b    = (pcb2_bits & colmask) ? 1 : 0;
        SDIN3b    = 0; // dummy
        SHCPb     = 1; // set clock for shift-register;
        colmask <<= 1; // select next bit
        SHCPb     = 0; // set clock to 0 again
        i++;
    } // while
    colmask3 = 0x0001;
    while (i < MAX_BITS12)
    {   // shift MAX_BITS3 bits to all HC595 shift-registers
        SDIN1b     = (pcb1_bits & colmask)  ? 1 : 0;
        SDIN2b     = (pcb2_bits & colmask)  ? 1 : 0;
        SDIN3b     = (pcb3_bits & colmask3) ? 1 : 0;
        SHCPb      = 1; // set clock for shift-register;
        colmask  <<= 1; // select next bit for PCB1 and PCB2
        colmask3 <<= 1; // select next bit for PCB3
        SHCPb      = 0; // set clock to 0 again
        i++;
    } // while
    // Now clock bits from shift-registers to output-registers
    STCPb     = 1; // set clock to 1
    colmask <<= 1; // small delay
    STCPb     = 0; // set clock to 0 again
} // send_to_hc595()

/*-----------------------------------------------------------------------------
  Purpose  : This function is called every 500 msec. from adc_task() and
             calculates the output level to display on SSD 2. This output-level
             is only dependent of amplitude (VRMS, VPEAK or VPP).
  Variables: *dp   : the code for the decimal-point on SSD1
              *leds: which led to display: LED_VPP, LED_VPK, LED_VRMS.
  Returns  : the input-level to display on SSD 3.
  ---------------------------------------------------------------------------*/
uint16_t calc_output_level(uint8_t *dp, uint8_t *leds)
{
    float x = (float)read_adc(ADC1); // read value from ADC1
    
    switch (amplitude)
    {
      case VRMS:
        x        *= ADC1_FS_VRMS;
        VPK_LEDb  = 0;
        VRMS_LEDb = 1;
        *leds     = LED_VRMS;
        break;
      case VPEAK:
        x        *= ADC1_FS_VPK;
        VPK_LEDb  = 1;
        VRMS_LEDb = 0;
        *leds     = LED_VPK;
        break;
      default: // VPP
        x        *= ADC1_FS_VPP;
        VPK_LEDb  = 1; // both leds to 1 for now
        VRMS_LEDb = 1;
        *leds     = LED_VPP;
        break;
    } // switch
    if (x > 9999.5)
    {
      *dp  = DP2;   // dp for 1x.yy number format
       x  *= 0.1;   // divide by 10
    } // if
    else *dp = DP1; // dp for 1.yyy number format
    return (uint16_t)(x + 0.5);
} // calc_output_level()

/*-----------------------------------------------------------------------------
  Purpose  : This function is called every 500 msec. from adc_task() and
             calculates the input level to display on SSD 3. This input-level
             is dependent of amplitude (VRMS, VPEAK or VPP) and which input
             level is selected (100V, 30V, 10V, 3V or 1V).
  Variables: *leds: which led to display: LED_VPP, LED_VPK, LED_VRMS.
  Returns  : the input-level to display on SSD 3.
  ---------------------------------------------------------------------------*/
uint16_t calc_input_level(uint8_t *dp)
{
      float x = (float)read_adc(ADC2);
      
      switch (amplitude)
      {
         case VRMS: x *= ADC2_FS_VRMS; break;
         case VPP : x *= ADC2_FS_VPP ; break;
         default  : x *= ADC2_FS_VPK ; break; // Vpeak
      } // switch
      switch (lvl_in)
      {
          case INPUT_100V: x *= lvl_in_c100; break;
          case INPUT_30V : x *= lvl_in_c30 ; break;
          case INPUT_10V : x *= lvl_in_c10 ; break;
          case INPUT_1V  : x *= lvl_in_c1  ; break;
          default        : x *= lvl_in_c3  ; break; // pass-through
      } // switch      
    if (x > 9999.5)
    {
      *dp  = DP2;   // dp for 1x.yy number format
       x  *= 0.1;   // divide by 10
    } // if
    else *dp = DP1; // dp for 1.yyy number format
    return (uint16_t)(x + 0.5);
} // calc_input_level()

/*-----------------------------------------------------------------------------
  Purpose  : This function is called every 500 msec. from adc_task() and
             calcuates the distortion level to display on SSD 4. This level
             is dependent of dist_db (DIST_PERC, DIST_DB) and which sensitivity
             level is selected (10%, 3%, 1%, 0.3%, 0.1%, 0.03%, 0.01% and 0.003%).
  Variables: *dp: the code for the decimal-point on SSD4.
             *leds: which led to display: LED_DB, LED_PPM, LED_PERC.
  Returns  : the number to display on SSD 4
  ---------------------------------------------------------------------------*/
int16_t calc_dist_level(uint8_t *dp, uint8_t *leds)
{
      float x   = (float)read_adc(ADC3);
      bool  ppm = (sensi < SENS_0_100); // ppm for lowest distortion levels
      
      switch (sensi)
      {
          case SENS_10_000: x *= sensi_10c ; break; // 9.999 %
          case SENS_3_000 : x *= sensi_3c  ; break; // 3.000 %
          case SENS_1_000 : x *= sensi_1c  ; break; // 1.000 %
          case SENS_0_300 : x *= sensi_c3  ; break; // 0.300 %
          case SENS_0_100 : x *= sensi_c1  ; break; // 0.100 %
          case SENS_0_030 : x *= sensi_c03 ; break; // 300.0 ppm
          case SENS_0_010 : x *= sensi_c01 ; break; // 100.0 ppm
          default         : x *= sensi_c003; break; //  30.0 ppm
      } // switch      
      if (dist_db == DIST_DB)
      {   // display dB number as '-xx.y'
          *dp   = DP3;    // set decimal-point for dB numbers
          *leds = LED_DB; // light dB LED next to SSD4
          if (x > 0.0) 
               x =   200.0 * log10f(x) - (ppm ? 1400.0 : 1000.0);
          else x = -1200.0; // -120 dB
          if (x <= -1000.0) 
          {   // no decimal-point for number <= -100 dB
              x  *= 0.1;    // display dB as '-1xx'
              *dp = DP_OFF; // no decimal-point
          } // if
      } // if
      else if (ppm) { *dp = DP3; *leds = LED_PPM;  } // set dp & LED for ppm
      else          { *dp = DP1; *leds = LED_PERC; } // set dp & LED for %
      return (int16_t)x;
} // calc_dist_level()

/*-----------------------------------------------------------------------------
  Purpose  : This task is called every 500 msec. and reads the following
             analog signals:
             AIN1: Output Level of generated sine-wave
             AIN2: Input Level
             AIN3: Distortion Level
  Variables: -
  Returns  : -
  ---------------------------------------------------------------------------*/
void adc_task(void)
{
    uint8_t dots = DP1;     // dp for 1.xxx number format
    uint8_t leds = LED_OFF; // Seven-segment display is off by default
    
    //--------------------------------------------------------------------
    // Output-level display on SSD1, depends on amplitude selection. The 
    // Vpp, Vrms and Vpeak LEDs (leds) are set by calc_output_level().
    //--------------------------------------------------------------------
    lvl_out_adc = calc_output_level(&dots,&leds); 
    tm1637_set_brightness(SSD_LVL_OUT, brightness, true); // SSD brightness
    tm1637_show_nr_dec_ex(SSD_LVL_OUT, lvl_out_adc, dots, true, 4, 0, leds);

    //--------------------------------------------------------------------
    // Input-level display on SSD3, depends on both selected input-level
    // and amplitude selection. The Vpp, Vrms and Vpeak LEDs (leds) are 
    // the same as for the output-level.
    //--------------------------------------------------------------------
    lvl_in_adc  = calc_input_level(&dots); 
    tm1637_set_brightness(SSD_LVL_IN, brightness, true); // SSD brightness
    tm1637_show_nr_dec_ex(SSD_LVL_IN, lvl_in_adc, dots, true, 4, 0, leds);

    //--------------------------------------------------------------------
    // Distortion display on SSD4, depends on both selected sensitivity and
    // unity (dB, % or ppm). The ppm unity is selected for percentages < 0.1%.
    //--------------------------------------------------------------------
    lvl_dist_adc = calc_dist_level(&dots,&leds);
    tm1637_set_brightness(SSD_DIST, brightness, true); // SSD brightness
    tm1637_show_nr_dec_ex(SSD_DIST, lvl_dist_adc, dots, true, 4, 0, leds);
} // adc_task()
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
int main(void)
{
    char    s[30];  // Needed for xputs()

    __disable_interrupt();
    initialise_system_clock();    // Use internal system-clock (16 MHz)
    uart_init();                  // UART1 init. to 57600,8,N,1
    setup_timer2(FREQ_1KHZ);      // Set Timer 2 for 1 kHz interrupt frequency
    setup_gpio_ports();           // Init. needed output-ports
    i2c_init_bb();                // Init. I2C bus for bit-banging

    // Initialise all tasks for the scheduler
    scheduler_init();                    // clear task_list struct
    add_task(adc_task ,"ADC",  0, 500);  // every 500 msec.
    add_task(freq_task,"FRQ", 50, 200);  // every 200 msec.
    add_task(ctrl_task,"CTL",200, 100);  // every 100 msec.
    __enable_interrupt();
    lcd_i2c_init(0x4E,20,4,LCD_5x8DOTS); // Needs working interrupts!
    lcd_i2c_clear();
    lcd_i2c_setCursor(0,0);
    lcd_i2c_backlight_on();

    xputs(version); // print version number
    xputs("\n");
    eep_init(true); // init eeprom values
    
    set_frequency(FREQ_1000_HZ,  NOSEND); // starting frequency
    set_output_level(LEVEL_1V50, NOSEND); // 1.5V output-level
    set_input_level(INPUT_100V,  NOSEND); // 100V input-level
    set_sensitivity(SENS_10_000, SEND);   // 10% sensitivity input

    setup_timer1(FREQ_1000_HZ);           // Init. frequency measurement
    
    while (1)
    {   // background-processes
        dispatch_tasks();     // Run task-scheduler()
        switch (rs232_command_handler()) // run command handler continuously
        {
            case ERR_CMD: xputs("Cmd Err\n"); break;
            case ERR_NUM: sprintf(s,"Num Err (%s)\n",rs232_inbuf);
                          xputs(s);
                          break;
            default     : break;
        } // switch
    } // while
} // main()

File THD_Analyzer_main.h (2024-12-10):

/*==================================================================
  File Name    : THD_Analyzer_main.h
  Author       : Emile
  ------------------------------------------------------------------
  This is the header file for THD_Analyzer_main.c, which is the main-body
  for the control board of the THD Analyzer.
  This version is made for the STM8S105C6T6 uC.

  This file is part of the THD-Analyzer project.
  ------------------------------------------------------------------
  This is free software: you can redistribute it and/or modify
  it under the terms of the GNU General Public License as published by
  the Free Software Foundation, either version 3 of the License, or
  (at your option) any later version.

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
  You should have received a copy of the GNU General Public License
  along with this file.  If not, see <http://www.gnu.org/licenses/>.
  ==================================================================*/
#ifndef __THD_ANALYZER_MAIN_H__
#define __THD_ANALYZER_MAIN_H__

#include "stm8s105.h"
#include "stm8_hw_init.h"
#include <stdint.h>
#include "delay.h"

#define MAX_BITS12 (24) /* 3 x HC595 = 24 bits for PCB1 and PCB2 */
#define MAX_BITS3  (16) /* 2 x HC595 = 16 bits for PCB3 */

#define NOSEND (false) /* do NOT send to HC595 */
#define SEND   (true)  /* send bits to HC595 hardware */

//--------------------------------------------------------------------------
// The first 14 bits have the same meaning on every PCB:
// Bit 13: 1 = Range 200 kHz        Bit 06: 1 = freq 100 Hz
// Bit 12: 1 = Range  20 kHz        Bit 05: 1 = freq  80 Hz
// Bit 11: 1 = Range   2 kHz        Bit 04: 1 = freq  65 Hz
// Bit 10: 1 = Range 200  Hz        Bit 03: 1 = freq  50 Hz
// Bit 09: 1 = freq  200  Hz        Bit 02: 1 = freq  40 Hz
// Bit 08: 1 = freq  160  Hz        Bit 01: 1 = freq  30 Hz
// Bit 07: 1 = freq  130  Hz        Bit 00: 1 = freq  25 Hz
//--------------------------------------------------------------------------
// The other bits in pcb1_bits are meant for PCB1 and have the following meaning:
// Bit 23: 1 = LVL 1.5 V or 5 V     Bit 18: not used
// Bit 22: 1 = LVL 0.5 V            Bit 17: not used
// Bit 21: 1 = LVL 0.15 V           Bit 16: Range  20 kHz
// Bit 20: 1 = LVL != OFF           Bit 15: Range   2 kHz
// Bit 19: 1 = LVL 5 V              Bit 14: Range 200  Hz
//--------------------------------------------------------------------------
// The other bits in pcb2_bits are meant for PCB2 and have the following meaning:
// Bit 23: 1 = INP 100 V              Bit 18: 1 = SENS 0.1%, 1% or 10%
// Bit 22: 1 = INP 30 V               Bit 17: 1 = SENS 0.03%, 0.3% or 3%
// Bit 21: 1 = INP 10 V               Bit 16: 1 = SENS 0.01 %
// Bit 20: 1 = INP 3 V                Bit 15: 1 = SENS 0.003 %
// Bit 19: 1 = INP 1 V                Bit 14: 1 = SENS < 3 %
//--------------------------------------------------------------------------
// The bits in pcb3_bits are meant for PCB3 and have the following meaning:
// Bit 15: 1 = SENS < 0.3 %           Bit 14: 1 = SENS > 0.01 %
//--------------------------------------------------------------------------

// The RANGE mask is the same for every PCB,
// but PCB1 has some additional RANGE bits.
#define RANGE_200_HZ        (0)
#define RANGE_2_KHZ         (1)
#define RANGE_20_KHZ        (2)
#define RANGE_200_KHZ       (3)
#define RANGE_200_HZ_MASK   (0x00000400)
#define RANGE_2_KHZ_MASK    (0x00000800)
#define RANGE_20_KHZ_MASK   (0x00001000)
#define RANGE_200_KHZ_MASK  (0x00002000) /* same for alle PCBs */
#define RANGE_MASK          (0x00003C00)
#define RANGE1_200_HZ_MASK  (0x00004400)
#define RANGE1_2_KHZ_MASK   (0x00008800)
#define RANGE1_20_KHZ_MASK  (0x00011000)
#define RANGE1_MASK         (0x0001FC00)

#define FREQ_20_HZ    (0) /* RANGE 200 Hz */
#define FREQ_25_HZ    (1)
#define FREQ_30_HZ    (2)
#define FREQ_40_HZ    (3)
#define FREQ_50_HZ    (4)
#define FREQ_65_HZ    (5)
#define FREQ_80_HZ    (6)
#define FREQ_100_HZ   (7)
#define FREQ_130_HZ   (8)
#define FREQ_160_HZ   (9)
#define FREQ_200_HZ  (10)
#define FREQ_250_HZ  (11) /* RANGE 2 kHz */
#define FREQ_300_HZ  (12)
#define FREQ_400_HZ  (13)
#define FREQ_500_HZ  (14)
#define FREQ_650_HZ  (15)
#define FREQ_800_HZ  (16)
#define FREQ_1000_HZ (17)
#define FREQ_1300_HZ (18)
#define FREQ_1600_HZ (19)
#define FREQ_2000_HZ (20)
#define FREQ_2500_HZ (21)  /* RANGE 20 kHz */
#define FREQ_3000_HZ (22)
#define FREQ_4000_HZ (23)
#define FREQ_5000_HZ (24)
#define FREQ_6500_HZ (25)
#define FREQ_8000_HZ (26)
#define FREQ_10_KHZ  (27)
#define FREQ_13_KHZ  (28)
#define FREQ_16_KHZ  (29)
#define FREQ_20_KHZ  (30)
#define FREQ_25_KHZ  (31) /* RANGE 200 kHz */
#define FREQ_30_KHZ  (32)
#define FREQ_40_KHZ  (33)
#define FREQ_50_KHZ  (34)
#define FREQ_65_KHZ  (35)
#define FREQ_80_KHZ  (36)
#define FREQ_100_KHZ (37)
#define FREQ_130_KHZ (38)
#define FREQ_160_KHZ (39)
#define FREQ_200_KHZ (40)
#define FREQ_MASK    (0x000003FF)
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

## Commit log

2022-05-14 Other schematics and PCB layouts added
2022-05-26 Schematics + PCB Layout update
2022-05-28 First commit with source files for PCB4 v0.10
    Source files added, PCBs are due to arrive next week, so this version can be used to test PCB4 hardware. It contains UART (57600,8N1) and LCD-display functionality. This version also includes frequen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
2022-06-04 V0.11: First working version on V0.10 control HW
    Working: i2c-lcd display, Seven Segment Display (SSD), UART
    Note: the I2C display needs a 100 pF capacitor to GND in order for the i2c-lcd display to work (rise-time is too high for the PCF8574 if not present).
    [THD_Analyzer_main.c, THD_Analyzer_main.h, delay.c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]
2022-06-16 V0.12: ctrl_task() state machine + read_buttons() added
    Input buttons now work, they control the state-machine, which is the first line of the LCD-display. Frequency, input-level, output-level and sensitivity can now be set with the input-buttons.
2022-06-19 README update, mainly PCB4 uC
    Description of source-files and user-interface added. LCD-display picture added.
2023-10-22 V0.13: working with prototype signal generator
    - Switching R and C now works
    - LCD display works
    - Frequency and amplitude measurement now on SS displays
    The signal generator only works until 13 kHz before it locks up, not software related.
2024-06-12 Documentation update
    - Unit test protocol for PCB1 added
    - UART-communications details added to PCB4 page
    - .hex file added
2024-06-12 STVP added to pcb4.md
    Programming PCB4 can be done with STVP-STM8, a project file is added.
    [THD_Analyzer_stm8s105.stp]
2024-06-13 Update pcb4.md
    CON1-CON4 connections added.
2024-06-26 PCB2 Unit-test document added
2024-07-10 PCB1 and PCB4 new PCB versions
    New hardware PCBs made for PCB1 and PCB4. Updated schematics, gerber files and design files.
2024-07-24 V0.16: support for SDCC & Codeblocks added
    Building the firmware can now be done with the SDCC compiler integrated in the Codeblocks IDE. Biggest change is the addition of stm8s105.h, which contains all register definitions.
    Functional changes:
    - Vpp is added to Vp and Vrms selection.
    - OK button now exits the Vp/Vrms/Vpp screen.
2024-07-30 V0.17: various changes
    - ADC1 full-scale values added for new PCB4 version (v0.20).
    - Amplitude adjustment now works fine.
    - calc_freq() still does not work well, below 120 Hz frequency readings are doubled, probably HW related. Frequencies above 2 kHz are not always measured.
    [THD_Analyzer_main.c, THD_Analyzer_main.h, delay.c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]
2024-08-12 V0.19: frequency counter improvements
    There are disturbances caused by the seven-segment displays. Better power-supply decoupling and separate power-supply for these SSDs improve the signal. The frequency counter has also been made more 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
2024-08-29 V0.20: SSD3 and SSD4 outputs enabled
    This is not tested yet! For debugging purposes, SSD3 and SSD4 are enabled and now show input level voltage and distortion in mV.
    There are no proper readings (in V or %) yet, the voltage on the ADC gets displayed, where 5000 mV roughly corresponds to 5000 on the display.
2024-09-16 V0.21: bugfixes SSD displays
    Two bugs found by bengtssk:
    - SSD1 overflow if output-level > 9999 mV.
    - SSD3/SSD4 not reading > 4000 mV.
    [THD_Analyzer_main.c]
2024-10-21 V0.22: SSD display updates and bug-fixes.
    - Bugfix SSD3 and SSD4 displays were reversed
    - Added leds option for TM1637 SSDs to display individual leds. This is needed for the new SSD PCBs that have LEDs mounted next to the SSD.
    - Added input level constants that are stored in eeprom. They can be changed with the c0..c4 commands. Input-level display on SSD3 is now fully functional.
    - Bug-fix: during power-up, frequency counter interrupts are disabled, so that software always starts.
    [THD_Analyzer_main.c, THD_Analyzer_main.h, comms.c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]
2024-10-24 PCB3 Unit-Test description added
    Also a completely filled-in version added.
2024-10-27 V0.23: SSD4 now also in dB + eeprom storage
    - ppm mode selected instead of % for low-number sensitivities
    - Amplitude selection (Vpp, Vpk, Vrms), distortion unity (dB, %) and SSD brightness (1-7) now also stored in eeprom.
    - Sensitivity full-scale constants now also stored in eeprom
    - Menu extended with Brightness adjustment
    - eep_init() function added
    - UART e0 command added for init epprom + cold reboot
    [THD_Analyzer_main.c, THD_Analyzer_main.h, comms.c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]
2024-11-09 Create pcb5.md
    test
2024-11-11 update readme.md file
    Reference to pcb5.md added
2024-11-11 V0.24: bug-fix LEVEL_OFF setting
    When LEVEL_OFF was selected for output-level, the uC would lock-up because of a 175 kHz oscillation present at the FREQ input. Disabling this interrupt solved this.
    Other bug: a calibration constant with number > 9 was not read in, this is corrected.
    [THD_Analyzer_main.c, THD_Analyzer_main.h, comms.c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]
2024-11-11 V0.24: with some minor bug-fixes
    [THD_Analyzer_main.c]
2024-11-11 PCB1 Unit-Test updated
    Also a filled-in version of the Unit-Test is added.
2024-11-24 V0.25: Reading keys from TM1637
    - Reading keys through TM1637 PCB J2 connector
    - New keys added: FP10, FM10, PPPKRMS and DBPERC
    - Schematic added how to connect frontpanel keys to TM1637 J2 connector
    - Updated pcb4.md file with Keys explanation
2024-11-30 Block-diagram update
    - LEDs added to SSDs.
    - SYNC is now also an input for PCB4.
2024-12-04 V0.26: Bug-fix frequency-counter
    - For frequencies > 2 kHz, the prescaler was set to 0, but this was only used after an UEV update event (e.g. a roll-over of Timer1). A software UEV is now created to use the prescaler value immediately.
    - The frontpanel design is also added.
    [THD_Analyzer_main.c, stm8_hw_init.c]
2024-12-10 V0.27: bug-fixes keys and input-level
    - No-key-pressed timer in menu was not working properly with the newly added keys from the TM1637. Corrected.
    - Input-level > 10 V was not displayed properly. Corrected.
    [THD_Analyzer_main.c, THD_Analyzer_main.h, stm8_hw_init.h]
2025-02-14 BOM added
    [BOM.xlsx]
2025-03-03 PCB4 BOM update + SYNC MOD description added
    [BOM.xlsx]
